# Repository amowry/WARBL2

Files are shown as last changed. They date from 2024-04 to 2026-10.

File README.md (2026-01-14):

## WARBL2 is an open-source USB MIDI and BLE MIDI wind controller.

Please see the web site for more info:

https://warbl.xyz

To power the WARBL on, plug into USB or click button 3 (lowest button).

To manually power off the WARBL while under battery power, you can click the reset button (or use a button action assigned in the Configuration Tool, which by default is a long-press of button 3).

For updating the firmware, typical users would just hold down button 1 while plugging the WARBL in to USB and then drag/drop the supplied .uf2 file to the drive named WARBLBOOT. If the WARBL is already plugged in, you can also double-click the reset button to enter the bootloader mode. The most recent flash.uf2 file is located in the build/adafruit.nrf52.warbl2 directory.
 
Advanced users can use the Arduino IDE to modify and upload the code. Modify the code at your own risk and note that while modifying the battery management code won't have dangerous results it could result in reducing the lifespan of the battery.

### How to use WARBL2 with the Arduino IDE:

#### Install Arduino IDE

* Install / run the latest version of the Arduino IDE. [You can download the latest version of the Arduino IDE here](https://www.arduino.cc/en/Main/Software).

* In Linux, the Arduino IDE requires that you be part of the `dialout` group to successfully detect and write to hardware (see [here](https://support.arduino.cc/hc/en-us/articles/4401874331410#ser_open-permission-denied)). If running `id` in a terminal does not list `dialout` as one of the groups your user belongs to, [run `sudo usermod -a -G dialout $USER`](https://support.arduino.cc/hc/en-us/articles/360016495679-Fix-port-access-on-Linux), then log out and back in. Running `id` should now include the `dialout` group.

#### Editing and uploading the WARBL firmware

*  I used the Adafruit ItsyBitsy NRF52840 Express for prototyping WARBL, so the easiest way to set up the IDE is to install the Adafruit boards package, [following the instructions here](https://learn.adafruit.com/adafruit-itsybitsy-nrf52840-express/arduino-support-setup).

* Download the WARBL2 code from this repository (I recommend using the most recent *release* code, *NOT* the current main branch), and move the boards.local.txt file from the "firmware" directory into the directory on your machine that contains the boards.txt file for the Adafruit NR52 boards, typically found here:
   
   * Windows: `C:\Users\(username)\AppData\Local\Arduino15\packages\adafruit\hardware\nrf52\1.6.0` 
   
   * Linux: `/home/(username)/.arduino15/packages/adafruit/hardware/nrf52/1.6.0`
     
   * Mac: ` ~/LibraryArduino15/packages/adafruit/hardware/nrf52/1.5.0/`

*	Now open the warbl2_firmware.ino sketch that you saved in your sketchbook folder.
  
*	In the Tools menu select: Board: > Adafruit nRF52 > WARBL2

*	Next, you’ll need to install libraries included in the sketch that aren’t installed by default. To install them, go to Sketch > Include Library > Manage Libraries, then search for the name of each, one at a time. Then it will give you an option to install each one.

*	Then turn on “show verbose ouput" for both "compile" and "upload" under File > Preferences. Now, click the upload button and check that it compiles without errors. 

*	Then, when it tries to upload, you should see this message at the bottom of the screen:

`Waiting for upload port...`

*	IF the WARBL currently has a "Release" version of the firmware (see below), you'll then have to use a toothpick to double-click the reset button to enter programming mode. The LED pulse in blue and the code should upload, which will take several seconds. If the LED doesn’t light or blinks rapidly, try again. If the IDE stops trying to upload, click “Upload” again, and try double-clicking again. It can take a few tries to get the timing right. If you've loaded a non-release version then the serial CDC port will be active and the firmware upload should proceed without having to first double-click the reset button.

### A few additional notes:
The serial CDC class on WARBL needs to be turned off to make it a USB MIDI class-compliant device. This also means that you won't be able to use the serial monitor in Arduino IDE, and you'll have to double-click the programming button to install firmware (as described above). To turn serial back on, you can comment out the following line in the sketch:

`#define RELEASE //Uncomment for release version (turns off CDC)`

Turning on CDC makes it easier to debug and makes it so uploads should proceed automatically.

Have fun!

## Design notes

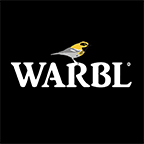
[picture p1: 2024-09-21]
webconfig/img/warbl-app-144x144.png

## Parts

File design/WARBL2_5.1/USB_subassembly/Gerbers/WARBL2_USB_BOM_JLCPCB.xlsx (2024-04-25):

Comment | Designator | Footprint
USB4145-03-0070-C_REVA | J2 | USB4145-03-0070-C_REVA

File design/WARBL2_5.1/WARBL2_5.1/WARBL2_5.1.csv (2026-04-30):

Comment | Designator | Footprint | JLCPCB Part # | Manufacturer Part # | DigiKey Part #
4.7 uF | C1,C4,C9,C10 | C_0603_1608Metric | C19666 | C1608X7S1A475K080AC | 445-14258-2-ND
0.1 uF | C2,C3,C8,C12,C13,C14,C15,C18 | C_0603_1608Metric | C14663 | CL10F104ZB8NNNC | 1276-1012-2-ND
22 uF | C6,C7 | C_0603_1608Metric | C59461 | C1608X5R1A226M080AC | 445-9077-2-ND
1uF | C11,C19,C20 | C_0603_1608Metric | C15849 | CL10B105KP8NNNC | 1276-1946-2-ND
0.01 uF | C16,C17 | C_0603_1608Metric | C57112 | CL10B103KB8NNNC | 1276-1009-2-ND
ESDA7P60-1U1M | D1 | ESDA7P601U1M | C1975146 | ESDA7P60-1U1M | 497-16253-2-ND
BAT54C | D2 | SOT-23 | C181200 | BAT54C | 1655-BAT54CTR-ND
1N4148 | D3 | D_SOD-323 | C2128 | 1N4148WS | 1655-1N4148WSTR-ND
LED_RGB | D4 | LED_LiteOn_LTST-C19HE1WT | C5289911 | APTF1616SEJ3ZGGVBDC | 754-2166-2-ND
ECMF02-2AMX6 | IC1 | QFN-6L_STM | C2651144 | ECMF02-2AMX6 | 497-10773-2-ND
1286AS-H-2R2M 2.2uH | L1 | INDC2016X120N | C412023 | 1286AS-H-2R2M=P2 | 490-10605-2-ND
1 uH | L2 | L_0603_1608Metric | C370016 | LQM18PZ1R0MCHD | 490-15979-2-ND
RU1J002YNTCL | Q1,Q2 | SOT-323_SC-70 | C2842817 | RU1J002YNTCL | RU1J002YNTCLTR-ND
5.1K | R1,R2,R3,R4 | R_0603_1608Metric | C23186 | ERJ-3EKF5101V | P5.10KHTR-ND
10k | R5,R23 | R_0603_1608Metric | C25804 | ERJ-3GEYJ103V | P10KGTR-ND
100k | R6,R12,R13 | R_0603_1608Metric | C25803 | ERJ-3GEYJ104V | P100KGTR-ND
36k 1% | R7 | R_0603_1608Metric | C100994 | ERJ-3EKF3602V | P36.0KHTR-ND
470K | R8 | R_0603_1608Metric | C23178 | ERJ-3GEYJ474V | P470KGTR-ND
100 | R9,R14 | R_0603_1608Metric | C22775 | ERJ-3GEYJ101V | P100GTR-ND
470 | R10,R11 | R_0603_1608Metric | C23179 | ERJ-3GEYJ471V | P470GTR-ND
2k | R15,R16,R17,R18,R19,R20,R21,R22 | R_0603_1608Metric | C22975 | ERJ-3GEYJ202V | P2.0KGTR-ND
2.74k 1% | R25 | R_0603_1608Metric | C321827 | ERJ-3EKF2741V | P2.74KHTR-ND
47k 1% | R26 | R_0603_1608Metric | C25819 | ERJ-3EKF4702V | P47.0KHTR-ND
Tact switch | SW1,SW2,SW3 | TL3305BF160QG | C2689518 | PTS647SM50SMTR2LFSTR-ND | PTS647SM50SMTR2LFSTR-ND
RESET | SW4 | SW_KMR221GLFS | C221675 | KMR211GLFS | 401-1426-2-ND
NCU18XH103F60RB | TH1 | R_0603_1608Metric | C440252 | NCU18XH103F60RB | 2259-TH11-3H103FTTR-ND
M24128-BFMH6TG EEPROM | U1 | UFDFPN5_1P7X1P4_STM | C222091 | M24128-BFMH6TG | 497-17565-2-ND
LSM6DSOXTR IMU | U2 | LGA-14L_2P5X3X0P83_STM | C481766 | LSM6DSOXTR | 497-18367-2-ND
SLG59M1551V Load switch | U3 | VLGA-4_2x2.5mm_P1.65mm | C17446756 | SLG59M1551V | 1827-1074-2-ND
TPS613221ADBV 3.3V boost | U4 | DBV0005A_L | C2070813 | TPS613221ADBVT | 296-49467-2-ND
BQ25172DSGR | U5 | WSON8_DSG008A_BQ_TEX | C5189434 | BQ25172DSGR | 296-BQ25172DSGRTR-ND
TPS7A2030PDBVR | U6 | DBV0005A_L | C963429 | TPS7A2030PDBVR | 296-TPS7A2030PDBVRTR-ND
ISP1807-LR-RS | U7 | ISP1807-LR-RS | C5264268 | ISP1807-LR-RS | 1786-1019-2-ND
74AUP1G32 | U8 | DSF6 | C2682134 | SN74AUP1G32DSFR | 296-27310-2-ND
TPS62237DRYR | U9 | DRY0006A | C398923 | TPS62237DRYR | 296-39454-2-ND
ATmega32U4-MU | U18 | QFN-44-1EP_7x7mm_P0.5mm_EP5.2x5.2mm | C112161 | ATMEGA32U4-MUR | ATMEGA32U4-MURTR-ND
MMC5603NJ Magnetometer | U19 | WLP-4_0.86x0.86mm_P0.4mm
8 Mhz CSTNE8M00GH5L000R0 | Y1 | CSTNE8M00GH5L000R0_MUR | C882602 | CSTNE8M00GH5L000R0 | 490-17962-2-ND

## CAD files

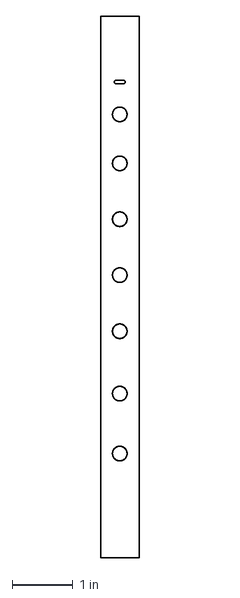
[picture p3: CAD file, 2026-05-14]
design/WARBL2_rev.5.1_top_hole_spacing.dxf
0.625 x 8.90 in

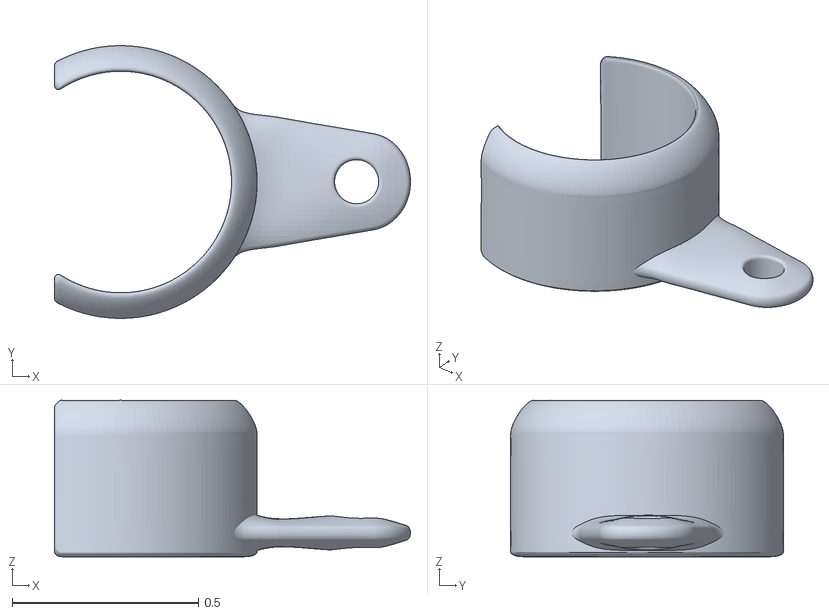
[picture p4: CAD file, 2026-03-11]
design/WARBL_offset_thumbrest_1.0.stl
0.956 x 0.733 x 0.42

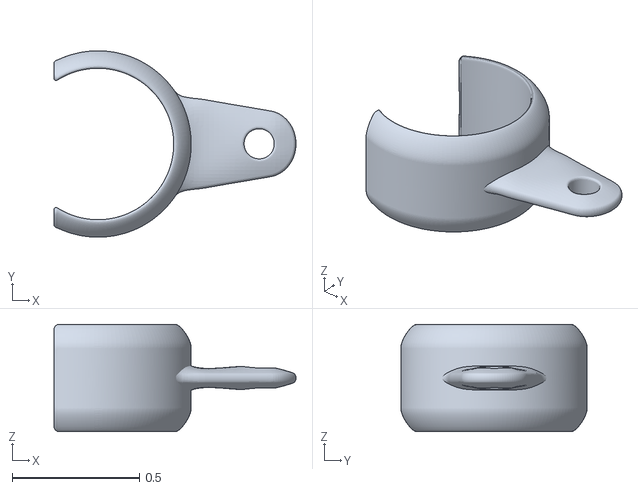
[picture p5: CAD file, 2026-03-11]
design/WARBL_thumbrest_1.0.stl
0.951 x 0.733 x 0.421

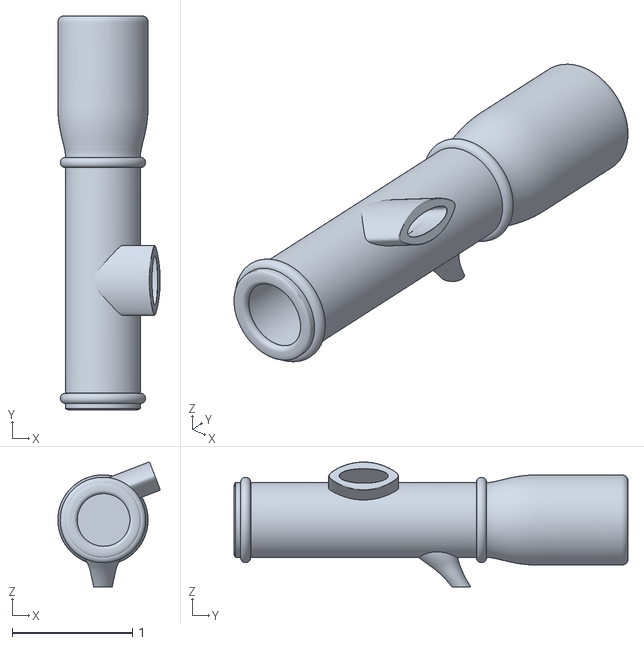
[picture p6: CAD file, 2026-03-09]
design/WARBL_transverse_mouthpiece_3.0.stl
0.851 x 3.27 x 1.04

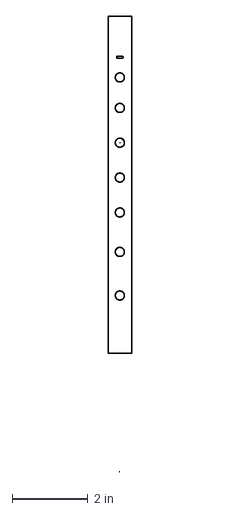
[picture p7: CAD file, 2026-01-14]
design/WARBL2 enclosure.dxf
0.625 x 12.0 in

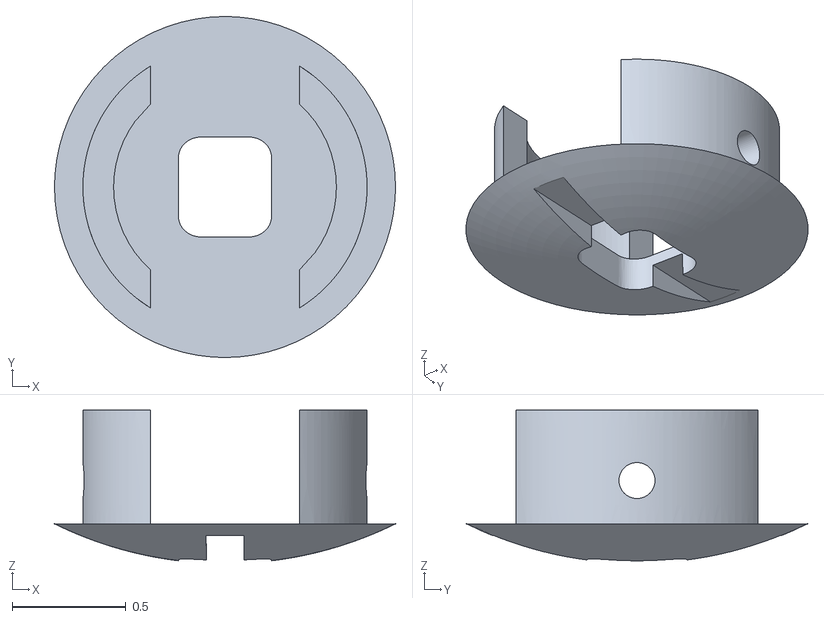
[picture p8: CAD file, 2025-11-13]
design/WARBL2_end_cap.stl
1.50 x 1.50 x 0.663

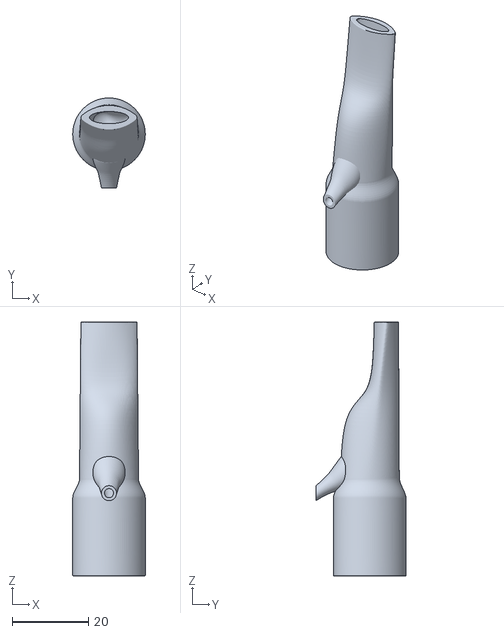
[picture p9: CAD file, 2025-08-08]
design/WARBL_mouthpiece_9.0_mm.stl
19.0 x 23.7 x 66.7

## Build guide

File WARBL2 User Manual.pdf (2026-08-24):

2

# User Manual

Firmware version 4.7.0

August 24th, 2026

1. Introduction
2. Basic Operation
3. Battery information and charging
4. Optical sensors
5. Pressure sensor and mouthpiece
6. MIDI module options and setup USB MIDI
BLE MIDI
BLE latency
MIDI Apps
7. Customization with the WARBL Configuration Tool Introduction
Top Controls
Custom Fingering Configuration
Note Trigger and Register Control Advanced Overblowing Settings Finger Vibrato and Slide
Advanced Pitch Bend Settings
Pressure mapping
Pitch Expression Pressure Range Override
Mapping CC, Velocity, Channel Pressure, and Key Pressure IMU mapping
Drones Control
Button Behavior
Optical Sensor Calibration
WARBL2 Settings
Preset Import/Export
8. Using bagpipe bags and the optional bell sensor
9. Care and maintenance
10. Updating the firmware
11. LED Indication
12. Replacing the battery
13. Troubleshooting
Warranty
Technical Data

## 1. Introduction

WARBL2

is a USB-MIDI and BLE-MIDI wind controller, designed to simulate traditional open-tone-hole instruments like tin whistles, flutes, and bagpipes. WARBL2 makes no sound by itself, instead sending MIDI messages to a MIDI module app or dedicated hardware MIDI module. This gives you complete and unlimited control over the sound.

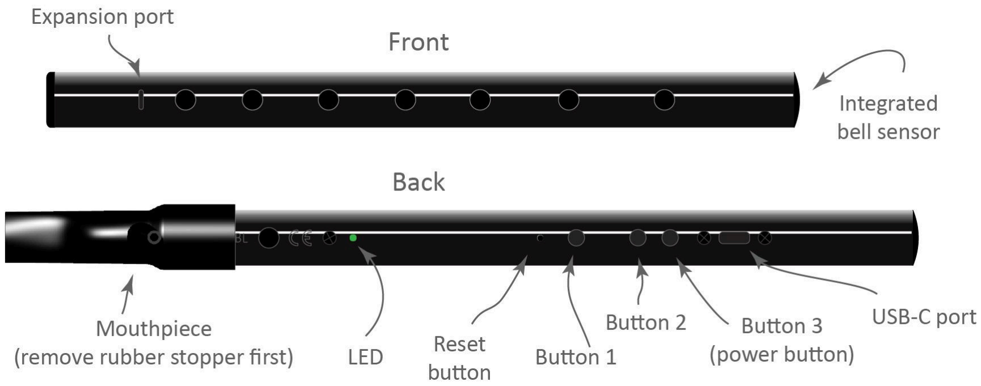
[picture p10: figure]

WARBL2 has nine optical tone-hole sensors, a pressure sensor, three buttons, and an LED indicator. The buttons are numbered 1, 2, and 3 from the top (mouthpiece) end of the device.

There is also a reset button under the small hole in the back of the enclosure. It can be clicked using a toothpick to reset the device (or power it down if under battery power) and can be double-clicked to enter programming mode for updating the firmware.

WARBL2

is highly customizable using the WARBL Configuration Tool, which is a web page accessible with a browser (most devices) or the WARBL app (iOS).

WARBL2

, introduced in 2024, includes a number of additions and improvements from the original WARBL. These include BLE MIDI, an inertial measurement unit (IMU: accelerometer and gyroscope), USB-C, an integrated bell sensor, an RGB LED, a faster processor with much greater storage space, a secondary processor dedicated to reading the optical sensors, higher-resolution pressure-sensor readings, lower power consumption, drag-and-drop firmware upgrades, slightly larger toneholes, and the ability to customize fingering charts completely.

WARBL2 also has an expansion port for future upgrades or for use by end users who are proficient with electronics and coding. The WARBL2 code contains detailed information about the expansion port.

## 2. Basic Operation

To power on WARBL2 either click button 3 once or plug into USB power (a charging brick or a USB host device such as a computer, tablet, or phone). When plugged into a host device, WARBL2 should appear as a USB MIDI device. To plug into a device that doesn’t have a USB port (like an iPhone with a Lightning port) or to add a headphone jack to your device, you may need an adapter. Please see the WARBL FAQ page (https://warbl.xyz/FAQ.html) for adapter suggestions.

To power down WARBL2 when under battery power, hold down button 3 for approximately 3 seconds (this is the default behavior but it can be changed using the WARBL Configuration Tool–see section 7). By default the WARBL2 will also power itself down after 5 minutes of inactivity (that can also be changed using the Configuration Tool).

To power down the WARBL2 when powered by USB, simply unplug it.

Note: When storing the WARBL2

, ensure that the power button (button 3) isn’t continuously pressed, for example by a tight-fitting storage container. This will cause the device to stay powered on and will drain the battery.

## 3. Battery information and charging

The rechargeable battery is a 1.2 V, 400 mAH ⅔ AAA NiMH cell. The battery should allow for at least 10 hours of playing time per charge and should have a lifespan of at least a few years (likely several years). It can be replaced by the consumer at the end of its lifespan (see section 11). Replacement batteries are available in most countries or can be ordered from the WARBL website. The advantage of NiMH batteries over lithium ones is that they are safer (less flammable) and can easily be shipped overseas.

The battery voltage and charge percentage are shown in the Configuration Tool. There is also an option to program a button action that will cause the LED to flash a number of times corresponding to the charge percentage (see section 7).

To charge the WARBL2

, plug it into a good-quality USB charging brick or a USB host device as described above. The battery will begin charging if the battery voltage is lower than approximately 1.35 V. Charging is indicated by a pulsing red LED and there will be a charging icon next to the battery-level indicator in the Configuration Tool. The LED will turn solid green when charging is complete. A fully depleted battery will take approximately 3 hours to charge fully. The
WARBL2 may get slightly warm while charging. It is okay to play the WARBL2 while charging. A sophisticated charging algorithm is used to constantly monitor the battery voltage and temperature to ensure safe charging and prolong battery life.

Charging from a USB host can be turned off in the Configuration Tool (section 7), which is recommended if you are using USB MIDI and the WARBL2

is often
connected to a host. While charging, the WARBL2 will draw 100 mA of current and may run down a phone battery. If this option is turned off, the WARBL2 will only charge from a charging brick.

The WARBL will only begin charging if the battery voltage is lower than approximately 1.35 V. Other than that it can be charged at any time, but to calibrate the battery level monitor it is a good idea to occasionally use the WARBL2 until the battery dies (when the battery voltage drops to 1.0 V the LED will illuminate red for 5 seconds and the WARBL will shut down) and also occasionally charge the WARBL2 completely (until the LED turns green). It is also a good idea to fully charge the battery when you first receive the WARBL2. The battery level is an estimate based on your playing habits, and it is not guaranteed to be accurate.

If you are not using the WARBL2 often, it is a good idea to charge it every several months to help extend the life of the battery.

## 4. Optical sensors

The infrared optical sensors detect the distance of your fingers from the tone holes. The device uses this information to send MIDI pitch-bend messages, and to determine whether each hole is covered. The sensors may require occasional cleaning (see section 9) and calibration (see section 7). Although the device has been calibrated once when new, you will likely need to calibrate it to your own fingers.

Because they use infrared light, the sensors work well in most lighting conditions (including complete darkness). Outdoors in extremely bright sunlight, the effectiveness of the sensors may be impaired. If this occurs it may be necessary to turn away from the sun or play in a shady location. For best results, ensure that your hands are clean and dry. Oils on your hands may be invisible to you but still affect the reflectivity of your fingers in the infrared range. Recalibrating the sensors will fix most issues that arise, including if you are wearing gloves or have a bandage on a finger.

The integrated bell sensor is an additional infrared sensor designed to allow uilleann pipes players to play “on the knee”, stopping all sound when the bell sensor and all of the tone hole sensors are covered. This works with all fingering charts, not only the uilleann pipes chart. The bell sensor may also be used for vibrato.

## 5. Pressure sensor and mouthpiece

The pressure sensor measures the pressure from your breath or a bagpipe bag. The sensor is compensated for temperature and is quite precise. It can detect a maximum pressure of about 6 kPa (about 24 inches of water).

The mouthpiece is made of tough food-safe nylon, and is designed to direct air and moisture downward while allowing WARBL2

to sense the breath pressure. To install it, first remove the rubber stopper from WARBL2

, and push and twist the
mouthpiece in place (it doesn’t need to be too tight). It has a tapered fit. To clean and sterilize the mouthpiece, you can use soapy water and/or boil it in water.

The mouthpiece exhausts excessive moisture out of the small “nozzle”. If you have any issues with moisture running down the back of the mouthpiece rather than dripping away, it helps to apply a small amount of silicone grease on the nozzle as shown below.

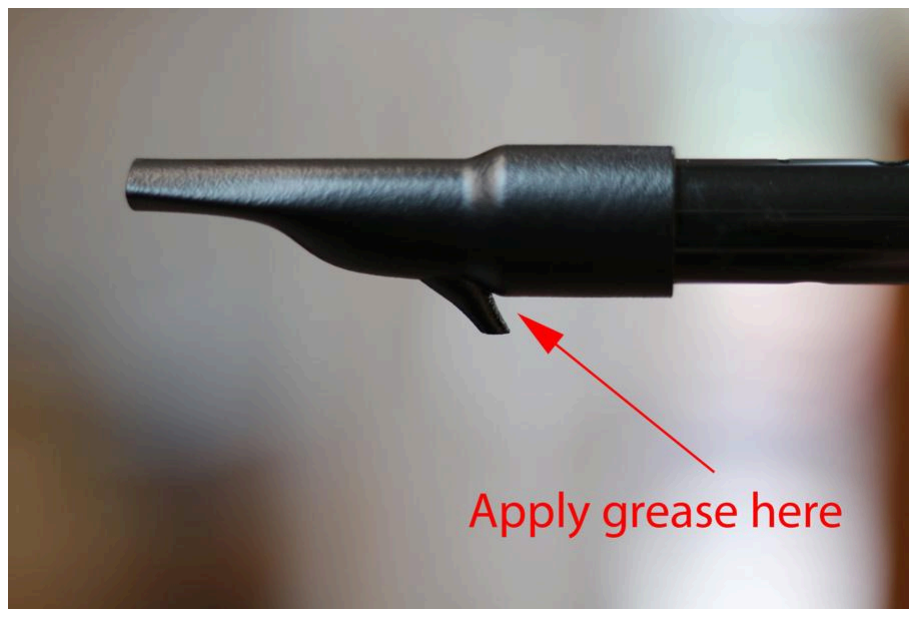
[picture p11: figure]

Please see section 8 for using a bagpipe bag instead of a mouthpiece.

## 6. MIDI module options and setup

The WARBL2 doesn’t produce any sound on its own and must be connected to a host device running a MIDI app that will produce the sound. Most mobile devices and computers can be used as MIDI host devices (either USB MIDI or BLE MIDI). IOS devices work especially well because they have relatively low audio latency and there are many low-cost MIDI app options. While many WARBL owners use Android devices, they are not generally recommended for MIDI because they can have higher latency.

For more advanced users, hardware MIDI Modules are another option for producing sound. The EaganMatrix Micro (https://www.hakenaudio.com/eaganmatrix-micro) was designed to use with the WARBL and is a good option.

## USB MIDI

The WARBL2 should be recognized as a USB-MIDI device when plugged into a host device. Plugging WARBL2

into mobile devices may require an adapter. Please see the WARBL FAQ page (https://warbl.xyz/FAQ.html) for up-to-date information on adapters for specific devices. Many new mobile devices have a USB-C port, in which case you can simply use a cable with USB-C plugs on both ends to connect the WARBL2 However, if your device doesn’t have a headphone jack and you’d like to add one, you may need an adapter or USB-C hub to do that.

## BLE MIDI

WARBL2 can communicate wirelessly with many host devices using BLE MIDI. BLE MIDI is a short-range protocol and the maximum range is approximately 30 feet (roughly 10 meters). At longer distances latency may increase and notes may begin to drop out.

iOS Devices

On iOS devices, the WARBL2 should reconnect automatically each time it is turned on. To pair the device the first time, you can use the WARBL app or any other MIDI app that includes the ability to pair BLE devices Korg BLE-MIDI Connect (https://apps.apple.com/us/app/bluetooth-midi-connect/id1108321791) or MIDI Wrench (https://apps.apple.com/uy/app/midi-wrench/id589243566) (both free).

To pair the WARBL2

in the WARBL app (shown below), click on “BLE MIDI” at the top. The WARBL2 should be visible in the list of devices if it is turned on and within range. Click on the “WARBL” listing and then click “pair” when prompted.

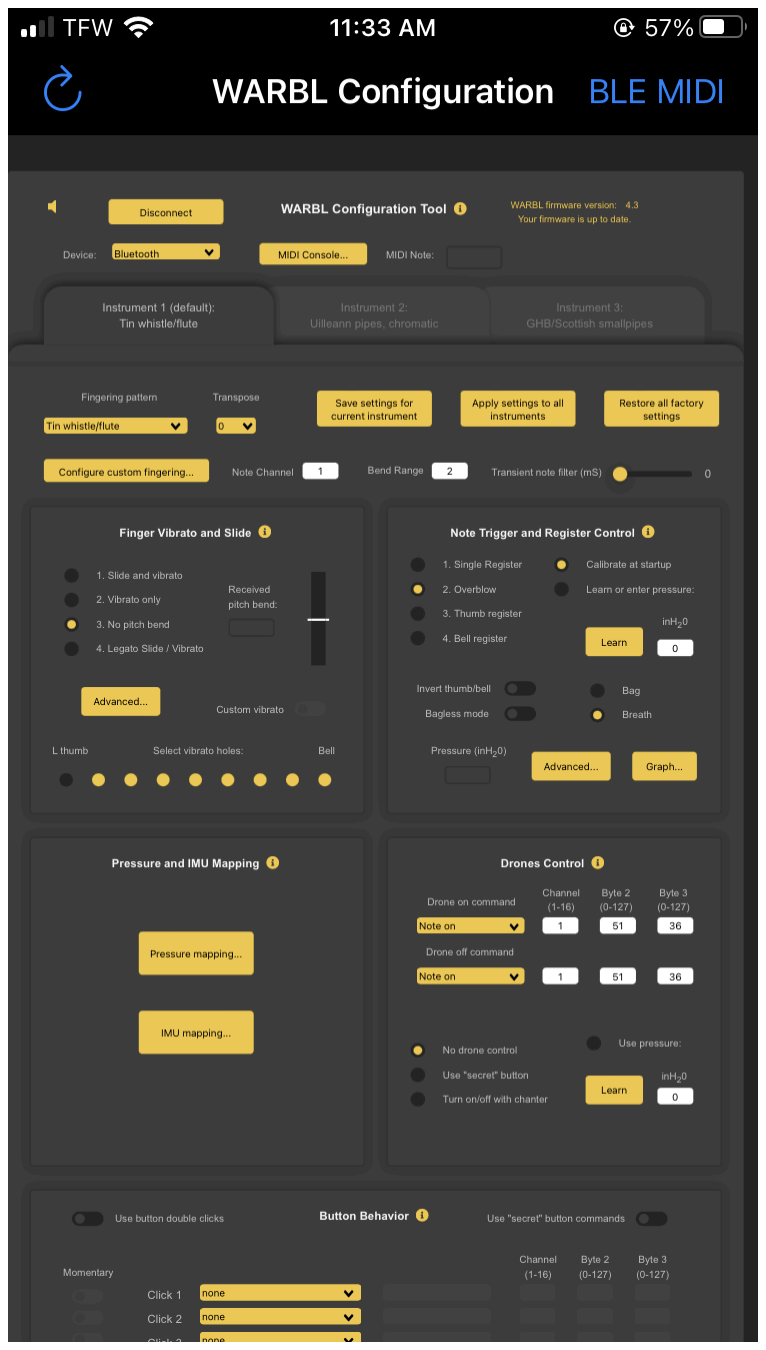
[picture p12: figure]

Once paired, the WARBL2 should work with any MIDI app, for example the WARBL app or Celtic Sounds MIDI Module. You should be able to simply turn on the WARBL2, open a MIDI app, and begin playing. You should only have to pair the WARBL2 again if it becomes “forgotten”. If you have any trouble reconnecting the WARBL2 you can “forget” it in your device’s settings and then pair it again.

Windows machines

Not all Windows machines have built-in support for BLE devices, but most newer ones do. If yours doesn’t you can buy a BLE dongle to add that functionality. On Windows, a helper app is currently required to make BLE-MIDI devices appear seamlessly as normal MIDI devices. Microsoft is currently working on making this more seamless, but it may be a year or so before that is complete. In the meantime, I highly recommend the PerfectBluetoothMIDI app. To use it, download the latest “perfectBluetoothMidi.exe” file from this page. (https://github.com/mayerwin/Perfect-Bluetooth-MIDI-For-Windows/releases/) You can put this anywhere on your machine, but if you’d like it to run automatically at startup (recommended), put it in your Windows startup folder. Then double-click it to run it manually the first time. Next, turn the WARBL2 on, make sure Bluetooth is turned on on your machine. There should be a device shown in the “Bluetooth MIDI Device” list. Select that and click “Connect”. The WARBL2 should connect and then reconnect automatically each time you turn it on. If you have the app in your startup folder and you don’t want it to be visible after startup, you can select the option in the settings to “automatically minimise to the system tray”.

Another great option for connecting to Windows is to use a CME WIDI Bud Pro (https://www.cme-pro.com/product/widi-bud-pro/) adapter. This plugs into a USB port, connects reliably to the WARBL2

, and shows
up as a USB MIDI device on your computer.

Note: On older versions of Windows, only one app is able to connect to a MIDI device at a time. So, if you’ve been connected to the Configuration Tool you’ll need to close your web browser before you can connect to a MIDI app, and vice versa.

Mac OS

To connect the WARBL2

to a Mac, you can follow the directions in this link (https://support.apple.com/guide/audio-midi-setup/set-up-bluetooth-midi-devices-ams33f013765/mac) to “Make your Mac a Bluetooth Host”.

Android

MIDI apps on Android like FluidSynth and BS-16i should be able to connect directly to the WARBL2

, but if this doesn’t work it’s possible that a helper app like MIDI Connector (https://play.google.com/store/apps/details?id=com.awisman.midiconnectorfree&hl=en_US) or BLE Connect (https://play.google.com/store/apps/details?id=com.mobileer.example.midibtlepairing&hl=en_US) will help.

If you experience issues with BLE MIDI not connecting correctly on any device, a solution is often to have your device “forget” the WARBL2 and then reconnect to it.

Important: The WARBL2

is capable of connecting by both USB MIDI and BLE MIDI simultaneously. While this can be useful in some cases (e.g. sending messages to two different devices), it can also be a cause for confusion. You can choose in the Configuration Tool whether to send MIDI notes to either USB or BLE, or you may simply wish to turn off BLE on your devices if you are using USB MIDI with the WARBL2. In general, it is not a good idea to be sending both BLE and USB MIDI messages simultaneously to a single device.

## BLE latency

BLE MIDI adds a small amount of latency (delay). On most devices this is imperceptible or nearly so, but for the absolute lowest latency you may choose to use USB MIDI instead. On newer devices, the average added BLE latency is usually around 4-8 milliseconds (a BLE connection interval of 7.5 - 15 ms). The BLE connection interval is shown in the Configuration Tool.

For comparison, 8 milliseconds of latency is the amount of time needed for sound to travel 8 feet, so it is the equivalent of standing 8 feet away from an audio source. In fact, for keeping perceived latency to an absolute minimum it is recommended to be close to your audio source (speakers) because just standing several feet from speakers will effectively double the overall latency.

Having the WARBL2 connected to the Configuration Tool may also add a very small amount of latency because it necessitates sending additional data wirelessly. You can click “Disconnect” in the Configuration Tool when done using it to avoid this.

Note that there are many other sources of latency. If you are experiencing a large amount of latency, it's very likely the result of audio latency associated with your host device, rather than BLE. A few things to check are:

- Are you using Bluetooth headphones or speakers? These always add a large amount of latency and can't be used with live music performance (Bluetooth audio is much slower than BLE MIDI). You'll need to use wired headphones or speakers.
- Are you using a Windows machine? If so, try selecting different audio drivers in your MIDI app settings, and possibly install the free ASIO4All audio driver.
- Are you using an Android device? Some of these have a lot of audio latency and there may not be a solution for this. I'm happy to accept returns if you are unable to attain acceptable results with your Android device.

The CME WIDI Bud Pro (https://www.cme-pro.com/product/widi-bud-pro/) adapter is a great way to ensure that the WARBL2 connects with a 7.5 ms interval (the fastest currently possible).

## MIDI Apps

The WARBL Configuration Tool now has built-in audio with several instrument sounds available. However, this is mostly meant for testing purposes or informal playing, and it’s generally better to use a dedicated MIDI app or synth.

Some recommended iOS MIDI module apps are Appcordians Celtic Sounds MIDI Module (https://itunes.apple.com/us/app/celtic-sounds-midi-module/id1403026032?ls=1&mt=8) (or other Appcordians MIDI apps), (http://appcordions.com/midi/) Thumbjam, (https://itunes.apple.com/us/app/thumbjam/id338977566?mt=8) and SoundFonts. (https://apps.apple.com/us/app/soundfonts/id1453325077) WARBL2 normally sends melody (chanter) notes on MIDI channel 1, which most apps will listen to by default. If the app allows control over the maximum pitch bend, it should be set to two semitones. This is the default for many apps. Some apps allow “background play”, meaning that the app will continue to play after it is closed. This allows using multiple apps simultaneously, producing the sound of multiple instruments at once. It also allows you to use the WARBL Configuration Tool simultaneously with a MIDI module app.

For platforms other than iOS, there are two new Web pages by Michael Eskin that connect to the WARBL (much like the Configuration Tool does) and supply high-quality audio in a web browser like Chrome that supports Web MIDI. They are Celtic Sounds (web version) (https://michaeleskin.com/celtic-sounds/celtic-sounds.html) and the WARBL Sound Lab. (https://michaeleskin.com/warbl-sound-lab/warbl-sound-lab.html?)

For Android devices, the BS-16i (https://play.google.com/store/apps/details?id=jp.bismark.bs16i&hl=en_US) or FluidSynth (https://play.google.com/store/apps/details?id=net.volcanomobile.fluidsynthmidi&hl=en_US&gl=US) apps are recommended (BS-16i has more features and a better user interface). On Windows and Mac, SForzando (https://www.plogue.com/products/sforzando.html) can work well. These apps all play SoundFonts and you can download the WARBL SoundFont (https://warbl.xyz/phpbb/viewtopic.php?f=7&t=307) for playing whistle, flute, uilleann pipes, highland pipes, and smallpipes sounds. For bagpipes sounds on Windows and

Mac, Universal Piper (https://www.universal-piper.com/en/the-virtual-bagpipe-lab/) is excellent. There are many other free SoundFonts on the web if there are other instrument sounds you’d like to make with the WARBL2

Note: MIDI apps that are open “in the background” continue to use battery life, so it’s a good idea to force them to close after you are done playing (here’s how to force-close an app on iOS). (https://support.apple.com/en-us/109359)

## Hardware Synths

The EaganMatrix Micro (https://www.hakenaudio.com/eaganmatrix-micro-introduction) sound engine is a compact hardware synth that was designed specifically for use with the WARBL. The web site has a demo video and information about how to use it. It is great for more advanced/demanding users and has exceptional sound quality.

Most other MIDI hardware synths should also work with the WARBL2

On the WARBL Forum there is a growing list of presets available to help set the WARBL up with appropriate settings for various apps and synths.

## 7. Customization with the WARBL Configuration

## Tool

## Introduction

The Configuration Tool is a web page that connects to WARBL2 using MIDI protocol to let you customize settings. This section is organized to correspond with the panels in the Configuration Tool, and most of the information in this section is also available in the Configuration Tool by clicking on the yellow “info” icons.

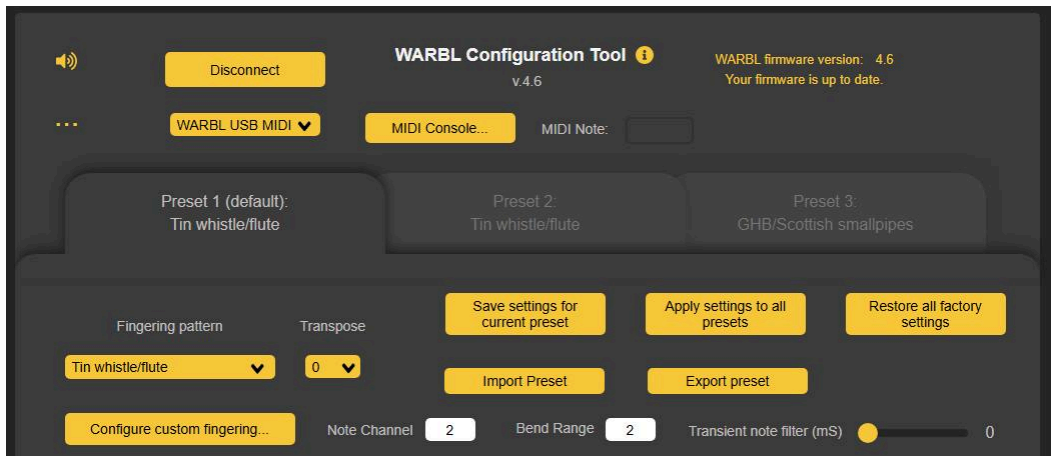
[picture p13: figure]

Because the Configuration Tool uses the relatively new Web MIDI protocol, It is necessary to use a browser that supports Web MIDI, which currently includes Chrome, Firefox, and Opera on Windows, Mac, Linux, Chromebook, or Android.

Safari unfortunately does not yet support Web MIDI, but on iOS devices you can use the free WARBL app, (https://itunes.apple.com/us/app/warbl-configuration-tool/id1445377915?mt=8) generously made by Michael Eskin of Appcordions.

The Configuration Tool will try to connect to WARBL2

if it is already plugged in or connected by BLE MIDI when the page is loaded, or you can click Connect to WARBL if it hasn’t connected automatically. Once it has connected, it should show your firmware version in the upper right corner, and it will tell you if there is a firmware update available (see section 10 for updating the firmware). NOTE: If your firmware is not up to date, you will be able to use the Configuration Tool normally, but some options may be missing or disabled (shown in gray).

## Top Controls

WARBL2 has three "presets" available for use at any time. Each preset consists of a fingering pattern and a set of associated settings. You can select different fingering patterns for each preset, or you can select the same fingering pattern for more than one preset. For example, if you only want to use tin whistle fingering, you can select that option for all three presets, but still have three different sets of settings available at any time. You may want to have the buttons configured differently for each preset, for example, or have different register control and/or slide/vibrato settings.

Selecting the tab for each preset allows you to change the settings for that preset. Please note that WARBL2

responds immediately to changes to settings for each preset, but if you don't save them, those changes will be lost when you power down WARBL2

. You can choose to apply changes to settings to the current preset (by clicking Save settings for current preset), or you can choose to apply them to all three presets (click Apply to all presets).This can be useful if you want to make three presets that are the same except for minor differences (which can be changed after applying the initial settings to all three presets). You can also restore the factory settings. This will put the WARBL2

in the same
state as when you received it, including the factory sensor calibration.

You can set the Default preset that will be active when WARBL is plugged in. This prevents having to click a button to switch presets if your current favorite preset is not preset 1. To set the default preset, simply click the tab for that preset and then click Set as Default. This change will be saved immediately. For advanced users: To tell the WARBL to switch between presets, you can send Program Change (PC) messages 1, 2, or 3 on any MIDI channel from another device.

The Preset Import and Export buttons allow you to exchange your WARBL preset settings with other users or to archive settings for one preset for later import back into the WARBL Configuration Tool. On the WARBL Forum there is a growing list of presets available to help set the WARBL up with appropriate settings for various apps and synths.

WARBL settings for the currently selected preset may be exported to a file using the Export Preset button.

The exported file will be named "WARBL_Preset.warbl" and can be found in the "Downloads" directory on your computer or typically in the Files app in iOS. If there is already an existing export file in that directory, Chrome will save the file with incrementing numbers after the "WARBL_Preset" name.

To load an existing WARBL preset file into the current preset tab, click the Import Preset file selector button.

Select a .warbl settings file from your computer to import. The imported data will be loaded into your WARBL, but not saved permanently to allow you to make additional changes if desired.

To permanently save the settings for the current preset in your WARBL, click the "Save settings for the current preset" button at the top of the screen.

Note: It is not possible to import settings from an original WARBL to a WARBL2 or vice versa because they use different commands for communicating with the Configuration Tool.

The MIDI note display will show what MIDI note is currently being played, and the MIDI Console will show the most recent 300 MIDI messages that have been received. These are both useful for troubleshooting.

The Fingering pattern dropdown menu allows you to choose a fingering chart. Information about each chart is available on the Documentation (https://warbl.xyz/documentation.html) web page. Note that there are four Custom charts available at the bottom of the list (see Custom Fingering Configuration below).

The Transpose menu allows you to change keys. If this is set to 0 (the default) then the selected fingering chart will produce the notes shown in the documentation. You can transpose up or down as much as 18 semitones to play in different keys. Most MIDI apps also allow transposing the received MIDI notes, and often it is simpler to do this in the MIDI app rather than in the Configuration Tool.

The Note channel input allows you to select the MIDI channel (1-16) used for sending notes from WARBL. This should typically be left set to "1".

The Bend Range setting is the number of semitones of pitch bend that the WARBL will allow. This should typically be set to the default value of 2.

The Transient note filter filters out very brief unwanted notes by adding a small delay to the tonehole sensors. This can be particularly useful when using note annotation software to transcribe your playing. Without the filter, there can be very brief notes that you might not necessarily hear but that will be transcribed. The filter can also be used to "clean up" the sound of your playing by removing "crossing noises" that occur while changing from one fingering pattern to another. Be aware, however, that because the filter works by adding a delay, setting it too high will give a "sluggish" feel. Set it to "0" for the fastest possible tonehole response.

## Audio player

The Configuration Tool now contains an audio player with several instrument

sounds available. To turn on the audio, click the button in the top left corner of the Configuration Tool. To select the instrument sound and other settings, click the “...” button directly below.

The audio is mostly for testing purposes, and a standalone app is generally recommended for the best sound quality. Note: on iOS devices, you might not hear the audio if the Do Not Disturb switch is turned on. If you are not hearing sound, use the Test Audio button to determine if the problem is with the audio output or your WARBL settings.

The audio will respond to CC2, CC7, CC11, or channel pressure messages for controlling loudness. If no expression messages are received for two seconds while a note is playing, loudness will be reset to the maximum.

The Transpose (semitones) can be used to change the key of the audio. If you are using bagpipes sounds, use this rather than the other Transpose selector next to the Fingering Pattern menu, because this will keep the drones in tune with the chanter. This only affects the audio output here, not the MIDI notes that the WARBL is sending. Note: Transposing the uilleann pipes sound lower than -7 semitones is not recommended because it then extends into the drones range and low notes will cause the drones to play.

The bagpipes contain drone sounds that can be turned on by using the Drones panel to a MIDI Note On message (any note lower than 55). They are turned off by sending a Note Off message for the same note number, or a Note On message with a velocity of 0 (byte 3 in the drones panel). To ensure that the drones don't respond to pitchbend messages, you can use a different channel for drones than the main note (chanter) channel.

The MIDI pitchbend range in the audio player is automatically synced with the Bend Range in the current WARBL preset.

To reset the audio, use the button to turn it off and then on again.

## Custom Fingering Configuration

WARBL2 has the ability to store up to four completely customizable fingering charts. Each chart contains MIDI notes for every possible combination of the 8 tone holes (the bell sensor is not used). There are 256 such possible combinations. To upload a custom fingering chart to the WARBL2

, click
Configure custom fingering…. The screen below is displayed.

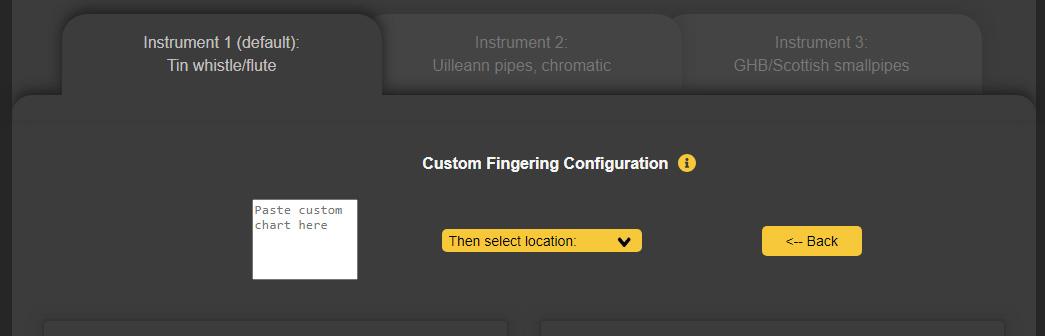
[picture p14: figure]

You will be pasting a list of 256 MIDI notes into the field at the left. To create your custom fingering chart, there is a special Google Sheet available. Follow this link (https://docs.google.com/spreadsheets/d/1TiOm5iydLx7kXBsjmasravbg9PUEOyIMRFGYa4KknoA/edit) to access the sheet (shown below). You don’t have to use this sheet but it helps simplify the process of making a chart. You’ll need to save your own copy of the sheet in order to edit it.

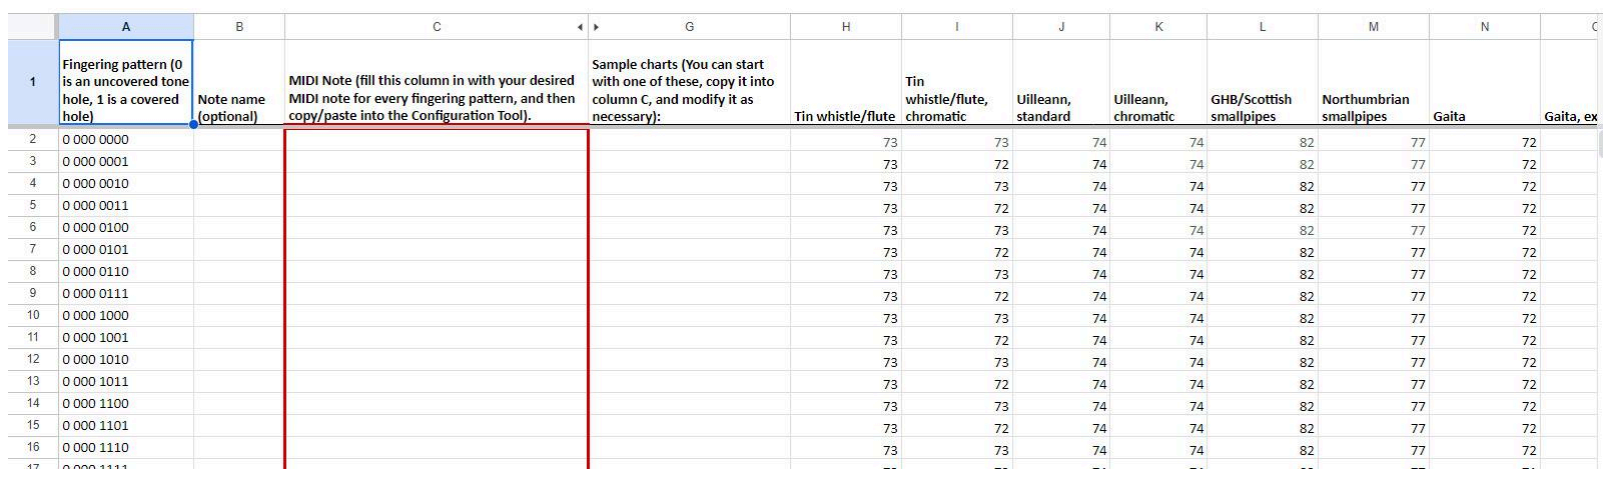
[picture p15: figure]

Column A lists all possible fingering combinations (0 represents an open hole and 1 represents a closed hole). You will need to enter a MIDI note number (0-127) in column C for each fingering combination. This is less tedious than it sounds because many will be duplicates– you can enter MIDI notes for the “normal” fingerings and then autofill empty cells below each normal fingering. Notice that for reference the MIDI notes for all the “standard” fingering charts are shown starting in column H. You can choose to modify an existing chart by copying the values from it into column C and then editing it as desired.

If you’d like you can save a copy of the Google sheet for your own use. It may be a good idea to do this or copy your custom MIDI values into another document so you have a record of them.

Once you have filled in all 256 in column C, select all of those values and copy them. Returning to the Configuration Tool, paste the values into the field at the left. Next, select one of four custom charts in the center dropdown menu as the location for saving a chart (if you have previously saved a chart in this same location it will be overwritten). It will take several seconds to load the new chart onto the WARBL2

. After you have done this, click Back and then select your custom chart from the Fingering Pattern dropdown menu (and save changes if desired).

## Note Trigger and Register Control

You can play in a single register or choose from several options for controlling the register. Choosing 1. Single register will allow you to use breath or bag pressure to start/stop notes, but will only allow access to one register. The pressure sensor can be used to mimic the way that whistles, flutes, and some bagpipes can be "overblown" to reach the second octave. To use this feature, select 2. Overblow. For fingering patterns that don't use the left thumb, you can instead select 3. Thumb register to allow you to use that finger to control the register, which will be familiar to players of many woodwind instruments. To play the upper register, simply uncover the thumb hole. Note: With the Thumb register option selected (with or without using the thumb for half holes), if you are using a custom fingering chart, the thumb position in your chart will be ignored and only the first half of the chart will be used. You do need to have values in the second half of the chart (the part with the thumb hole covered), but those values will be ignored.

Finally, you can use the bell sensor to select the register by choosing 4. Bell register. Uncovering the bell sensor (lifting it off your knee), will access the second register. The functionality for either the thumb register or bell register options can be reversed by turning on the Invert thumb/bell switch. Then covering the left thumb hole or covering the bell sensor will allow playing in the second register, depending on whether option 3 or 4 is selected. In the case of the thumb hole, this will be more familiar to players of instruments with a register key.

Starting with firmware v. 4.4, you can select the number of semitones in a register. The default is 12, which means that all three above methods of controlling the register will change the pitch by one octave. You can change this to any number of semitones (up to 24), which is useful for emulating wind instruments like the kaval that naturally overblow at an interval less than an octave. It also can serve other purposes, like playing accidentals using the above methods.

Note you can also use the IMU (elevation angle) to control the register. This is discussed in the Pressure and IMU Mapping section.

Turning on Bagless mode will allow you to configure a button to start/stop the sound instead of using the pressure sensor. This will be similar to many electronic bagpipe chanters that don't use pressure sensing. If you choose you can still select one of the options for controlling the register when using bagless mode. Note: if you choose the bagless option you must also configure a button to Play/stop (bagless mode).

The pressure sensor will normally be calibrated at startup, meaning that the pressure when you power on the device will be used as a basepoint for determining the pressure level at which sound will be triggered. This is desirable if you are using breath to control the instrument. If you are using a bag with this setting, you will want to squeeze the bag when you power on WARBL2

to "tell" it
the pressure at which you want notes to begin playing. Alternatively, you can select Learn or enter pressure to use a different pressure. This is usually preferable if you are using a bag instead of breath, and you want to trigger notes at a higher pressure. You can squeeze the bag at the pressure that you would like to use for initial triggering of sound and then click Learn, which will cause WARBL2

to use the current pressure (as with all settings, you can save this pressure by saving the settings for the current preset). After clicking "Learn", the pressure input cell will flash green and the learned pressure will be displayed. You can also enter the desired pressure manually if you prefer. Simply type in a pressure between 0.0 and 24.0 (inches water) and hit return or enter. The input cell will momentarily turn green to indicate that the pressure setting was sent to WARBL2

Selecting Bag will cause the overblowing settings for bagpipe bags to be used, while selecting Breath will cause the settings for breath (mouthpiece) to be used. These settings are customizable using the Advanced panel if desired (please see the help file within the Advanced panel for information about these settings).

## Advanced Overblowing Settings

These settings control the way that the register is changed by overblowing. Each variable below has a setting for a bag and one for the breath (mouthpiece). which settings are used depends on whether you currently have Bag or Breath selected in the main Note Trigger and Register Control panel (the currently selected group of settings are surrounded by a white box). The variables that are most likely to need adjustment are located near the top. Clicking the Bag defaults button will restore the default bag settings for all variables in the panel, and clicking the Breath defaults button will restore the default settings for breath. Units are not shown for some of these settings because they use arbitrary units.

Threshold represents how much pressure is required to move from the first register to the second register. Increasing this setting gives you more control over the registers but also makes it require more breath or bag pressure to overblow.

With wind instruments that respond to overblowing, it typically requires more pressure to move to the second register from higher notes in the scale than it does from lower notes in the scale. The Multiplier setting controls how pronounced this difference is. Again, increasing this setting can give you better control over the register, especially if using a bag, but will also increase the pressure required to reach the second register, from higher notes in the scale in particular.

Note: Setting both Threshold and Multiplier too high can make it impossible to reach the highest notes in the second register because the pressure sensor is saturated, i.e. it has reached the highest pressure it can detect. If you find that you cannot reach the highest notes in the second register, try reducing one or both of these settings slightly.

Hysteresis causes it to be slightly easier to stay in the second register than it is to initially reach that register. In other words, the pressure threshold for moving up to the second register is slightly higher than the threshold for moving back down. This is how real wind instruments behave.

WARBL2 has the ability to "jump" directly from silence to the second register or to "drop" directly from the second register to silence. Thus, by blowing forcefully (particularly by "tonguing" a note), you can begin playing in the second register without first playing a brief note in the first register. Similarly, by cutting off air pressure suddenly, you can drop directly from the second register to silence. WARBL does this by waiting a small amount of time for a register threshold to be crossed or for the pressure to level off, to detect the player's intent. Increasing the Jump time setting makes it easier to move directly to the second register by increasing the amount of time that WARBL waits to determine the intent of the user. Increasing the Drop time has a similar effect for moving directly from the second register to silence.

## Pressure Graph

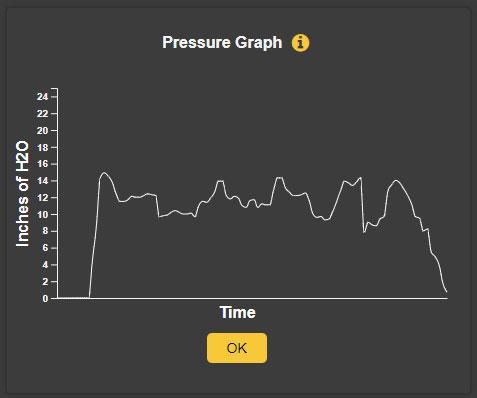
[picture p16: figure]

The pressure graph can be used to view the WARBL pressure sensor readings in inches of H2O over time.

## Finger Vibrato and Slide

WARBL2 mimics open-tone hole instruments by sensing the distance of your fingers from the holes and using this information to bend notes downward. It can detect your fingers a maximum of about 1 cm (~1/2") from the holes.

You can choose 1. Slide and vibrato, 2. Vibrato only, or 3. No pitch bend, or

### 4. Legato slide/vibrato. The way slide works is that lowering the finger over the

highest uncovered hole will gradually flatten the current note down to the next lower note on the scale, much like on a real instrument. This can also allow you to approximate "half-holing" accidentals. Because of the nature of note transitions in MIDI, sliding between notes can sometimes result in a slight "popping" sound when the new note is triggered. This is quite apparent with some sounds like whistles and less so with other sounds like reed instruments. Whether you choose to use slide may depend partly on the MIDI host and sounds that you're using. The normal slide feature is limited to a maximum of 2 semitones before a different MIDI note is triggered.

The 4. Legato slide/vibrato feature is different from the normal slide in that it allows you to slide seamlessly over a range of more than 2 semitones without triggering a new MIDI note. The sliding range is determined by the MIDI bend range (semitones) setting at the top of the Configuration Tool and the Legato slide limit (semitones) setting in the Advanced Pitch Bend Settings panel. For proper slide and vibrato results, the pitch bend range in the MIDI app or host that you are using must be set to the same number of semitones as the MIDI bend range (semitones) setting. The Legato slide/vibrato feature also uses additional holes as “slide holes”: Rather than using only the highest uncovered hole, it uses any hole that would normally cause a new note to be triggered if it was covered.

With vibrato, lowering fingers over any open holes (other than the "slide" hole, if you also have slide turned on) will gradually flatten the note down to the selected maximum vibrato depth. The pitch bend contributed by each hole is cumulative, meaning that lowering fingers over multiple holes simultaneously will flatten the note more than lowering just one finger. This gives control over the amount of vibrato, and can be used to simulate sliding even when "slide" isn't turned on. If a finger is covering a hole when a note is triggered and subsequently lifting that finger doesn't cause a different note to be triggered, then that finger will be available to use for vibrato. However, to enable that finger, you first must remove it completely, past where WARBL can first detect it. This is to prevent problems with closed fingering patterns. As an example of how this works, if you trigger a note, completely remove a finger (one that doesn't change the current note), and then place it back down, the resulting pitch will be lower than the originally triggered note because vibrato has been enabled. This is usually intuitive, but it's important to understand because in certain cases it might not be immediately apparent why the resulting pitch is lower than the original pitch.

You can select at the bottom of the panel which holes you'd like to have available for vibrato. If you normally only use a few fingers for vibrato, you may want to select only those holes, to prevent unwanted behavior.

Custom vibrato is a different vibrato option that is only available for some fingering patterns (currently tin whistle, uilleann pipes, GHB, and Northumbrian pipes). For tin whistle and uilleann pipes, the differences from normal vibrato are as follows: 1. Only the first and/or second fingers of the right hand are available for vibrato, depending on the fingering pattern (you cannot select vibrato holes if this option is turned on). 2. Vibrato is not cumulative, meaning that lowering more than one finger doesn't increase the vibrato depth. 3. If a vibrato hole is covered when a note is triggered, the note is immediately flattened (this is the major difference and may be more natural in certain circumstances).
4. When playing a back D with uilleann fingering, uncovering a vibrato hole actually lowers the pitch instead of raising it, which is how real pipes behave. For GHB and Northumbrian pipes, the custom vibrato is designed for closed fingering systems, and sharpens the note when finger R2 or R3 is raised from a closed fingering position (as opposed to the normal vibrato, where lowering a finger from an open position flattens a note).

Note that custom vibrato is not available when any unsupported fingering pattern has been chosen.

If you’d like to prevent the thumb hole from being used for slide, you can turn off the Use thumb for slide switch.

The pitch bend value received from the WARBL is shown at the right, along with a “wheel”-type display. Note that any received pitch bend messages will be displayed here, including those resulting from IMU vibrato or pitch expression, which are controlled in other panels.

## Advanced Pitch Bend Settings

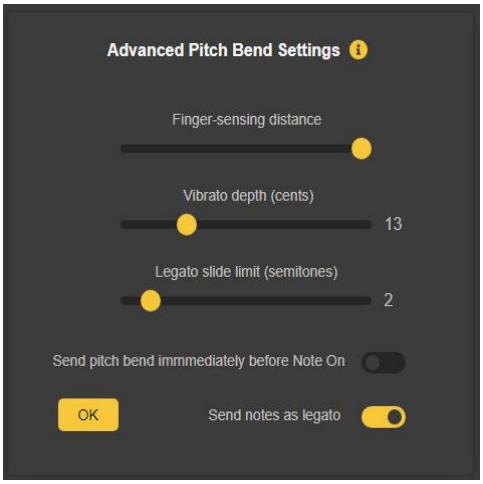
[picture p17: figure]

Accessed by the “Advanced” button in the Finger Vibrato and Slide panel, these settings can be left unchanged by many users, but give more control over how WARBL sends pitch bend messages.

The finger-sensing distance is the relative distance at which the toneholes sense your fingers for slide and vibrato. You can reduce this distance using the slider if you don't want to have to remove your fingers as far from the holes to turn off the pitch bend. The downside is that you'll have less precision in bending notes.

The Vibrato depth (cents) slider determines the degree to which notes are bent when using finger vibrato.

The Legato slide limit (semitones) setting determines the maximum range for sliding if you are using the 4. Legato slide/vibrato option. Note that the MIDI bend range (semitones) must also be set at least as high, and you must also always set the MIDI pitch bend range in whatever MIDI app or host you are using to the same value as the MIDI bend range (semitones) setting.

Normally WARBL2 sends a pitch bend message after a new MIDI note is turned on. Some users may instead wish to send pitch bend before the note is turned on by using the Send pitch bend immediately before Note On switch. This may cause pitch bend audio artifacts with some MIDI apps but is the recommended setting for MIDI MPE.

The Send notes as legato switch cause WARBL2

to wait to turn off each MIDI note until after the next note is sent. This is the recommended setting for most apps and allows many apps to interpret the notes as legato, allowing them to flow seamlessly together.

## Pressure Mapping

This panel allows mapping of breath (or bagpipe bag) pressure to various MIDI messages.

Turning on the Force Max Velocity switch will cause WARBL2

to always send
notes with a velocity of 127 (the maximum allowed), which will allow maximum volume from MIDI apps. Some more sophisticated apps interpret high velocity in ways that also affect the timbre of notes, or various other effects. If this is the case, you may want to uncheck this switch, which will cause WARBL2

to send
notes with a velocity of 64 (the middle of the allowed range). The switch has no effect if the Send Pressure as Velocity switch (below) is selected.

Turning on the Pitch expression switch will cause WARBL to send pitch bend messages based on pressure. This means that for a given note, blowing (or squeezing a bag) gently will cause the note to play slightly flat, while blowing with excess force will cause it to be slightly sharp. This is meant to simulate the way that pressure is used to fine-tune the pitch of real instruments, and can make WARBL2 sound more lifelike. The Expression depth slider controls the amount of pitch bend, and on firmware 4.3 and above the Center Pressure control lets you set the preferred blowing pressure where the pitch is centered. The pitch bend is added to any that is contributed by vibrato and slide, so they can all be used simultaneously. If overblowing is not being used, you have the option of changing the default pressure range used for Expression by clicking the Override... button. On firmware 4.3 and above, the pitch expression override controls are much more advanced, letting you control exactly how the bend responds to pressure.

WARBL2 also has the ability to map pressure sensor values to a MIDI Continuous Controller (CC) note-on velocity, channel pressure, and key pressure, allowing it to function as a MIDI breath controller. These are advanced settings and not needed by many WARBL users. An example would be to send pressure data to CC 7 to control the volume of notes with pressure. The Send Pressure as Velocity option overrides the Force Max Velocity switch (above).

Pitch Expression Pressure Range Override

By turning on the Override pitch expression range switch and using the sliders, you can override the default pressure range used for pitch expression. This is not available if overblowing is being used, because in that case the pressure range has to be calculated in real time based on the current register and overblowing settings.

With the original WARBL, there is a single slider for controlling the pressure range used for pitch bend.

With firmware 4.3 or higher, the pitch expression based on pressure is controlled with two segments:

- A low pressure range, whose min and max input pressure determine a bend along with the low range output bend, from no pressure to the low range max pressure (it will start at the bend amount specified in the low range output bend and end at no bend).
- A high pressure range, whose min and max input pressure determine a bend along with the high range output bend, from the high range min pressure to the high range max pressure (it will start with no bend at the high range min input pressure, and end up with the bend specified in the high range output bend). If the pressure exceeds the high range max input pressure, it will either be clamped at the specified bend amount (if clamp upper bend is on), or it will continue with the same bend slope with more pressure.

The low and high ranges will not overlap. Any gap between the low range max, and the high range min will be a stable portion of the pressure range where no pitch bend occurs. You can see exactly how input pressure maps to output bend in cents with the interactive meters for both input pressure and output bend which are behind each pair of sliders.

The Curve low and Curve high sliders determine the curve for mapping the low and high pressure ranges to pitch bend. The value shown represents the exponent of the power equation used for mapping. Linear mapping will be used if the slider is positioned at "1.00". Double-clicking (or double-tapping) the sliders will return them to the linear setting.

Mapping CC, Velocity, Channel Pressure, and Key Pressure

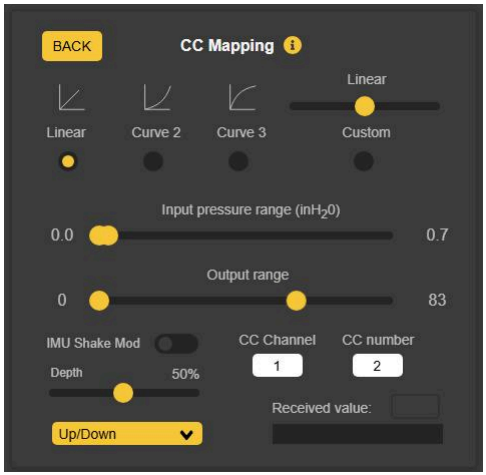
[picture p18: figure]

The input pressure range can be mapped to the output (CC, velocity, channel pressure, or key pressure) range using one of three curves: linear, a power curve (curve 2), or an inverse power curve (curve 3), or (with firmware 4.7 or higher) a custom curve value. Adjusting the sliders below controls which portion of the overall breath/bag pressure is mapped to which portion of the possible MIDI output range of 0-127. When mapping pressure to CC you can choose a CC channel and CC number. Also note that the WARBL2 will only be sending those messages if the corresponding switch in the main Pressure Mapping panel is turned on. In the Channel Pressure mapping panel, you can turn on the MPE+ switch to send 14-bit MPE+ specifically for use with Haken Audio hardware.

Beginning with firmware v. 4.3 it is possible to turn on the IMU Shake Mod switch to modify the pressure mapping by shaking the WARBL2 along its long axis. This can be useful, for example, to modify volume by shaking the WARBL2

. It could
also be used along with Shake vibrato (see the IMU mapping section below) to control both pitch and volume (or another type of expression) by shaking the WARBL2

. You can select the “depth” of the modification as well as the direction (in the drop-down menu below the depth slider).

The Received value field and bar at the bottom show the MIDI messages received from the WARBL2

that correspond to the current panel. For example, if you are mapping breath pressure to CC 7 on channel 1, the display will show only those specific messages. Also, note that the WARBL2 will only send messages if the corresponding switch in the main panel is turned on.

## IMU mapping

The Inertial Measurement Unit (IMU) continuously tracks acceleration and angular rotation in three dimensions. This information is converted to roll, elevation angle (“pitch”), and yaw, which can be then mapped to MIDI CC messages and/or pitch bend.

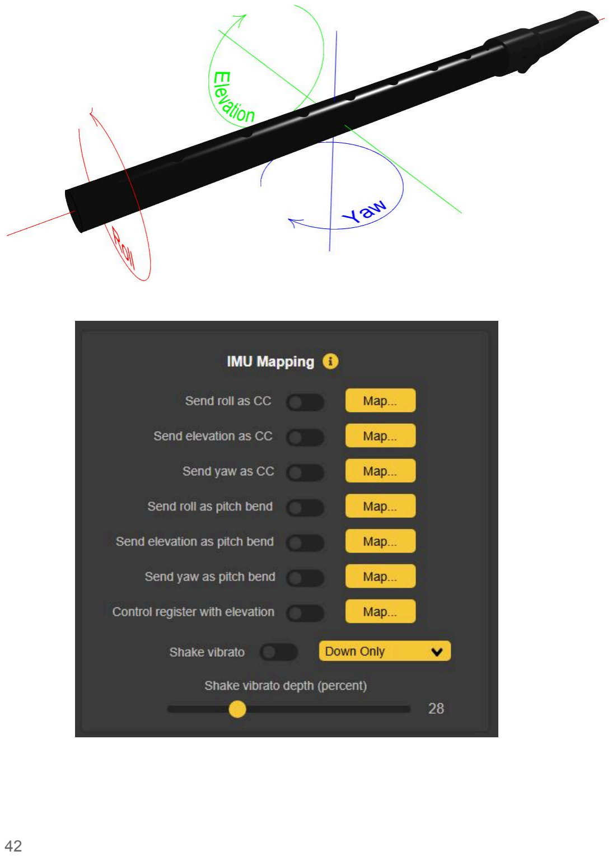
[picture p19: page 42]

There is also an option to play pitch bend vibrato by shaking the WARBL2 along its long axis. You can adjust the amount of shake vibrato and also select the “direction” of pitch bend: selecting up/down means that the pitch will be altered both above and below the normal pitch for the note, corresponding to the direction of movement of the WARBL2

. Down/up has the same effect but opposite the direction of the movement of the device. Up only causes the pitch to only be raised above the current note, and down only causes the pitch to only be flattened.

To map roll, elevation, or yaw to CC messages, turn on the appropriate switch and then click Map. A panel similar to the one below will be shown, allowing you to select the input range as well as the range of output CC values. At the bottom there is a readout and bar that will display CC messages received from the WARBL2

that match the current settings in the panel (note that the switch on the previous panel must also be turned on to cause the WARBL2

to actually send any
messages). For mapping the roll and yaw, there is an option to center the input range, which ties the input sliders together to keep the input range centered on zero.

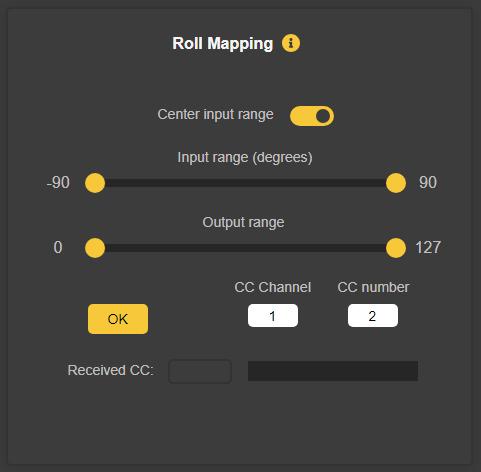
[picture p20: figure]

Note that it is possible to reverse the output range of the IMU mapping by moving the output sliders past each other as shown below. When the output sliders are reversed that are connected by a yellow bar as shown.

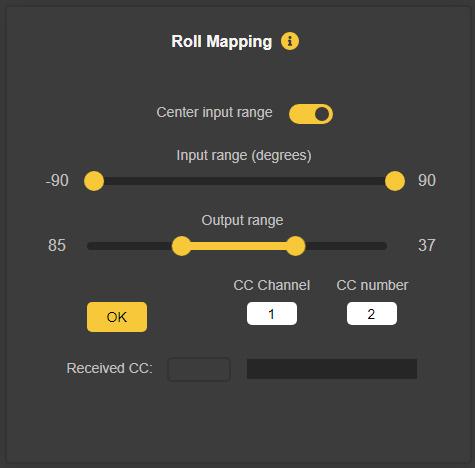
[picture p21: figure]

The yaw has a tendency to drift slightly over time, so you may want to occasionally recenter the yaw (set it to zero). It is also often desirable to recenter the yaw depending on the rotation of your body. There are three ways to recenter the yaw: There is a button in the WARBL2Settings panel to recenter it instantly, you can assign a button action to recenter it (see the Button Behavior panel documentation), or you can use the auto-center yaw option in the yaw mapping panel. The auto-center yaw option will reset the yaw to zero when you begin playing after a pause of a certain length of time. You can choose the length of the pause with the Minimum pause slider.

With firmware 4.4 or higher, IMU rotation can be mapped to MIDI pitch bend messages to “bend” notes by rotating the WARBL2

. To enable this, turn on the appropriate switch in the IMU Mapping Panel (for example Send roll as pitch bend, and then click the adjacent Map… button.

The interface in the IMU > Pitch bend mapping panels (for example the Roll Pitch Bend Mapping panel is similar to the one in the Pitch Expression Pressure Range Override panel.

The interface consists of two segments that are independently mapped to pitch bend. The segments are:

- A low IMU angle range, whose min and max input angle are mapped to the low range bend output.
- A high IMU angle range, whose min and max input angle are mapped to the high range bend output.

If the angle exceeds the high range max input angle or is less than the low range minimum input angle, it will either be clamped at the specified bend amount (if the Clamp bends switch is on), or it will continue to map the same bend slope in the outer angle ranges. Turning off Clamp bends can be useful for sending more than one semitone (100 cents) of pitch bend.

The low and high ranges will not overlap. Any gap between the low range max and the high range min will be a stable portion of the IMU angle range where no pitch bend occurs. This is useful for “playing in tune” when no pitch bend is desired. You can use the pitch bend display in the Finger Vibrato and Slide panel to see the results of the IMU mapping. The display may concurrently show other pitch bend that the WARBL2

is sending (for example finger vibrato or IMU shake vibrato) because the pitch bend messages are cumulative.

The Curve low and Curve high sliders determine the curve for mapping the low and high angle ranges to pitch bend. The value shown represents the exponent of the power equation used for mapping. Linear mapping will be used if the slider is positioned at "1.00". Double-clicking (or double-tapping) the sliders will return them to the linear setting.

There is also an option to control the register using the IMU elevation angle. You can choose the total number of registers and the input elevation range. The number of semitones in each register is controlled by the Register semitones setting in the Note Trigger and Register Control panel. The normal playing range (based on the “transpose” setting) will be at the bottom of the range and you will be able to play up to four registers above that. If overblowing or thumb register control is also enabled you will be able to use both methods of register control simultaneously.

## Half Hole

Turning on the Half hole switch makes it possible to play semitones or use the thumb to play three registers by covering holes halfway. You can select which finger to use for half holes at the bottom of the panel.

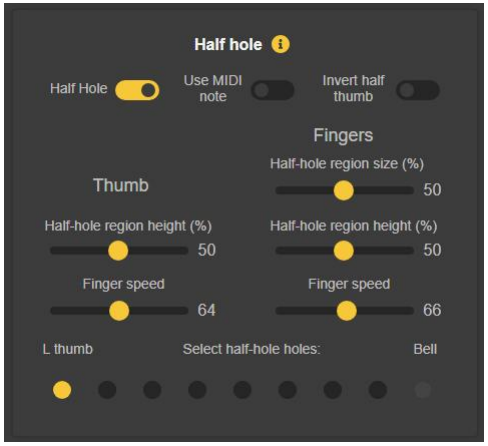
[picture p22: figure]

Playing semitones

When using half holes to play semitones, the pitch is normally changed by using MIDI pitch-bend messages. To send new MIDI notes for semitones instead of using pitch bend, turn on the Use MIDI note switch. When this switch is turned on, the slide feature will be disabled, because sliding doesn’t work as well when many MIDI notes are triggered rapidly.

If using pitch bend to play semitones (with the Use MIDI note turned off), half holes can be used with any of the Finger Vibrato and Slide modes (any combination of vibrato and slide). When lowering a finger over a hole when using both slide and half hole, the pitch will gradually bend until the finger is in the half hole region (see below) and then the pitch will be locked to the semitone. Similarly, the pitch will bend if the finger is below the half-hole region.

Semitones can be played by half holing using any hole (except the thumb) that normally causes a pitch change of a full tone (whole step) with your selected fingering chart (including custom charts).

The half-hole region

The half-hole region height (%) and Half-hole region size (%) sliders allow you to control the size and position of the region above the tone hole where your finger will trigger a semitone. The region height is the height of the center of the region above the tonehole, as a percentage of the full finger-sensing distance. The region size is also a percentage of the overall range. Note that depending on the settings chosen for both parameters, the half-hole region may extend to the top or bottom of the full sensing range (or both). For example, if the half-hole region size is set close to 100% the finger might trigger a semitone anywhere in the sensing range. Note: If using MIDI notes to play semitones (the Use MIDI note is turned on), the half-hole region always continues down to the closed hole.

The Finger speed slider acts as a filter to make it possible to transition from an open hole to a closed hole (or vice versa) quickly without playing a semitone in between. The speed of the finger is monitored as it is moved through the full finger-sensing range. With the slider moved to the right, a semitone will be triggered while the finger is moving more quickly, making it easier to play semitones. When the slide is moved to the left, the finger needs to be moving more slowly to trigger a semitone, so it is easier to move between whole tones without triggering a semitone in between. The Finger speed slide is somewhat similar in functionality to the Transient filter but is applied only to half holes. You can use both sliders together to filter out brief half holes as well as other brief notes. Note: The Finger speed slider has no effect if using slide in conjunction with half holes.

Controlling register with the thumb

The thumb can be used to play three registers in the closed, half, and open positions. This is possible with custom charts and existing charts that don’t normally use the thumb.

To enable this feature, select Thumb register in the Note Trigger and Register Control panel. Then, make sure the thumb hole is enabled at the bottom of the Half Hole panel.

There is not a Half-hole region size slider for the thumb because the half-hole region always extends down to the fully-covered hole (unlike when the fingers are used for sliding and there is a “non-halfhole” region close to the tone hole).

Important: With the Thumb register option selected (with or without using the thumb for half holes), if you are using a custom fingering chart, the thumb position in your chart will be ignored and only the first half of the chart will be used. You do need to have values in the second half of the chart (the part with the thumb hole covered), but those values will be ignored.

You can choose whether each of the three thumb positions (closed, half, and open) plays the first, second, or third register using a combination of the Invert half thumb switch (in the Half Hole panel) and the Invert thumb/bell switch (in the Note Trigger and Register Control panel). The combined effect of these switches is shown in the table below:

Invert thumb/bell | Invert half thumb | 1st octave | 2nd octave | 3rd octave
off | off | closed | open | half
on | off | open | closed | half
off | on | closed | half | open
on | on | open | half | closed

## Drones Control

WARBL2 makes it possible to control drones in MIDI bagpipe apps by assigning commands for turning the drones on and off, and then choosing from a few methods for sending those commands. You can choose to send either Note On, Note Off, or CC messages, assigning the channel, byte 2, and byte 3. For Note On and Note Off messages, byte 2 is a MIDI note number and byte 3 is velocity. For CC messages, byte 2 is the CC number and byte 3 is the value.

The commands used for turning drones on and off will depend on the MIDI host app. For example, the Celtic Sounds app uses a Note On command both for turning drones on and turning them off. In some apps such as Universal Piper, you can choose which command you'll use to control the drones.

Choosing Use secret button will allow you to turn the drones on and off by pressing button 1 while covering the right-hand index-finger hole.

Choosing Turn on/off with chanter will cause the drones to be on whenever the chanter is playing. This will be true no matter how you control the chanter, so will work in bagless mode as well as using the pressure sensor.

Selecting Pressure will turn the drones on and off at a given pressure threshold, so, for example, you can mimic real bagpipes by having the drones come on at a baseline pressure and the chanter come on at a higher pressure. You can either "learn" the pressure or enter it manually, as with the note trigger pressure.

It is also possible to assign any button action to turn the drones on and off. To do this, leave the option in this panel set to No drone control but then assign a button action to Turn drones on/off in the Button Behavior panel (see below).

## Button Behavior

The three buttons can be programmed to perform different actions. This is useful for sending special commands to MIDI apps or customizing the ability to switch modes. Note that it can be confusing if you assign different buttons actions in the three different presets, so it may be useful to use the same actions in all three.

New to WARBL2

there are two additional actions included with the “button” actions: You can either “sip” the mouthpiece or shake the device to trigger commands. Because these are both relatively easy to do accidentally, it is recommended to only use these for commands that won’t have adverse effects or cause confusion if triggered accidentally. Example uses might be recentering the yaw or MIDI panic.

If a button click is configured to send MIDI Note On/Note Off messages, the normal behavior is to alternate between sending Note On and Note Off messages each time the button is "clicked" (the action actually occurs when the button is released). There is also the option to choose "momentary" behavior, meaning that the button will send a Note On message when pressed and a Note Off message when released. This is useful if you only want a note to be on when the button is held down, for example for mimicking uilleann pipe regulators. Note: If momentary is selected, other actions using that same button will be disabled, because it's not possible to differentiate other intentions from a momentary press.

New in firmware version 4.2, you can turn on the Use button double-clicks switch to require double-clicks instead of single-clicks for all three buttons. This can help prevent accidentally clicking the buttons. If a Momentary switch is turned on for a particular button, then the Use button double-clicks switch is ignored for that button.

If you are sending Note On/Note Off messages, byte 2 is the MIDI note number, and byte 3 is velocity. If you are sending CC messages, byte 2 is the CC number and byte 3 is the value. Please note that CC messages 102-119 on channel 7 are reserved for the Configuration Tool, so WARBL cannot be programmed to send additional messages in this range.

If you are sending a CC message and the momentary switch is turned on, a CC message with a value of 0 will be sent when the button is released. When initially clicked, a message with the value that you entered for Byte 3 will be sent. This behavior can be used for on/off CC messages like CC 64-69.

Selecting Send PC will send a Program Change message to the selected channel. This would be useful, for example, to select a particular preset in a MIDI host app. Increase PC and Decrease PC are different in that they assume a Program Change value of 1 when WARBL2

is started, and then increase or decrease it from there. For example, clicking a button assigned to Increase PC after starting WARBL2 will send a PC message of 2 on the selected channel.

These commands are useful for consecutively stepping through the available sounds in a MIDI app.

The momentary switches can also be used when you have selected Octave shift up, Octave shift down, Semitone shift up, or semitone shift down. This allows you to use a button to momentarily shift the octave or key, extending the range of the instrument and allowing any button to act as a "key" for sharpening or flattening a note.

A button can be assigned to begin autocalibration. This can be useful if you anticipate needing to autocalibrate when you don't have access to the Configuration Tool. However, you'll want to use a button combination that can't be triggered accidentally, for example holding button 2 and clicking either button 1 or button 3. Also, when you begin autocalibration with a button combination, you need to be careful not to cover any of the sensors while pressing the buttons, because if you are pressing firmly on the sensors when autocalibration begins it will give WARBL2

incorrect examples of covered sensors.

By default, a long-press of button 3 will power down the WARBL2

. If you’d prefer
not to use a button to power down the device you can choose to let it power down automatically (see the WARBL2 Settings section).

On WARBL2 you can also set a button action to recenter the yaw, or show the battery level. When triggered, the latter will blink the LED in a turquoise color from 1-10 times according to the battery level percentage. If the battery level is lower than 10%, the LED will blink once in red.

The Register hold option (WARBL2) allows you to temporarily prevent the register from changing by overblowing. This can be useful for changing the dynamics in the current register without accidentally changing the register.

The Toggle slide mode option switches back and forth between the Slide and vibrato mode and the Legato slide/vibrato mode, assuming either of those was previously selected. This can be used with or without the momentary switch turned on if assigned to a button click.

The "secret" button commands are a few additional hard-coded actions that involve covering certain tone holes while clicking button 1. These can be useful if normal button actions are used for other functions. They give you an alternative way of changing slide/vibrato mode and preset. With the “secret” commands turned on, covering only hole L3 while pressing button 1 will change the slide/vibrato mode, and covering only R3 while pressing button 1 will change the preset. Note that the Use "secret" button commands switch does not have to be on to use the "secret" drone control button, if that option is selected in the Drone Control panel.

## Optical Sensor Calibration

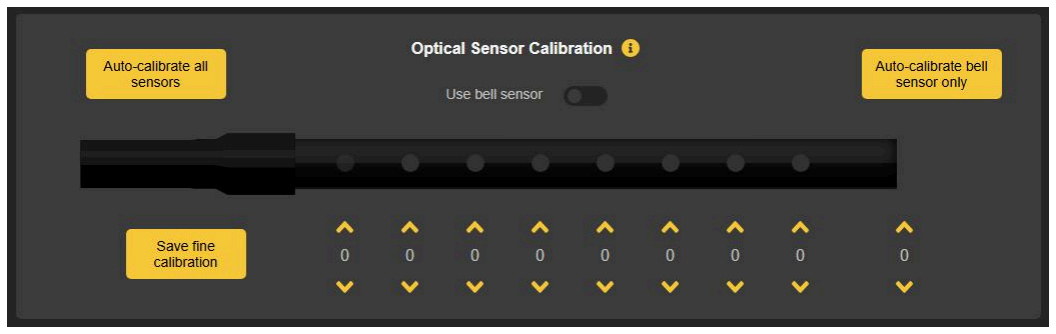
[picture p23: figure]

The optical sensors may occasionally need to be calibrated, for example when the device is new, if a new person is playing the device, or the sensors are a bit dirty. Calibration can also be used in a pinch to compensate for having dirty hands, but it's easier to wash your hands…

Note that there is also a video about calibrating the sensors on the WARBL web site.

If the calibration is far off or you want to calibrate quickly, you can run auto-calibration. Begin by holding WARBL2

in a well-lit room (but not direct sunlight) in such a way that no tone holes are covered (important because it gives WARBL2 examples of raw sensor readings) and then click Begin auto-calibration. The LED on WARBL2 will turn on and then you'll have ten seconds to lightly place your fingers over all the tone holes. Pressing harder on each tone hole will make it more difficult to "cover" after auto-calibration. After this the calibration should be reasonably close. If you plan to use the bell sensor, rest it very gently on whatever surface you intend to use with it while also covering the tone holes with your fingers (or you can calibrate it separately as described below). Note that auto-calibration is always saved immediately; it is not necessary to click Save fine calibration afterward.

You also have the option of auto-calibrating only the bell sensor. This is useful because the sensor may respond differently depending on the type of clothing you're wearing. To do this, hold WARBL up in the air so the sensor is completely uncovered, click Auto-calibrate bell sensor only, and then lower the sensor very lightly onto your knee. After five seconds, the LED will turn off and the sensor will be calibrated.

There is a switch to Use the bell sensor. This is turned off by default but you can turn it on if you want to be able to use the bell sensor to stop all sound when you cover it along with all the other tone holes. If you have selected one of the uilleann pipes fingering charts, those will automatically use the bell sensor, and you don’t need to turn the switch on. You also don’t need to turn it on for calibrating. If you do not need the bell sensor, keeping the switch off will increase battery life by around 10%.

After auto-calibration or for more frequent adjustments, you can just fine-tune each sensor individually. Clicking the up arrow will make it easier to "cover" the tone hole, while clicking the down arrow will make it more difficult. Note that when you plug in WARBL2

, values for each sensor will always read zero, and any changes will be relative to the current calibration. Changes to individual sensors will take place immediately so you can test them as you are changing them, but you must click "Save fine calibration" for the changes to be saved. Otherwise the calibration will be reset when WARBL2

is unplugged.

## WARBL2 Settings

This panel contains information and settings specific to WARBL2. Changes to this panel are saved immediately; it is not necessary to “save settings for the current preset”, and as with sensor calibration, these settings apply to the entire device rather than one specific preset.

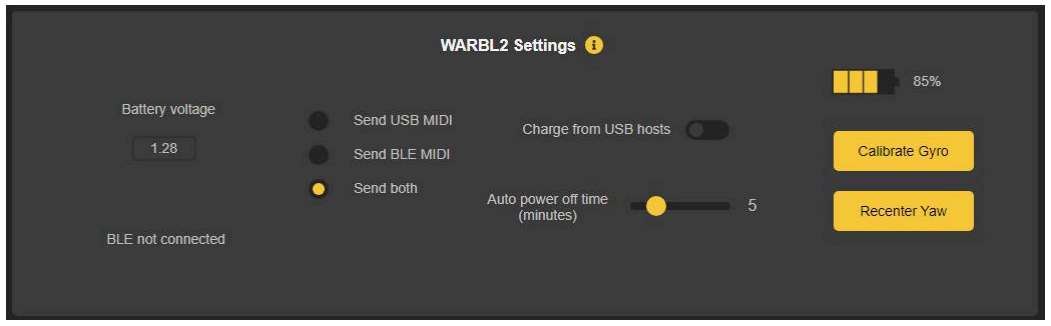
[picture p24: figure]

The battery voltage is shown as a convenience, but the percentage monitor on the far right is usually a more reliable indicator of charge level. As mentioned previously, it is an estimate and becomes more accurate after letting the battery run all the way down (until the WARBL2 powers off) and then charging fully. When charging, a charging icon is shown next to the percentage monitor. If the charging icon is blinking, it may be an indicator of a battery fault such as very low or high temperatures or a battery that is too old to charge.

The BLE status is shown in the bottom left. When connected by BLE it will show the connection interval in milliseconds.

If the WARBL2

is connected to both BLE and USB, you can choose whether to send MIDI data over either or both connections. If only one connection is available, that connection will be used regardless of this setting. The WARBL2 will also communicate with the Configuration Tool by all available connections regardless of this setting.

The WARBL2 can be charged from any USB host (for example PC, Mac, tablet, or phone) or from a USB charging brick. Charging from a USB host can be turned off, which is recommended if you are using USB MIDI and the WARBL2

| is
often connected to a host. This will help save the battery of your host device.

To save battery life, the WARBL2 will shut down automatically after some time if no MIDI notes have been sent or commands have been received from the Configuration Tool. You can adjust the power off time with the slider. Moving the slider to its maximum will prevent the WARBL2

from ever shutting off
automatically. An infinity symbol (∞) will be shown. This setting is generally not recommended because it can cause the battery to be depleted. You can also assign a button action to power off the WARBL2

in the Button Behavior panel.

The gyroscope is calibrated when the WARBL2

is made, but you may wish to calibrate it again occasionally (especially if the roll and elevation seem to drift slightly when the WARBL2

is stationary). To do this, set the WARBL2 on a stationary surface and click Calibrate Gyro. If you are using IMU yaw to send MIDI data, you can recenter the yaw by clicking the button. You can also assign a button action to recentering the yaw in the Button Behavior panel, and there is also an option in the Yaw Mapping panel to automatically recenter the yaw when there is a break in notes.

## 8. Using bagpipe bags and the integrated bell

## sensor

The optional bagpipe kit includes a simple collapsible plastic bottle that can be used as a bagpipe bag. Simply inflate the bag to the desired amount. Then plug the tube into the rubber stopper in place of the mouthpiece tube. Please see the Configuration Tool section above for information on settings for controlling the register, “learning” calibration pressure, and drones control options when using a bag.

It is also possible to use real bagpipe bags, though the method of attachment will vary. Please feel free to contact me for ideas about connecting other bags.

The integrated bell sensor is designed to allow closed piping, as with uilleann pipes. It is similar to the other tone-hole sensors, but is intended to sense when the instrument is “on the knee” or “off the knee”. If the bell sensor is turned on in the Configuration Tool, no note will be sounded if all the tone holes and the bell sensor are covered (with any fingering chart). This simulates an uilleann chanter that is completely closed off. The sensor can also be used for vibrato.

## 9. Care and maintenance

It is best to store the WARBL2 at around room temperature. As mentioned previously, ensure that the power button (button 3) isn’t continuously pressed during storage, for example by a tight-fitting storage container. This will cause the device to stay powered on and will drain the battery. When storing the WARBL2 for long periods of time it is a good idea to recharge the battery every few months.

The only maintenance required is occasional cleaning. A soft cotton cloth (dampened with water if necessary) can be used for cleaning the outside of the enclosure, and a cotton swab works well for cleaning the toneholes and optical sensors. You can dampen the swab with water and if necessary. A compressed air can like those used for cleaning computers can be used to gently blow any dust out of the interior. You can blow air into the tone holes along the sides of the sensors.

Note: Do not use alcohol or other solvents to clean any part of the WARBL2

Solvents can damage the acrylic enclosure.

The stopper and mouthpiece can be cleaned with soap and water, or can be boiled to sterilize.

Please remember that WARBL2

is a sensitive electronic device, and shouldn’t be subjected to extremes of heat, moisture, or vibration. If you treat the mechanical parts such as the buttons and USB connector with respect, WARBL2 should give you many years of service.

## 10. Updating the firmware

There will occasionally be firmware updates for WARBL2

. When you are
connected to the Configuration Tool, it will tell you in the upper right corner if your software is up to date or if there is a new version available. The newest version of the firmware is always available on the Documentation (https://warbl.xyz/documentation.html) page. Please feel free to email info@warbl.xyz or ask on the WARBL Forum if you have any trouble with the installation process.

The easiest way to update the firmware is to use a Windows PC or Mac. Begin by downloading the latest firmware from the Documentation (https://warbl.xyz/documentation.html) page.

WARBL2 has the ability to appear as a USB (“thumb”) drive on your computer. To force it to enter this mode, hold down button 1 (topmost button) on the WARBL2 while you plug it in. It should appear as a drive called WARBLBOOT. Another way to force it to appear as a drive if it is already plugged in is to double-click the reset button with a toothpick.

Once the WARBL2 appears as a drive, simply drag the firmware update file onto the WARBLBOOT drive (or copy/paste the firmware). The firmware should update in a few seconds and the WARBLBOOT drive will disappear. At this point the WARBL2 will have turned back into a MIDI device. The next time you connect to the WARBL Configuration Tool, it should show the new firmware version in the top right corner.

Note: Often both WIndows and Mac will give an error message when the WARBL2 turns back into a MIDI device because the computer is not expecting the “drive” to disappear. This is okay and the update is still successful. At the point when the error appears the update is already complete, so it doesn’t matter which option you click to dismiss the error.

It is also possible to perform the update process on mobile devices if the WARBL is connected with a USB cable.

## 11. LED Indication

The LED on the WARBL2 can produce any color, and while the LED is mentioned in other sections of this manual, the meaning of the various colored indications are summarized below:

Green:

- Blinks once when powering on
- Blinks once when connecting to or disconnecting from the Config Tool
- Blinks once when simple commands are received from the Config Tool or simple controls are changed with button behaviors
- Blinks three times when saving settings, applying the currents settings to all three presets, or restoring factory settings
- When certain settings are changed, it flashes multiple times to indicate the "number" of the new setting. These include: preset, vibrato/slide mode, register control mode, and octave shift up and down.
- Stays on for 10 seconds when calibrating sensors (5 seconds when calibrating the bell sensor alone)

Blue:

- Blinks quickly when in programming (UF2) mode
- Blinks twice when connecting by BLE
- May blink once when opening or closing a BLE app on certain systems

Red:

- Pulses slowly when charging
- May blink approximately once per second if there is a battery error while attempting to charge (temperature too high/low, battery missing, etc.)

- Lights for 1/2 second when powering down by a button command
- Lights for 5 seconds before shutting down because of low battery level

Teal:

- Flashes to indicate the battery level when that option is triggered by a button action

## 12. Replacing the battery

The battery should last for several years. If the playing time per charge seems to be getting unacceptably short you can replace the battery yourself. It is a specialty battery but is available in most countries or it can be ordered from the WARBL website. The battery is a 1.2 V, 400 mAH ⅔ AAA NiMH cell. It can be either a button top or flat top battery. Good-quality brands for this battery include PKCell, Kastar, Dantona, and GP.

To replace the battery, first determine if you have the “old”-style end cap, or the “new”-style cap (made later than January of 2025), based on the photo below. The old cap has a friction fit, and the new cap rotates a small amount to lock in place.

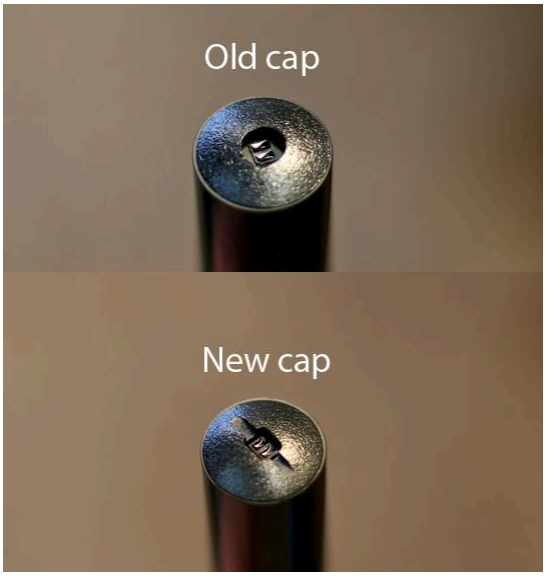
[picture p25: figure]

## If you have the “new”-style end cap (otherwise scroll down to the next section):

Begin by using a coin or other thin object like the back of a knife blade to rotate the cap counterclockwise slightly until it stops turning (being careful not to mar the end cap).

At this point the battery spring may push the cap partway out. If not, use a thin blade like a razor blade under the edge of the cap to help loosen it and lift it out.

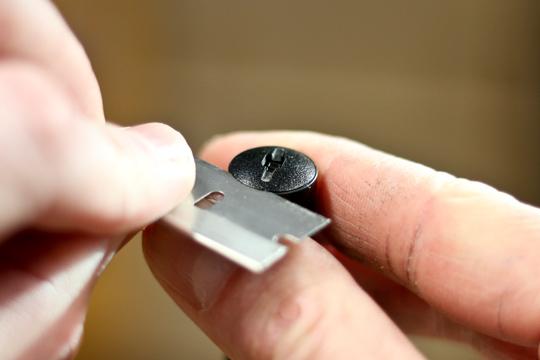
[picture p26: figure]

Once you can grab it with your fingers, carefully wiggle the cap out of the tube. Note: The cap is connected by a cable, so be gentle and don’t pull the cap too hard. Once the cap is free you can pull it straight out approximately 1 cm (½ inch). The cable is extendable and it is okay to pull it this far out of the tube. This will give you space to remove the battery.

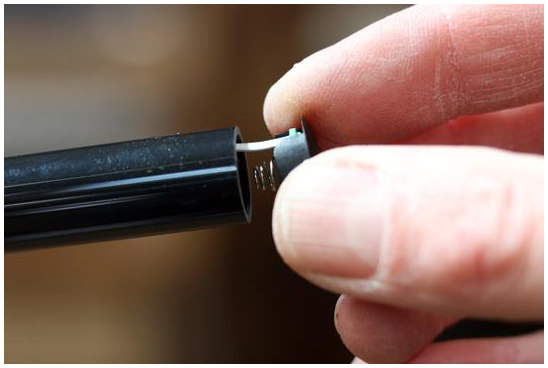
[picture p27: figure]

The battery is held in place by a small spring-like extension on the circuit board that keeps it from rattling. Because of this, the battery won’t simply fall out. You may be able to pull the battery out with tweezers or a strong magnet, but the easiest way to remove it is to place the WARBL2

in a plastic or cloth bag and “flick” it so that centrifugal force will eject the battery as shown below.

Now you can grab the battery and remove it the rest of the way.

Then insert the positive end of the new battery (Important! The positive end will have a “+” symbol.) into the tube and push it in with a non-metallic tool (like a pencil) until it stops (you will feel some resistance as you push it past the spring).

Once the battery is fully seated, begin pushing the end cap back in place, inserting the side of the cap away from the cable first as shown below. This will help keep the cable straight as you insert the cap. Try to keep the cable as straight as possible, because if it becomes kinked it will be more difficult to push back inside the enclosure.

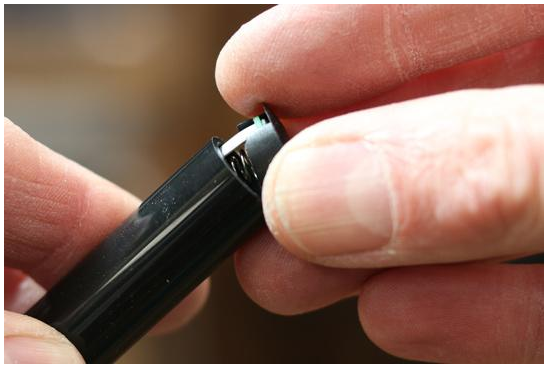
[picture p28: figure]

Notice that there are two slots inside of the enclosure tube:

There are small green tabs on the side of the end cap that fit into the slots:

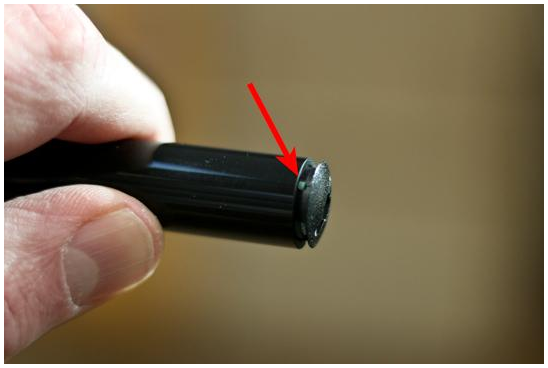
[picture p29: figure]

If necessary, rotate the cap slightly until the tabs engage in the slots and you can push the cap the rest of the way in place. Then use a coin or other tool to rotate the cap slightly clockwise to lock it in place. Don’t try to overtighten the cap–it will only require a small rotation to stay in place.

The battery percentage monitor won’t show an accurate percentage until the battery has undergone a full charge/drain cycle. For this reason it is
recommended to fully charge the battery (until the LED turns green) after replacing, and then use the WARBL2 until the battery is completely drained (until it powers down because of a low battery). After this the percentage monitor should reflect the increased capacity of the new battery.

## If you have the “old”-style end cap:

Begin by removing the end cap. The cap is connected by a cable and contains a circuit board with the negative battery terminal and the bell sensor. Use a single-edged razor blade or other sharp blade to loosen the cap. Insert the blade between the edge of the cap and the WARBL enclosure (tube) as shown below. It will only go in about 1 mm.

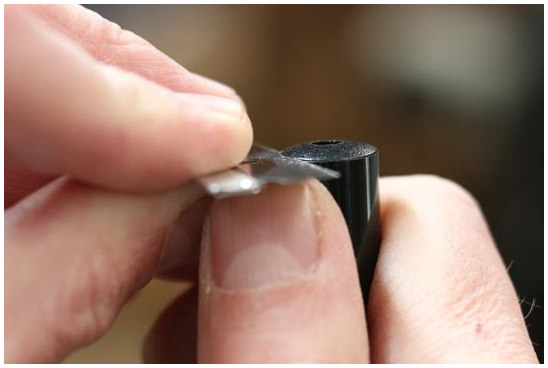
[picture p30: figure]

Next, continuing to hold the blade perpendicular to the tube, use your thumb to push the blade and the edge of the cap upward. Don’t try to pry with the blade, as this can damage the end cap. Simply use the blade to push the cap out of the tube. If necessary, rotate the tube, reinsert the blade on the other side of the cap, and continue to push the cap upward.

Once you can grab it with your fingers, carefully wiggle the cap out of the tube. Note: The cap is connected by a cable, so be gentle and don’t pull the cap too hard. Once the cap is free you can pull it straight out approximately 1 cm (½ inch). The cable is extendable and it is okay to pull it this far out of the tube. This will give you space to remove the battery.

The battery is held in place by a small spring-like extension on the circuit board that keeps it from rattling. Because of this, the battery won’t simply fall out. You may be able to pull the battery out with tweezers or a strong magnet, but the easiest way to remove it is to place the WARBL2

in a plastic or cloth bag and “flick” it so that centrifugal force will eject the battery as shown below. Now you can grab the battery and remove it the rest of the way.

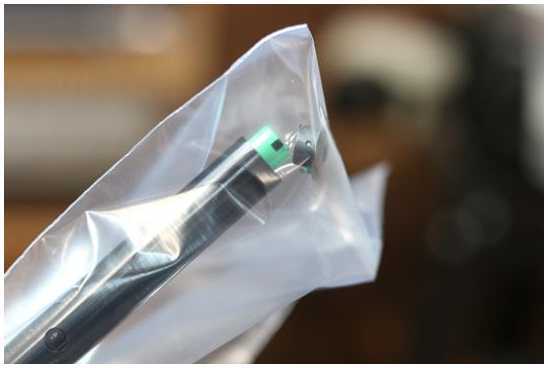
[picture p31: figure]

To install the new battery, rotate the end cap slightly towards the top side of the WARBL2

(the side with the tone hole sensors) as shown below. This will prevent the cable from getting pinched when you insert the battery.

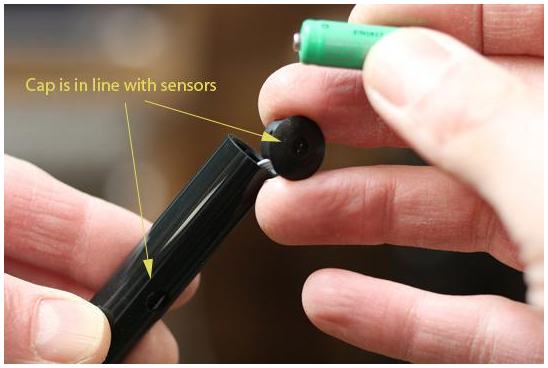
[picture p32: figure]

Now insert the positive end of the battery (Important! The positive end will have a “+” symbol.) into the tube and push it in with a non-metallic tool (like a pencil) until it stops (you will feel some resistance as you push it past the spring).

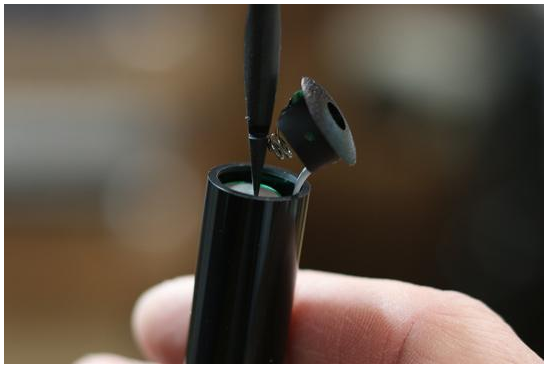
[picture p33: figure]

Once the battery is fully seated, begin pushing the end cap back in place, inserting the side of the cap away from the cable first as shown below. This will help keep the cable straight as you insert the cap. Try to keep the cable as straight as possible, because if it becomes kinked it will be more difficult to push back inside the enclosure.

Once the first side of the cap is in place, insert the other side and push the cap in. If you’d like you can test the WARBL2 when the cap is halfway seated. If it doesn’t work, there’s a chance that the cable has become bent and is stuck between the battery and the spring contact. If this is the case, remove the cap, straighten the cable, and install the cap again. After testing the WARBL2

, push
the cap in until fully seated.

The battery percentage monitor won’t show an accurate percentage until the battery has undergone a full charge/drain cycle. For this reason it is
recommended to fully charge the battery (until the LED turns green) after replacing, and then use the WARBL2 until the battery is completely drained (until it powers down because of a low battery). After this the percentage monitor should reflect the increased capacity of the new battery.

## 13. Troubleshooting

Please see the WARBL FAQ page (https://warbl.xyz/FAQ.html) for troubleshooting. You can also ask questions on the WARBL Forum (https://warbl.xyz/phpbb/) (or search for existing questions), or email info@warbl.xyz.

## Warranty

WARBL is guaranteed for a period of one year from the date of purchase. The warranty does not cover damage to mistreatment or misuse. The customer is responsible for the cost of shipping for warranty repairs. If your WARBL is damaged or malfunctioning and it is beyond the warranty period, please still contact me as I am usually able to make accommodations. Contact for warranty service: info@warbl.xyz.

## Return Policy

I am happy to accept returns within 30 days of delivery. I’ll also evaluate other returns on a case-by-case basis. Please contact me at info@warbl.xyz.

## Technical Data

Dimensions: 8.9” X 0.625”

Weight: 1.2 oz

Operating frequency: 64 MHz

Operating voltage: 3.0 V

Typical power consumption: 30 mW, 500 mW (100 mA @ 5 V) when charging

Interface: USB 2.0 full speed, BLE MIDI 5.3

This product complies with FCC Part 15 Class B and also with CE Directives EN 55032, EN 55103-2, and 2015/863, and carries the CE mark accordingly.

Contains FCC ID: 2AAQS-ISP1807

This device complies with part 15 of the FCC rules. Operation is subject to the following two conditions. (1) This device may not cause harmful interference (2) This device must accept any interference received, including interference that may cause undesired operation. Caution: Any Changes or modifications not expressly approved by the party responsible for compliance could void the user’s authority to operate the equipment.

WARBL is Open Hardware and is licensed under the CERN OHL version 1.2 and the GNU General Public License.

Copyright Andrew Mowry 2019-2026

Mowry Stringed Instruments

557 NE Quimby Ave.

Bend, OR 97701

(541) 241-8704

info@warbl.xyz

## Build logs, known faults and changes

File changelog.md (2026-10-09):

# WARBL2 Changelog
All notable changes to this project will be documented in this file.

The format is based on [Keep a Changelog](https://keepachangelog.com/en/1.0.0/).

## [Unreleased]

## [4.8] - 2026-8-6

### Changed

- Fixed incorrect default values for max input pressure when mapping velocity, key pressure, channel pressure.

- Bell sensor is turned on automatically if "bell register" is selected.

- Some changes to the "recorder with half hole" fingering based on user feedback: Remove the third octave C# and Eb, to avoid playing those notes accidentally while in the lower registers. Changed the "all holes open" note (and minor variations on that) to D74 (second register) to mimic an acoustic recorder more fully. Made it so X XXXXOXX and X XXXXOXO both play an F, and X XXOXXXO and X XXOXXOO both play a G.

### Added

- Support for Bosch BMP585 pressure sensor. This sensor is now being used because the previous Honeywell sensor is being phased out. Also onboard is a BMP580 or BMP581 for sensing/compensating for ambient pressure.

- Duduk fingering

- Note-on hysteresis slider. This allows the user to more accurately simulate instruments that require noticeably more breath to start a note than to sustain it.

- Added a diagnostics page: https://warbl.xyz/WARBL2_Diagnostics.html. When a WARBL2 is connected to this, it displays firmware and hardware versions, battery voltage, runtime per charge, raw pressure sensor counts, and raw optical sensor counts. It has buttons to save the current sensor calibrations as the factory calibration and to reformat LittleFS (the latter can fix rare problems with Bluetooth pairing).

## [Released]

## [4.7] - 2026-6-15

### Changed

- Fixed IMU read interval timing to greatly reduce drift. This also results in smoother IMU behavior overall.

- Improvement to roll (correct reprojection to the body frame).

- Fix to legato slide.

- Fix to thumb slide behavior (thumb slide wasn't enabled for all fingering charts).

- Further improvements to BLE connection interval negotiation.

- Minor fix to battery voltage reading.

### Added

- Custom curve for mapping breath pressure.

- Firmware patch number is now displayed in the Config Tool.

## [4.6.2] - 2026-4-30

### Changed

- Fixed a legato slide bug where a new note wasn't being triggered when necessary.

- 7.5 ms connection interval negotiation to get Windows to use the lowest possible interval.

## [Released]

## [4.6] - 2026-4-2

### Changed

- The Configuration Tool now has a built-in SoundFont player with improved basic audio for testing purposes.
  
- The three "Instruments" are now called "Presets" for clarity, both in the Config Tool and the firmware.
  
- Preset import and export now works on iOS (WARBL app) as well as other platforms. The user is given the option of where to save export files (typically the Files app).
  
- "Yaw" is now much more useful because it is not affected by roll. The body-axis vector is now projected onto a horizontal frame to compute compass heading of the long body axis. This is now used as "yaw" so that it is entirely independent of "roll", which as we use it is defined as rotation around the long body axis.
  
- Fixed a bug where neither "Sip Mouthpiece" nor "Shake" were correctly able to send MIDI messages (channel, byte 2, and byte 3 weren't being sent from the Configuration Tool to the WARBL2).
  
- Reset the long-press counter when any button is released so that a long press of button 2 isn't registered if it was only being held in combination with a click of 1 or 3.
  
- Fixed longstanding bug where certain button actions didn't work properly because of an incorrect check for momentary mode. This particularly affected presets (instruments) 2 and 3.
  
- "Control register with elevation" now uses the "Register semitones" setting in the "Note trigger and register control" panel to determine the number of semitones in each register. This allows using elevation for a more versatile transpose method.
  
- Fixed bug where the WARBL would send CC messages back when told by CC to switch presets, even when not connected to the Config Tool. When not connected, the WARBL still responds to CC messages on channel 7 but won't send any replies.
  
- Fixed calculation of BLE connection interval and added request for renegotiation if the initial interval is greater than 15 ms.
  
- Fixed bug where the selection of holes for half hole pitchbend was ignored if "Use MIDI note" switch was turned on.
  
- Fixed bug where thumb half hole was ignored if another tone hole was also half covered.
  
- Fixed bug in Config Tool where the tone holes selected for half-holing were not synced properly with the WARBL.
  
- Added separate controls for thumb half-hole height and finger speed.
  
- Fixed bug where finger-sensing distance wasn't being considered when exiting the half-hole region.
  
- The WARBL will now always send CC messages in the Config Tool range regardless of the USB/BLE destination setting, so the user can't get locked out of the Config Tool by changing this setting.
  
- Added checksum for SPI transfer of tone hole sensor values from the ATMega.

- Now using SPIM2 instead of SPIM3 because it seems more stable. This also saves 0.15 ma power, for a total of 0.95 (+ 11% battery life) with this update if the bell sensor isn't used.

### Added

- Baroque recorder fingering that leverages half holing for the thumb and fingers to be as close as possible to the acoustic instrument.
  
- It is now possible to send Program Changes messages (1, 2, or 3) on any channel to tell the WARBL to change to preset (instrument) 1, 2, or 3 respectively. The WARBL will not send any messages back unless it is currently connected to the Config Tool (in that case it will be sending CC messages on channel 7 to keep the Config Tool in sync).
  
- Button action for toggling between vibrato/slide modes 1 and 4 (slide and legato slide).
  
- Option to not use the bell sensor. This saves 0.7 mA or about 8% of battery life. If an uilleann pipes chart is chosen the bell sensor is used automatically. Turning it on with any other chart means that sounds will stop if all sensors including the bell sensor are covered, as an option to mute the instrument (useful in "bagless" mode especially).

- There is now a version number in the Config Tool, under the title. I plan to keep it in sync with the firmware but may add patches, e.g. 4.6.2 (major, minor, patch).

## [Released]

## [4.5] - 2025-8-13

### Changed

- Fixed a bug where pitchbend wasn't being reset to zero after IMU pitchbend was turned off.

- Fixed Bansuri fingering chart.

- For consistency, all buttons actions now cause the LED to flash green (except when the "Momentary" switch is turned on).

- Reorganization of the Configuration Tool: Import/Export buttons are now at the top so it is more clear that they apply only to the current instrument. Pressure and IMU mapping panels are now separate, to make access easier.

### Added

- Halfhole pitchbend feature where covering a hole halfway will lower the pitch one semitone (assuming covering the hole completely would play a note a whole step lower). The pitch can be changed either by using pitchbend or by changing the MIDI note. If the thumb is being used to control the register, it can now be covered halfway to play three registers (see documentation for controlling the order of the registers).

- The "Thumb register" setting now works with custom charts by only looking at the first half of the chart (the half with the thumb hole open). You still need to enter placeholder values for the bottom half of the custom chart but it doesn't matter what the values are.
  
- New button/gesture action: "Register hold" feature that temporarily disables overblowing. This allows for finer control of dynamics in the current register without having overblowing interfere.

- Moving the "Auto power off time" slider to the max now represents an "infinity" setting, preventing the WARBL from shutting down automatically.

- There is now a "Use thumb for slide" switch (off by default) that allows to to enable/disable using the thumb for sliding.

- Two new EVI fingering charts, more similar to standardized EVI charts on other devices.

## [Released]

## [4.4] - 2025-1-28

### Changed

- Medieval pipes fingering X XOX OOOO will now play an F natural (77) rather than an F# (78).

- Fixes to tonehole sensor calibration routine.

- Fixed mistake in uilleann pipes "custom" vibrato.

- Fix that prevents the shake pressure IMU feature from modifying if the input pressure is zero.

- Fixed a bug where the vibrato holes selection wasn't being sent properly between the WARBL and the Configuration Tool.

### Added

- Added mapping of IMU roll/elevation/yaw to pitchbend.
  
- Added an "register semitones" setting to allow interval shifts other than an octave by overblowing, using the thumb, or the bell sensor (useful for emulating wind instruments that overblow odd intervals, or for overblowing etc. to play accidentals).

## [4.3] - 2024-10-4

### Changed

- The "pitch expression" functionality for mapping pressure to pitchbend is now much more sophisticated. If not using overblowing, you can now separately map a low pressure range and high pressure range to pitchbend while optionally maintaining a "stable" middle range where no pitchbend mapping occurs.

### Added

- It is now possible to use IMU shake to modify breath pressure mapping (this is located in the pressure mapping panels for CC, Channel Pressure, and Key Pressure).

## [Released]

## [4.2] - 2024-9-4

### Changed

- Changed the "basic" slide behavior so that there be will some slide even if the predicted slide range is greater than the MIDI pitchbend range.

- It is now possible to enter either zeros or blanks in a custom fingering chart to produce silent notes. Also MIDI note 127 will produce a "blank" position that has no affect, in other words the previous note will continue to play.

- Watchdog timer is now started at the beginning of setup() rather then the end, to catch hangs during initialization of peripherals.
  
- Now resetting the ATmega during setup in case only the NRF52840 has been reset.

- Fixed Config Tool connection behavior when WARBL2 is connected by both BLE and USB.

- Changed Gaita and Gaita extended note for 1 101 0001 from 71 to 68.

- Fixed bug in transient delay for closed pipe (all holes and bell sensor covered).

- Fixed bugs with pitch expression (the pitch range was not centered on the pressure range for each note).

### Added

- Added double-click option for button behavior.

- Added a hidden "sticks" mode where WARBL acts as a MIDI drumstick. Turned on by setting transpose to -18 in the Config Tool and then clicking "Auto-calibrate bell sensor only" within 10 seconds. Uses yaw mapping settings to map yaw to MIDI notes.

- Momentary button behavior is now enabled for sending CC messages with a button click. If the momentary switch is turned on, the button will send a CC with a value of 0 when released, for controlling CC on/off "switches", e.g. CC 64-69. When pressed, the button will send whatever CC value is currently set for the behavior.

## [4.1] - 2024-5-1

### Changed

First release of the WARBL2 firmware. Additions from the firmware for the orginal WARBL include functionality for BLE, the IMU, battery management, separate processor (and associated firmware) for reading the tonehole sensors, and a new custom fingering chart feature.

### Added

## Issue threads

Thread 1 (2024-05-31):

USB timeout problem with the current snapshot

ithinu, 2024-05-31:
Arduino 2.3.2
Adafruit LSM6DS 4.7.3
DIO2 1.6.0
MIDI Library latest snapshot (5.0.2 causes compilation error)
ResponsiveAnalogRead 1.2.1
SensorFusion 1.0.6
Adafruit BusIO 1.16.1
Sparkfun LSM6DS Breakout 1.0.1

After upload, everything seems to work fine but each time the device connects it takes a while and a -110 timeout is signaled:

```
Jun  1 00:47:24  kernel: [15311.823169] usb 5-1: new full-speed USB device number 55 using xhci_hcd
Jun  1 00:47:39  kernel: [15327.251092] usb 5-1: device descriptor read/64, error -110
Jun  1 00:47:40  kernel: [15327.531830] usb 5-1: New USB device found, idVendor=239a, idProduct=8053, bcdDevice= 1.00
Jun  1 00:47:40  kernel: [15327.531839] usb 5-1: New USB device strings: Mfr=1, Product=2, SerialNumber=3
Jun  1 00:47:40  kernel: [15327.531843] usb 5-1: Product: WARBL
Jun  1 00:47:40  kernel: [15327.531846] usb 5-1: Manufacturer: Mowry Stringed Instruments
Jun  1 00:47:40  kernel: [15327.531849] usb 5-1: SerialNumber: 7353A2E96268DDD2
Jun  1 00:47:40  kernel: [15327.542832] usb 5-1: Quirk or no altest; falling back to MIDI 1.0

```

After reinstalling the official firmware 4.1, the problem is gone, the device connects immediately:

```
Jun  1 01:04:27  kernel: [16334.787091] usb 5-1: new full-speed USB device number 63 using xhci_hcd
Jun  1 01:04:27  kernel: [16335.156207] usb 5-1: New USB device found, idVendor=239a, idProduct=8053, bcdDevice= 1.00
Jun  1 01:04:27  kernel: [16335.156214] usb 5-1: New USB device strings: Mfr=1, Product=2, SerialNumber=3
Jun  1 01:04:27  kernel: [16335.156217] usb 5-1: Product: WARBL
Jun  1 01:04:27  kernel: [16335.156219] usb 5-1: Manufacturer: Mowry Stringed Instruments
Jun  1 01:04:27  kernel: [16335.156222] usb 5-1: SerialNumber: 7353A2E96268DDD2
Jun  1 01:04:27  kernel: [16335.167209] usb 5-1: Quirk or no altest; falling back to MIDI 1.0

```

amowry, 2024-05-31:
My IDE and all my libraries are the same versions, with one exception-- I'm using v. 5.0.2 of the MIDI library, with any issues compiling. Do you have the #define RELEASE line commented out? If so, you may need to have a driver installed. I'm not sure what the -110 error means exactly, but it sounds like it can be related to drivers.

soitjustca, 2024-06-01:
I attach the compiler at the end of this post (there is also a more completed list of library versions). It is about this fragment in serialMIDI.h:
```
        // Initialise the Serial port
        #if defined(AVR_CAKE)
            mSerial. template open<Settings::BaudRate>();
        #else
            mSerial.begin(Settings::BaudRate);
        #endif
        }
```
Someone had [the same problem](https://github.com/FortySevenEffects/arduino_midi_library/issues/215#issuecomment-1086601296) and the owner's solution was to use the snapshot code. I did not have #define RELEASE commented out, but this error happens also if the line is commented out.

As of the -110 timeout while connecting using the snapshot firmware, I use Ubuntu 22.04. By the way, after powering on, the LED flashes green blue blue no matter whether it is the snapshot or the official firmware.

```
Compiling sketch...
/home/.arduino15/packages/adafruit/tools/arm-none-eabi-gcc/9-2019q4/bin/arm-none-eabi-g++ -mcpu=cortex-m4 -mthumb -c -g -Werror=return-type -mfloat-abi=hard -mfpu=fpv4-sp-d16 -u _printf_float -std=gnu++11 -ffunction-sections -fdata-sections -fno-threadsafe-statics -nostdlib --param max-inline-insns-single=500 -fno-rtti -fno-exceptions -MMD -DF_CPU=64000000 -DARDUINO=10607 -DARDUINO_NRF52840_ITSYBITSY -DARDUINO_NRF52_ITSYBITSY -DARDUINO_ARCH_NRF52 "-DARDUINO_BSP_VERSION=\"1.6.1\"" -DNRF52840_XXAA -DUSBCON -DUSE_TINYUSB -DUSB_VID=0x239A -DUSB_PID=0x8053 "-DUSB_MANUFACTURER=\"Mowry Stringed Instruments\"" "-DUSB_PRODUCT=\"WARBL\"" -DSOFTDEVICE_PRESENT -DARDUINO_NRF52_ADAFRUIT -DNRF52_SERIES -DDX_CC_TEE -DLFS_NAME_MAX=64 -Ofast -DCFG_DEBUG=0 -DCFG_LOGGER=0 -DCFG_SYSVIEW=0 -I/home/.arduino15/packages/adafruit/tools/CMSIS/5.7.0/CMSIS/Core/Include/ -I/home/.arduino15/packages/adafruit/tools/CMSIS/5.7.0/CMSIS/DSP/Include/ -I/home/.arduino15/packages/adafruit/hardware/nrf52/1.6.1/cores/nRF5/nordic -I/home/.arduino15/packages/adafruit/hardware/nrf52/1.6.1/cores/nRF5/nordic/nrfx -I/home/.arduino15/packages/adafruit/hardware/nrf52/1.6.1/cores/nRF5/nordic/nrfx/hal -I/home/.arduino15/packages/adafruit/hardware/nrf52/1.6.1/cores/nRF5/nordic/nrfx/mdk -I/home/.arduino15/packages/adafruit/hardware/nrf52/1.6.1/cores/nRF5/nordic/nrfx/soc -I/home/.arduino15/packages/adafruit/hardware/nrf52/1.6.1/cores/nRF5/nordic/nrfx/drivers/include -I/home/.arduino15/packages/adafruit/hardware/nrf52/1.6.1/cores/nRF5/nordic/nrfx/drivers/src -I/home/.arduino15/packages/adafruit/hardware/nrf52/1.6.1/cores/nRF5/nordic/softdevice/s140_nrf52_6.1.1_API/include -I/home/.arduino15/packages/adafruit/hardware/nrf52/1.6.1/cores/nRF5/nordic/softdevice/s140_nrf52_6.1.1_API/include/nrf52 -I/home/.arduino15/packages/adafruit/hardware/nrf52/1.6.1/cores/nRF5/freertos/Source/include -I/home/.arduino15/packages/adafruit/hardware/nrf52/1.6.1/cores/nRF5/freertos/config -I/home/.arduino15/packages/adafruit/hardware/nrf52/1.6.1/cores/nRF5/freertos/portable/GCC/nrf52 -I/home/.arduino15/packages/adafruit/hardware/nrf52/1.6.1/cores/nRF5/freertos/portable/CMSIS/nrf52 -I/home/.arduino15/packages/adafruit/hardware/nrf52/1.6.1/cores/nRF5/sysview/SEGGER -I/home/.arduino15/packages/adafruit/hardware/nrf52/1.6.1/cores/nRF5/sysview/Config -I/home/.arduino15/packages/adafruit/hardware/nrf52/1.6.1/libraries/Adafruit_TinyUSB_Arduino/src/arduino -I/home/.arduino15/packages/adafruit/hardware/nrf52/1.6.1/cores/nRF5 -I/home/.arduino15/packages/adafruit/hardware/nrf52/1.6.1/variants/itsybitsy_nrf52840_express -I/home/.arduino15/packages/adafruit/hardware/nrf52/1.6.1/libraries/Bluefruit52Lib/src -I/home/.arduino15/packages/adafruit/hardware/nrf52/1.6.1/libraries/Adafruit_nRFCrypto/src -I/home/.arduino15/packages/adafruit/hardware/nrf52/1.6.1/libraries/Adafruit_TinyUSB_Arduino/src -I/home/.arduino15/packages/adafruit/hardware/nrf52/1.6.1/libraries/SPI -I/home/.arduino15/packages/adafruit/hardware/nrf52/1.6.1/libraries/Wire -I/home/Arduino/libraries/MIDI_Library/src -I/home/Arduino/libraries/Adafruit_LSM6DS -I/home/Arduino/libraries/Adafruit_BusIO -I/home/Arduino/libraries/Adafruit_Unified_Sensor -I/home/Arduino/libraries/SensorFusion/src -I/home/Arduino/libraries/ResponsiveAnalogRead/src -I/home/.arduino15/packages/adafruit/hardware/nrf52/1.6.1/libraries/Adafruit_LittleFS/src -I/home/.arduino15/packages/adafruit/hardware/nrf52/1.6.1/libraries/InternalFileSytem/src /tmp/arduino/sketches/7941F34557B3DA7F31EF589CB4FC003B/sketch/warbl2_firmware.ino.cpp -o /tmp/arduino/sketches/7941F34557B3DA7F31EF589CB4FC003B/sketch/warbl2_firmware.ino.cpp.o
In file included from /home/Arduino/libraries/MIDI_Library/src/MIDI.h:35,
                 from /home/src/WARBL2-main/warbl2_firmware/warbl2_firmware.ino:46:
/home/Arduino/libraries/MIDI_Library/src/serialMIDI.h: In instantiation of 'void midi::SerialMIDI<SerialPort, _Settings>::begin() [with SerialPort = Adafruit_USBD_MIDI; _Settings = MySettings]':
/home/Arduino/libraries/MIDI_Library/src/MIDI.hpp:75:5:   required from 'void midi::MidiInterface<Transport, _Settings, _Platform>::begin(midi::Channel) [with Transport = midi::SerialMIDI<Adafruit_USBD_MIDI, MySettings>; _Settings = midi::DefaultSettings; _Platform = midi::DefaultPlatform; midi::Channel = unsigned char]'
/home/src/WARBL2-main/warbl2_firmware/warbl2_firmware.ino:378:33:   required from here
/home/Arduino/libraries/MIDI_Library/src/serialMIDI.h:62:13: error: 'BaudRate' is not a member of 'midi::SerialMIDI<Adafruit_USBD_MIDI, MySettings>::Settings' {aka 'MySettings'}
   62 |             mSerial.begin(Settings::BaudRate);
      |             ^~~~~~~
/home/Arduino/libraries/MIDI_Library/src/serialMIDI.h: In instantiation of 'void midi::SerialMIDI<SerialPort, _Settings>::begin() [with SerialPort = BLEMidi; _Settings = MySettings]':
/home/Arduino/libraries/MIDI_Library/src/MIDI.hpp:75:5:   required from 'void midi::MidiInterface<Transport, _Settings, _Platform>::begin(midi::Channel) [with Transport = midi::SerialMIDI<BLEMidi, MySettings>; _Settings = midi::DefaultSettings; _Platform = midi::DefaultPlatform; midi::Channel = unsigned char]'
/home/src/WARBL2-main/warbl2_firmware/warbl2_firmware.ino:410:36:   required from here
/home/Arduino/libraries/MIDI_Library/src/serialMIDI.h:62:13: error: 'BaudRate' is not a member of 'midi::SerialMIDI<BLEMidi, MySettings>::Settings' {aka 'MySettings'}
Using library Adafruit Bluefruit nRF52 Libraries at version 0.21.0 in folder: /home/.arduino15/packages/adafruit/hardware/nrf52/1.6.1/libraries/Bluefruit52Lib
Using library Adafruit nRFCrypto at version 0.1.2 in folder: /home/.arduino15/packages/adafruit/hardware/nrf52/1.6.1/libraries/Adafruit_nRFCrypto
Using library Adafruit TinyUSB Library at version 3.1.3 in folder: /home/.arduino15/packages/adafruit/hardware/nrf52/1.6.1/libraries/Adafruit_TinyUSB_Arduino
Using library SPI at version 1.0 in folder: /home/.arduino15/packages/adafruit/hardware/nrf52/1.6.1/libraries/SPI
Using library Wire at version 1.0 in folder: /home/.arduino15/packages/adafruit/hardware/nrf52/1.6.1/libraries/Wire
Using library MIDI Library at version 5.0.2 in folder: /home/Arduino/libraries/MIDI_Library
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
MrMep, 2024-07-07:
I think I found the bug:

https://github.com/adafruit/Adafruit_TinyUSB_Arduino/blob/e0345385707c774f658d7312bb47c67e434166a2/src/device/usbd.c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

```
      case DCD_EVENT_SETUP_RECEIVED:
        _usbd_dev.setup_count--;
        TU_LOG_BUF(CFG_TUD_LOG_LEVEL, &event.setup_received, 8);
        if (_usbd_dev.setup_count) {
          TU_LOG_USBD("  Skipped since there is other SETUP in queue\r\n");
          break;
        }
```

For some still unknown reasons, setup_count is > 0 when the timeout occurs. I suspect the first setup request fails later in the code and a second one is sent, but the lines above stop it. This is actually a new check introduced in 3.3.2/3.
I suspect the reason for the multiple setup requests is in our code (or related libraries): the old TinyUSB versions didn't have that check, so eventually the usb setup succeed.

It is enough to comment out the` break; ` above to have everything working normally.

amowry, 2024-07-07:
Amazing, thanks! I guess the next question is: Is it something that I did wrong, or something in a library that causes this?

MrMep, 2024-07-07:
PR 16 should solve the other issue with MIDI Library 5.0.2.

MrMep, 2024-07-07:
> Amazing, thanks! I guess the next question is: Is it something that I did wrong, or something in a library that causes this?

Good question... There's no mention in my PC logs of a setup request gone wrong, so it's still mysterious...
I doubt it is something new in the TinyUSB Library, at least not from 3.1.1 to 3.1.3.
Maybe it was always there but it didn't cause visible problems. There seems to be a race condition in the USB setup request,  but a volatile var (setup_count) doesn't cut it (does it remember anything to you? ;)
I haven't given up yet...

MrMep, 2024-07-07:
So, after all it looks it wasn't our fault...
I PR'ed a fix into Adafruit TinyUSB library, but Adafruit nrf52 latest package has tinyUSB still at 3.1.4, while the main repo already released v 3.3.1, so I wouldn't hold my breath for this issue to be fixed any time soon in the official package.

If you want to fix this now, this line:

https://github.com/adafruit/Adafruit_TinyUSB_Arduino/blob/e0345385707c774f658d7312bb47c67e434166a2/src/device/usbd.c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

must be modified into this:

`        if (_usbd_dev.setup_count > 0) _usbd_dev.setup_count--;
`

amowry, 2024-07-07:
Wow, thanks again--that's a relief. Maybe I'll suggest that Adafruit revert the TinyUSB version for the BSP (?). I'm just happy to know what the issue is, though. I'll add a note to the ReadMe.

Closed 2024-07-07.

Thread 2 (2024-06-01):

A raw mode

ithinu, 2024-06-01:
I would need/like to implement a raw mode. When on, instead of the MIDI note/pitch bend messages, WARBL would send only updates about any pressure/hole/button/IMU sensor values that changed. Looks like something easy to do and taking little space.

In the raw mode, only the functions getSensors(), readMIDI(), readIMU(), blink(), pulse(), calibrate(), checkButtons(), sendToConfig(), manageBatter(), watchdogReset() would be called inside loop(). The method handleControlChange() would need to support two more MIDI events: raw mode on/off. Additional functions would need to be implemented which would send respective update events as MIDI messages. One such function per each sensor read frequency.

Did I miss something in the implementation sketch above?

amowry, 2024-06-01:
You could definitely do this but my only concern would be that it might be a lot of data to send if you want to send it at a reasonably high rate and several sensors are changing at once. It might be fine with USB but I suspect you may run into issues with BLE bandwidth.

Closed 2024-06-26.

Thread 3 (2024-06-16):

debounceFingerHoles() might set a newNote to -1 which becomes MIDI note 127

MrMep, 2024-06-16:
at https://github.com/amowry/WARBL2/blob/1de83c0922f754817d6164c8935dc6ddcd8c9969/warbl2_firmware/Functions.ino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 tempNewNote gets checked if it's valid and different from current note, but the "if" closes here
(https://github.com/amowry/WARBL2/blob/1de83c0922f754817d6164c8935dc6ddcd8c9969/warbl2_firmware/Functions.ino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

Shouldn't it close here:https://github.com/amowry/WARBL2/blob/1de83c0922f754817d6164c8935dc6ddcd8c9969/warbl2_firmware/Functions.ino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
? Otherwise, if the note is -1, 127 is sent to MIDI, and if the note is the same, it is sent again.

gl

joebowbeer, 2024-06-16:
I'm not seeing how -1 will send 127

There are 129 different values:

Valid note range is 0..127 (0x00 .. 0x7F) unsigned

-1 indicates no new note (0xFFFFFFFF)

The conditionals filter out the -1 case, right?

MrMep, 2024-06-16:
-1 becomes 127 because of binary representation of numbers and conversion from a negative integer and the MIDI values.
- the number of values is actually 128.
- The condition is filtered, but lines starting from https://github.com/amowry/WARBL2/blob/1de83c0922f754817d6164c8935dc6ddcd8c9969/warbl2_firmware/Functions.ino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
are executed anyway, that's why the condition needs to be extended to those line too.
This code works only if getNote() never returns -1, which is accidentally the case in the current source code because all positions of all fingerings are possibly associated with a note. But when getNote() returns -1, a high note is played (it happened to me and it's easily reproducible).

joebowbeer, 2024-06-16:
I see what you mean.

The `charts` hold byte (unsigned char) values 0..256 and tempNewNote is signed 16-bit integer.

getNote returns a signed 16-bit int to tempNewNote

No problem so far.

HOWEVER, newNote is unsigned char (byte)

https://github.com/amowry/WARBL2/blob/1de83c0922f754817d6164c8935dc6ddcd8c9969/warbl2_firmware/warbl2_firmware.ino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

So the assignment from tempNewNote to newNote is broken, as you say, and needs to be protected.

Otherwise, the errant note will be sent in the following line:

https://github.com/amowry/WARBL2/blob/1de83c0922f754817d6164c8935dc6ddcd8c9969/warbl2_firmware/Functions.ino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

MrMep, 2024-06-17:
You might want to preserve the ability of defining "muted" positions: in my experience with Warbl, having all the "impossibile" or unused fingerings simply ignored, reduces a lot the probability of unwanted glitches.
In my custom fingering schemes, I set these unused position to a zero value (thus renouncing to generate the corresponding MIDI note 0), and then translate these to -1 in getNote.
We could invent smarter ways to accomplish the same, but this way looks to me as the less invasive of the existing code.
thanks,
gl

amowry, 2024-06-17:
Currently, MIDI note "0" will produce silence because no note is sent in getNote() if the note is zero. (I may have added that after I sent you your WARBL). I did that so that anyone can use a zero or a blank line in a custom chart to produce a blank note. Does that work for you, or would you rather be able to have a value of -1?

joebowbeer, 2024-06-17:
The init of `newNote` to -1 (see my comment above) is also suspect, esp. since `newNote` is unsigned and 0 is the value singled-out to not send a note.

amowry, 2024-06-17:
Yep, good point :). I would propose having all these variables be bytes (unsigned char) initialized to 0, and not use -1 anywhere.

MrMep, 2024-06-17:
> no note is sent in sendNote() if the note is zero.

Sorry, I hadn't noticed :)
May I suggest to keep a check for "0"  values (or "-1", or "0xff", see below) also well before sending a NoteOn? debounceFingers looks a good place: maybe it would avoid some unnecessary processing. That's why I suggested to move the "if" ending (and not just the newNote = tempNewNote assignement as you suggested): if getNote returns a "null" value, you simply don't trigger a new note at all. What do you think?

> would you rather be able to have a value of -1?

If you ask me, I would rather have an equivalent of -1, in case something is wrong with the result of the function. As long as we are speaking of MIDI, I would suggest 0xff as "zero" or "error" result, so that we re-gain access to the MIDI note 0 and keep the ability to return a "null" value.
In general, I would initialize  all byte vars that keep MIDI values to 0xFF, although I understand this would require a value check before sending out any MIDI message.

gl

amowry, 2024-06-17:
Okay, thanks--that makes sense to me to use 0xFF as an error result.

I just pushed some changes. The "byte" data type is now used for tempNewNote, newNote, and prevNote, and they are all initialized to 0xFF. I moved the "if" ending as you suggested, and I'm checking for a note value of 0xFF before changing the value of newNote. I didn't check for a zero value there, though, because sendNote() still needs to be called in order to turn off the previously playing note. I guess we don't need to call getShift() or getState() if the note is zero, but I'm not sure it matters too much if we do. Does that seem okay?

joebowbeer, 2024-06-17:
I'm just an impartial observer, but I think having all the note values use a consistent byte type (unsigned char) and "wasting" note 0 will be easier than introducing a new None value such as -1.

This is closest to what is implemented now, and documented in the charts.

joebowbeer, 2024-06-17:
Test is still != 0 in Functions.ino

https://github.com/amowry/WARBL2/blob/main/warbl2_firmware/Functions.ino#L1471-L1473

amowry, 2024-06-17:
Yes, my intention was that "0" is used as a "blank" (silent) note, whereas 0xFF is used as an error. If 0xFF is encountered then the note will remain unchanged from the previous one. If a "0" is encountered then the previous note is turned off and no new note is turned on. This allows users to enter "blank" notes in custom fingering charts.

joebowbeer, 2024-06-17:
My concern was that, after this check, the shift is added to the newNote which would result in a wraparound value that may be difficult to filter out.

```C
        if (newNote != 0) {                                                 // With a custom chart a MIDI note of 0 can be used as a silent position, so don't play the note.
            sendMIDI(NOTE_ON, mainMidiChannel, newNote + shift, velocity);  // Send the new note.
        }
```

amowry, 2024-06-17:
I'm not 100% sure I understand your concern there but there was an issue that I was flagging that a note was playing if the note was 0 and so was never sent. Now I check towards the beginning of the function if the note is 0, and also down below where we see if we need to turn off a previous note.

joebowbeer, 2024-06-18:
My concern is that if newNote=0xFF reaches the conditional, then it will fall through and emit the MIDI note shift-1 (from unsigned newNote+shift)

amowry, 2024-06-18:
Oh, I understand now, I don't think newNote could ever be 0xFF there because we don't transfer that value from tempNewNote. Maybe newNote shouldn't be initialized as 0xFF, though? I could initialize it as 0 as a precaution.

MrMep, 2024-06-18:
> If a "0" is encountered then the previous note is turned off and no new note is turned on.

Ok, now I realize we mean two different things! My idea is that if you encounter "0" (or "0xFF") you don't turn off the previous note, but simply ignore the change in finger position and keep everything the same. I understand we come from different places: you may be thinking of a pipe-like style of playing, in this case I can see the usefulness of a "stop" position.
On the other side, I'm going after glitches and how to avoid them.
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
amowry, 2024-06-18:
Oh, I understand now-- sorry, I'm a little slow :). I added 0 as a "silent" position because others had asked for it, but I see the desire for a "blank" position as well. I had thought that you were just asking for an error code to indicate if getNote() had failed to return anything.

For custom fingering charts it's a bit easier for me to use only 7-bit values because I'm sending charts to the WARBL using MIDI CC. So, how about 0 for a silent position and 127 for a blank position?

MrMep, 2024-06-21:
> how about 0 for a silent position and 127 for a blank position?

Sorry for the delay, that sounds great! Thank you
gl

amowry, 2024-06-21:
Thanks! I have one more question about the "blank" position. If we are playing a valid note and then stop blowing, then switch to a "blank" position before blowing again, what should happen? Should it play the previous valid note, or play no note at all? The second option seems like it's probably more logical (?).

essej, 2024-06-21:
Good question, if the finger positions haven't changed between the blowing then it should probably play the same as it was before... I think the main point of the blank positions is that they are a shortcut to represent fingerings that "don't matter" and are really the same note as another "real" one, which presumably was active just prior. It is kind of weird, because *really* all combinations should have a particular meaning, it's just a pain to fully spec out a custom fingering for all combinations? I think a detailed example from @MrMep would be great!

amowry, 2024-06-21:
That's the current behavior (and easiest to implement) so I'll leave it at that unless I hear otherwise. I just pushed that change.

MrMep, 2024-06-22:
> what should happen?

A good question indeed!
I think that if a position is silent (or "blank" as you call them), it should be always silent.
I my view:
- if the user is playing (blowing) and hits a silent position, that is ignored  completely (so far so good, I think it's what you've already done);
- If the user stops blowing and restarts with a silent position, no sound should be emitted;
- As well, if the user is playing, hits a silent position and then stops blowing, when he/she restarts blowing still on a silent position, no sound should be emitted.

Here's my rationale: on acoustic wind instruments there are a lot of "false" positions that don't "engage" easily, i.e. they require over-or-underblowing and/or special attacks, and usually are some kind of out-of-tune harmonics, double notes, etc.. When playing normally, if you quickly hit one of those positions, chances are that the current note or the following note will be heard, not the glitch. Maybe if you keep the "wrong" position long enough, eventually the sound will break.

In my custom fingering, one of those position is, for example:
X  011 1101 (thumb hole doesn't matter)
As a position _per se_ it wouldn't make any sense to assign a note to it, but I keep hitting it as a passage note, which is really boring.

Of course, it would be great if we could assign a dynamic threshold (pressure) to these positions and maybe a detuning value, and maybe a second concurrent note  (I'm dreaming, but who knows :)

For the time being, I would say the way you did it @amowry  works well, thank you.

amowry, 2024-06-24:
Just to clarify, I'm using the terms "silent" and "blank" to mean two different things now-- the "silent" note (0) will always produce silence, while the "blank" note (127) won't have any effect, i.e. the previous note will continue playing. I'm realizing this terminology will be confusing because if someone leaves a blank value in the custom chart that they paste into the Config Tool, it will be converted to 0 :). I'm happy to change the "blank" note so it produces silence if blowing is stopped and then restarted, if you'd like. I don't anticipate too many people using it so I'm fine with going with your preference.

MrMep, 2024-07-01:
Thanks Andrew, I guess we can close this as it is now ;)
Is this documented anywhere ?

amowry, 2024-07-01:
Thanks! It's not documented yet but I'll add that when I release the firmware.

Closed 2024-07-01.

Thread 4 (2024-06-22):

Is there a list of EEPROM addresses used? And of MIDI Implementation?

MrMep, 2024-06-22:
Hi @amowry
I need to save some new settings in EEPROM and having a list of address usage would be great.
Also, to add some new functionalities to the config tool, a similar list for MIDI implementation would be useful.

Related to that, I know we have already discussed this in the past, but I think all hard-coded references to EEPROM addresses and MIDI CC/Values in the code should be replaced by defines, so to:
- avoid mistakes
- have an implicit list of values in the code.
- eventually, more easily revise the memory/Midi mappings.

If you want, I can prepare a PR (I'm going to re-do this in any case, in my fork) and keep a detailed track of all substitutions needed.
Let me know

MrMep, 2024-06-26:
Thank you!
After the first PR with EEPROM address defines, I'll submit another one with MIDI defines.
All the info from the file you linked above were inserted into Defines.h. I'll do the same with MIDI.

Closed 2024-06-26.

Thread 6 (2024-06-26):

Whit is the best place to tweak fingerings?

MrMep, 2024-06-26:
In the original WARBL firmware, in get_note() there were a lot of special cases and tweaks for single fingerings, now they seem spread all over the code or entirely gone.
I know I'm missing something! What is the best place to do that now?
thanks

amowry, 2024-06-26:
I got rid of all those special cases because I changed all the fingering charts to have 256 entries. With the original WARBL I was worried about program space so a lot of the charts ignored the thumb hole, etc, and so had 128 entries or fewer. The special cases were needed to account for the holes that weren't included in the charts. It had gotten really messy so I decided to go with full 256 entry charts for everything. That way it's more consistent with how the custom charts work too.

I think you could just add a special case back into get_note() if you need one there.

MrMep, 2024-06-26:
Thank you. As you might have imagined, I asked mainly to manage half-holed fingerings. I'll put it there.

Closed 2024-06-26.

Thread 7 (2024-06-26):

Accidentally pressing buttons

MrMep, 2024-06-26:
I don't know if it's just me, but while playing that happens a lot, especially button 1.
In my fork of the original WARBL firmware I implemented a double-click option.
If it may interest other, I can preparare a PR (the webconfig page has to be updated as well).
Let me know.

amowry, 2024-06-26:
I agree that it's easy to press that button accidentally and the double-click is a good idea. If you don't mind doing that, it would be great.

There are a few things that would need to be addressed:

I'm out of room in the normal progression of CC commands for sending the button actions (CC 102, 90-99) so it looks like we'd have to use CC 102 value 105-107 (105-111 are unused).

There is space in EEPROM for extending the buttonPrefs array.

The Config Tool would need to hide the new options for older firmware and the original WARBL. If you'd like I can do the Config Tool part if you want to do the firmware part.

The Config Tool also disables some button actions if others are selected. We'd have to see which ones need to be disabled if double-click is used for each button (probably the same ones as when a single click is used).

Thanks!

amowry, 2024-06-26:
I guess the other option for the CC messages would be to move the Custom Chart selector command (CC 102, values 100-103) so we wouldn't have to split up the button commands. That might make more sense-- if we free up the values 100-111 then we'll also have more room for button expansion later.

MrMep, 2024-06-27:
Thanks Andrew. In this case I was thinking of something simpler: a general switch button that transforms all single click actions into double click actions.
Beside being simpler to implement, I think it would be simpler for users too.
On the other side, it would be cool to have three more button actions, although at the cost of a complication for everyone.
I'll follow your indications, let me know how it is best to proceed.

amowry, 2024-06-27:
Oh I see-- that does sound a lot easier just having a switch. Let's go with that. Let me know if you'd like me to do that Config Tool part. Thanks!

MrMep, 2024-06-29:
> I guess the "momentary" switches in the Config Tool would have to be disabled

Actually, I would let them independent: if "momentary" is active on a button, it would take precedence over double-click, what do you think?

I'll submit a PR very soon, I could take care of the Config tool part myself, thank you!

amowry, 2024-06-29:
Good idea! That sounds fine to me.

Closed 2024-07-01.

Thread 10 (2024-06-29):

Config tool: coexistence of the same WARBL connected via BLE and USB

MrMep, 2024-06-29:
I guess this had already come up during the development of the firmware.

If a WARBL is connected BOTH via BLE and USB, sendConfig() is issued twice and the Config tool ends up in a mess.
In other words, sendConfig is not thread-safe.

I can see at least four possible solutions (that don't mutually exclude):

1. Implement a simple check when entering comm mode: if already active, we don't re-sendConfig(). We should make sure that comm mode is exited (the flag is set to 0) whenever ALL connections are lost: at the moment it doesn't look that way and I don't know if that's possible.
2. Implement a semaphore. The problem is that the CC messages get intertwined, we should at least lock at the beginning of sendConfig and release at the end.
3. Maybe simpler than 3 and a more general solution: the problem seems to be with multiple messages like jumpfactor and then value, or LSB/MSB, etc. We could "atomize" these couples of msgs and have a semaphore there.
4. Use a different MIDI channel for BLE. This shouldn't be too hard, provided that we can tell the difference between BLE devices and USB devices in the config tool (of which I'm not too sure at the moment).

Of course, a temporary workaround is to manually disconnect either of the two.

Let me know if you want to address this problem and how, then if you want I can take care of it.

amowry, 2024-06-29:
Yes, I was aware of this issue but never got around to dealing with it :).

This is probably aggravated by the fact that the WARBL sends messages to the Config Tool over both USB and BLE regardless of the selection in the WARBL2 Settings panel, which I did to prevent the user from getting locked out of the Config Tool when they change that setting.

It would be great of you wanted to address this (or I'm happy to as well), and I'm sure you know better than I do which method or combination of methods would be best, so I'm fine deferring to your expertise. Option 1 might be simplest (check whether the first Config Tool command comes over USB or BLE and then only send commands back to that connection?). You're right, the WARBL currently never exits communication mode unless explicitly told to do so. I expect we could just exit comm mode if the BLE connection is lost-- I assume the USB connection would only be lost when the WARBL is unplugged, in which case it powers down.

I guess one thing to be aware of is that someone might be using a BLE dongle that appears to the Config Tool as a USB device, so theoretically the WARBL could appear to the Config Tool as two different USB devices. That might cause issues for option 4? So maybe an implementation entirely from the WARBL end is best?

MrMep, 2024-06-30:
Thanks Andrew.
This is slightly more complicated than my initial analysis. (A huge) part of the problem is that the WARBL talks to itself, because of bi-directional CCs...
I have already implemented and tested solutions 2. and 3., but that doesn't resolve the problem.
I don't see any viable solution apart from splitting channels in/out.

From the config tool p.o.v. that shouldn't be that complicated.
Let's say that
 Config tool -> WARBL : channel 7
 WARBL -> Config Tool: channel 8
In the config tool should be sufficient to manage messages from channel 8 as well
From WARBL it could be slightly more complicated. I'll make some tests and report here.

>  So maybe an implementation entirely from the WARBL end is best?

I agree, but we are not able to manage connections from (really) multiple WARBLs. I guess this doesn't look like a big problem, for now.

joebowbeer, 2024-06-30:
> so theoretically the WARBL could appear to the Config Tool as two different USB devices.

Or even two different BLE devices if the WARBL's USB cable is terminated with a USB2BLE dongle. This is more likely to be accidental, but it could happen.

While I'm commenting, and you're looking at the config tool, I wish it could migrate old settings, or at the least know that it can't and fail fast.

amowry, 2024-06-30:
It would be possible to migrate the old settings but I haven't had time make that happen, sorry. The Config Tool should give you an error if you try to import WARBL1 settings to the WARBL2 or vice versa (I added that about a month ago).

amowry, 2024-06-30:
> I'm working on tracking where the enter comm mode command comes from, and send config msgs there only. So, basically, whatever arrives last with an enter comm mode msg, gets served.

Yes, I think that could be a good solution, maybe in combination with a separate MIDI channel if necessary? I guess one of these would have to call a different function so we know the source of the CC message?

`BLEMIDI.setHandleControlChange(handleControlChange);  `
`MIDI.setHandleControlChange(handleControlChange); `

MrMep, 2024-06-30:
> I guess one of these would have to call a different function so we know the source of the CC message?

Yes.
Ok, the problem was all there.

Roughly, here's what happened:
1. I had already implemented a mutex for double messages: I'm leaving that because it doesn't hurt, but it didn't solve this problem.
2. I had implemented a split in/out channel for communication with the config tool: I'm removing it because it looks quite unuseful at the moment,.
3. On the config tool side, I did this: Instead of sending an Enter comm mode message to all devices, it sends one then waits for an answer. If a device responds (with firmware version), it stops sending the Enter comm mode msgs, otherwise tries the next device. This works well via web, but I had to bypass the messages queue. A few tests are required, I suppose, especially with older firmware versions and the app. This avoids the problem when settings are sent multiple times from (potentially) different WARBLs (or transports).
4. On the WARBL side, we keep track of the transport (BLE or USB) that initiated the comm mode, and send config tool messages only through that channel. You'll see in the PR that I think I managed also the disconnections. A question: is the power down in case of USB disconnection hardware driven?

Once we get rid of the pending PRs, I'll submit a new one for this issue.
Thank you.

amowry, 2024-06-30:
Okay, thanks-- I'm not exactly sure what you mean by bypassing the messages queue, but it does seem to be necessary to have a delay between messages, which is the purpose of that queue. I'm not sure why it's necessary, but without it the WARBL2 was receiving messages in the wrong order and sometimes not at all.

The power down is basically hardware driven because the boost converter for the battery isn't normally on when there is USB power, so unplugging cuts the power to the device. It would be possible to enable the boost converter all the time which would allow the WARBL to immediately switch to battery power when unplugged, but I decided that would be confusing.

MrMep, 2024-07-01:
> It would be possible to enable the boost converter all the time which would allow the WARBL to immediately switch to battery power when unplugged, but I decided that would be confusing.

Maybe we could keep track of different states
- if we booted on battery, keep the boost converter on even if USB is connected. The most likely scenario for this is the user wants to charge the battery, so I would keep the boost converter on. When the charge is enough, most likely the usb gets disconnected, but I wouldn't expect the WARBL to power off then.
- If we booted on USB, keep the boost converter off.

amowry, 2024-07-01:
I think I'd prefer to keep the behavior the same at this point if possible-- I'm afraid it could get confusing if unplugging the WARBL doesn't always turn it off, because without a power indicator it's a little tricky to tell when it's turned on. It also keeps things slightly easier for monitoring the battery level if it always powers down when unplugged.

ithinu, 2024-07-01:
Is caring if WARBL was on or off the last time it has been connected and then reacting accordingly in a XOR manner better than just pressing the ON button if one wants it on?

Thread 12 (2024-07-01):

Channel number mask

ithinu, 2024-07-01:
In Functions.ino:3186 c &= 0xF assumes channel = 0 ... 15 but arduino_midi_library/MIDI.hpp:732 (inChannel - 1) & 0x0f suggests that channel = 1 ... 16. I did not check if you use that exact library, but maybe worth looking into.

amowry, 2024-07-01:
Thanks, I think you're right-- I thought the default channel for messages was 0, but it looks like it's actually 1 and it's currently only  possible to send messages on channels 1-15. I think the source of my confusion was that the Celtic Sounds app, which a lot of WARBL owners use, has the same mistake, i.e. the lowest channel allowed is channel 1, not channel 0. I'll need to think about how to fix this without making it confusing for users. I may extend the range to include channel 0 but leave the default channel at 1.

essej, 2024-07-01:
No, there is no "channel 0" with our current use of channel numbers. The binary representation of midi messages them selves use 0-15 of course, but all the MIDI api's used in the app represent the channels as 1-16, so we should continue that. In our sendMIDI() at https://github.com/amowry/WARBL2/blob/cfa142b93cbac3ba4432ce4b904d11ee4fb64860/warbl2_firmware/Functions.ino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
the channel parameter (c) is sent in as 1-16 as well, and we just need to change that mask to a `c = constrain(c, 1, 16);`

amowry, 2024-07-01:
> No, there is no "channel 0" with our current use of channel numbers.

So, you're saying that we're just ignoring channel 0, is that correct? I guess I've always had a fundamental misunderstanding about this. I thought that we were sending on channel 0 by default but calling it channel 1, and that most MIDI apps that allows channels "1-16" were actually using 0-15.

I'm realizing now that MIDI apps typically just don't use channel 0, is that correct? So we don't need to include the ability to send on channel 0?

essej, 2024-07-01:
This is MIDI's fault that it is confusing, it's just a naming convention thing. There are only sixteen channels, and usually they are named for humans 1-16. Most API's including the one we are using ALSO take channel as a number from 1-16. The low-level byte protocol itself however represents channels in the status message as 0-indexed, but we don't operate at that level in this codebase. So, henceforth, in all places where you present a midi channel number just continue to use 1-16 as the allowable range, because that won't break anything, and is correct in the context we operate in right now!

seisiuneer, 2024-07-01:
I could be mistaken.

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

--
___________________________________________________
*Michael Eskin*
***@***.***
(619) 368-1854 (text/voice)

Home Page <http://michaeleskin.com>  |  ABC Tools
<https://michaeleskin.com/abc>  |  Zoom Session
<http://michaeleskin.com/session>  |  AppCordions <http://appcordions.com>
|  Flickr <https://www.flickr.com/photos/eskin/albums>
___________________________________________________

essej, 2024-07-01:
It's just a context thing. If we were constructing the bytes that go into a midi message, we'd need to do something 0-indexed, but since we are just using other API calls that take 1-indexed channel numbers also, we don't.

amowry, 2024-07-01:
Yes, sorry I confused myself on this earlier-- you're both right, and nothing is wrong with Celtic Sounds :). The only issue was that the WARBL wouldn't ever send on channel 16, which is fixed now.

MrMep, 2024-07-01:
Just to be pedantic, but I guess this is technically wrong too:

https://github.com/amowry/WARBL2/blob/ad7f9d3687b0f1574e1e127ddef66c8111226464/warbl2_firmware/Functions.ino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

The Config tool channel is hardcoded, so it's not a problem at all, unless we switch to channel 16 :)

amowry, 2024-07-01:
Right, thanks!

joebowbeer, 2024-07-01:
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

I think this is more than pedantry.

channel should be constrained to be between 1..16 right?

The 0x0f mask is not appropriate here

amowry, 2024-07-01:
Yes, I removed the mask. It's been in there forever and I'm not sure why :)

Closed 2024-07-01.

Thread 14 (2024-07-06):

Proper procedure for new settings

MrMep, 2024-07-06:
I see that Andrew added this:

https://github.com/amowry/WARBL2/blob/f900aacfb407cc3c845ba6b4295daf6f51a564ce/warbl2_firmware/Functions.ino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

Still, it's unclear to me:
 - What if that EEPROM byte was by chance at value 1 (first run with new firmware) and 1 is not the intended default value?
 - What about the Factory Settings?

Shouldn't we catch a first run with a new FW version and adjust the default values for the new preferences (and the related factory settings)?
I kind of remember there was something like that in WARBL(1): has it been moved somewhere else?

Thanks,
gl

amowry, 2024-07-06:
Yes, I've done this different ways, but you're right-- I guess it should check when it re-writes the firmware version and change the EEPROM value to 0 for both the factory setting and current setting. I'm not sure the best way to do that without it getting messy after a number of firmware changes? In the past I've sometimes had a new firmware version completely rewrite settings, but that's no a popular option.

MrMep, 2024-07-06:
I think it's a common problem, and that there should be a "migration manager "somewhere at startup.
In this case, if the trigger is the new value for Firmware version, we should simply have a manual check for each new release.

For every new setting we should define a default value and write it both in current settings and factory settings.
This way, we could also ideally re-write whole pieces of settings and manage the migration without loosing the existing prefs. (And we should do the same with saved settings via Config Tool, but that's for another day ;)

I'll cook up something, if you want.
Also, we could "patch" existing factory settings, if needed. For example, this looks fishy:

https://github.com/amowry/WARBL2/blob/21a46a19bbf4467465b5170a09028481bb73d131/warbl2_firmware/warbl2_firmware.ino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

the values for previous CUSTOM_FINGERING (that now are unused variables) should be set at zero.
With a migration manager we could apply a patch.

What do you think?

amowry, 2024-07-06:
Yes, that sounds fine to me. You're welcome to do it if you'd like, or I can before releasing v 4.2. Thanks!

amowry, 2024-07-07:
How about something like this for the migration manager? This is called from settings if the version has changed. I'll address the unused variables you mentioned above as well.

`// Make any necessary changes to EEPROM when new firmware is installed
void manageFirmwareUpdate() {

    switch (VERSION) {
        case 42:
            for (byte i = 0; i < 3; i++) {
                writeEEPROM((EEPROM_SWITCHES_START + i + (BUTTON_DOUBLE_CLICK * 3)), 0);                                  // Initialize button double-click preferences as false (0) for all three modes.
                writeEEPROM((EEPROM_SWITCHES_START + i + (BUTTON_DOUBLE_CLICK * 3)) + EEPROM_FACTORY_SETTINGS_START, 0);  // Initialize factory settings for same.
            }
            break;

        default:
            break;
    }
}`

MrMep, 2024-07-07:
> How about something like this for the migration manager?

It looks good, but I wouldn't presume what the current version is: if someone upgrades, say, from 41 to 44, it has to apply all the patches sequentially. What do you think?

MrMep, 2024-07-08:
Here's how I would go:

```
void checkFirmwareVersion() {
    byte currentVersion =     readEEPROM(EEPROM_FIRMWARE_VERSION);  // Previous firmware version.

    if (VERSION != currentVersion) {

        if (currentVersion < 42) { //Here manage all changes made in version 42

            for (byte i = 0; i < 3; i++) {
                writeEEPROM((EEPROM_SWITCHES_START + i + (BUTTON_DOUBLE_CLICK * 3)), 0);                                  // Initialize button double-click preferences as false (0) for all three modes.
                writeEEPROM((EEPROM_SWITCHES_START + i + (BUTTON_DOUBLE_CLICK * 3)) + EEPROM_FACTORY_SETTINGS_START, 0);  // Initialize factory settings for same.
            }

        }

        writeEEPROM(EEPROM_FIRMWARE_VERSION, VERSION);  // Update the firmware version if it has changed.
    }
}
```

amowry, 2024-07-08:
Makes sense, thanks! I just pushed this change and a few other fixes.

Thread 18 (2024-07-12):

Call for beta testing

MrMep, 2024-07-12:
I just submitted a new PR https://github.com/amowry/WARBL2/pull/17  in the develop branch of this repository.

If you can compile and test the new modifications, you are more than welcome to do that and report back here or in the PR discussion thread.

Here's an extract from the PR description.

First of all, there's support for **half-holing**.

EDIT:
~~It is limited to:~~
- It is supported on all holes (except bell)
- **thumb**: it raises by one octave (based open or closed thumb hole note, user selectable)
- **L1** - **R4**: raises by one semitone, but base positions only (all upper holes covered, lower holes open), regardless of thumb status.

The user can activated the half-hole detection for each single supported tonehole.
In the "Advanced" settings for half-holing it is possibile to tweak the sensitivity of the detection, hopefully to accomodate different playing (and instrument gripping) styles.

The current hardware finger sensing mechanism doesn't allow for precise half-hole sensing, so a lot of changes had to be made to the **debouncing** machine.
Basically, the transient note filter delay is now dynamic: it adjusts based on the player's gestures, and it extends or reduces the delay consequently. For now, gesture detection is limited to note interval, number of fingers changed and status of half-holes. It can be extended to other types of gesture detection. I removed the previous sensing based on senseDistance, because it is redundant at this point.
Being dynamic, the "sluggish" feeling should be reduced a lot, while most of the glitches are more effectively removed.

I added my own **EWI Fingering** ("Mep's EWI") and the relative fingering PDF chart. Based on this, there a new "**Mep's Recorder**" that takes advantage of half-holing and has a lot of alternate fingerings (all based on real acoustic recorders).
Now the recorder fingering is exactly the same as real recorders. After validation, it could replace the current Soprano recorder fingering (and drop the "Mep's" part ;)

**Config Tool**
I did my best to follow Andrew's style and prefs: of course, @amowry feel free to move things around as you see fit.
- I added a "Half Holes..." button to the "Note trigger and..." box. there you can setup your own preferences. They apply regardless of the selected fingering and are saved in the current mode/instrument (when saved)
- I moved things around in the WARBL2 Settings box (but this was unnecessary)
- I added a new intermediate js function when switching fingering: it is similar to updateCustom and for now it manages the preferences for my new two fingerings. I think we can improve on this and go more towards a "Preset" management for the whole instrument (and not just changing the bare minimum as in updateCustom). I had to add this new function because it triggers events (so the new settings are sent to the WARBL), and that in turn calls updateCustom.
- When switching back to another fingering, the whole half-holing is deactivated by deafult.

A few notes about the **source code**:
- I switched to **fw version 99**, which could be the code for dev version. This might cause problems when switching back and forth production fw, so be careful and prepared for a loss of settings! (but you wouldn't flash a dev firmware if you weren't prepared to that, would you? :D )
~~- You'll see portion of code related to a "baseline auto-calibration", but this seems redundant at this point and can be possibly removed before merging.~~
- Most of the new stuff is in HalfHole.h and HalfHole.ino. These can be merged respectively in Defines.h and Functions.ino once tha code is validated.
- I left **a lot** of debugging code. the relative triggers are at the start of Functions.ino. Of course, all of that can be removed or reduced before merging in the main branch.

EDIT: @amowry added a flash.uf2 file of this beta version, just drag&drop to install:
https://github.com/amowry/WARBL2/blob/develop/warbl2_firmware/build/adafruit.nrf52.warbl2/flash.uf2

EDIT 2:
I fixed a few things and added an ~~auto~~ continuous optical calibration for toneholeCovered

amowry, 2024-07-12:
Thanks! I merged it tested it very briefly and it seems great so far. I'm trying to focus most of my time on my "other" job at the moment but I'll continue to test this. I'm sure I'll have some questions. Not being a recorder player, I'll certainly defer to you on the fingering charts. Maybe it would be good to keep both recorder versions in case anyone is familiar with the current one? I haven't looked to see what differences there are other than the half holing.

I updated the flash.uf2 file in the "develop" branch, if anyone wants to test this they can just drag/drop that file.

essej, 2024-07-12:
I made some comments on the now already merged PR, but I will continue testing to make sure other things didn't break...

amowry, 2024-07-12:
Thanks! I went ahead and merged it because it's a development branch, but if you guys have more changes feel free to make more requests or just commit them. And let me know if there are things I do wrong with the workflow, because I'm still learning :).

MrMep, 2024-07-12:
> I made some comments on the now already merged PR

Thanks, I saw it. It's true, I don't test much in mode 4 and, frankly, I don't even know exactly what to expect. I made some testing after your post, but I'm still struggling to hear what you describe.

WARBL2 is so much flexible and everyone has her/his playing style and preferred settings: everyone's help in testing & debugging these new features is essential, thank you!

The problem you describe might have to do with holeLatched, that is updated only when committing a new note: maybe we should add something from:

https://github.com/amowry/WARBL2/blob/0a4048b85608b5420647ac3814416b3a8b7d8c92/warbl2_firmware/Functions.ino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

to around here, where a new position with same note is detected:

https://github.com/amowry/WARBL2/blob/0a4048b85608b5420647ac3814416b3a8b7d8c92/warbl2_firmware/Functions.ino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

I don't know if an update of holeLatched is enough, or we should reset PB in any case.
Or maybe it is something entirely different. Any help is much appreciated!

MrMep, 2024-07-12:
> Maybe it would be good to keep both recorder versions i

Maybe we could call the new one "Baroque Recorder".

> I haven't looked to see what differences there are other than the half holing.

Besides alternate fingering for trills etc., most of the second octave on the recorder requires a half thumb hole, while a few notes in the middle require an open hole. The current Soprano fingering isn't capable of managing that.

> I merged it tested it very briefly and it seems great so far.

Thank you!

But, in HalfHole.h there are a few constants that fine tune the transition filter:

https://github.com/amowry/WARBL2/blob/0a4048b85608b5420647ac3814416b3a8b7d8c92/warbl2_firmware/HalfHole.h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

I'm already seeing that those might be tweaked a bit, I'm not fully satisfied with the results for now.
Especially the last one might be too big (essentially reducing the effectiveness of the filter).
When you all have time, please try different values yourselves, thanks!

essej, 2024-07-12:
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

I'm working it out... it relates to how getSlide() does the slide calculation only if tf.currentDelay == 0 (which was transitionFilter), and in my old debounce/transient it handled the override for when there should be no filter in a different way. So there is tiny moment of time where your debounce/transient filter is trying to activate, but where it wasn't before. I will figure out a way to still have things work as they did with the slide modes and the new debounce/transient filter.

amowry, 2024-07-12:
I can imagine that users would almost immediately ask me if it would be possible to use any hole for half-hole fingering. One thought is that we could have something like the diagram in the vibrato/slide panel where you can select the holes that you want to use. As an example, I could see how a tin whistle player might want to be able to play common accidentals (F natural, Bb, etc.) by half holing and so might want to "turn on" half holes for only a few holes.
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
ithinu, 2024-07-15:
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

Digital instruments have two response times: from pressing a button to producing a note event (let's call it reaction R), and from pressing a key, via an audio synthesizer and possible pedals, then a possible speaker's DSP finally to a sound from the speaker (= latency L).

R is often virtually instant and that's what allows a realistic modelling of a physical instrument by attack A/decay D times set in the synthesizer. Increasing R would require smaller A, up to A being unrealistic. As for transient notes, think of one which produces a very quiet response in a real whistle and in Warbl, thanks to a synthesizer's A/D. With the filter in question, there would only be silence.

Then there is L, which is often excessive and increasing R would only make L worse.

> 2. **Auto (or continuous) optical calibration**: no acoustic wind instrument reacts, to my knowledge, to how much pressure you put on the holes/keys, or to dirty fingers, or to variations in ambient light. The WARBL does, and it kind of ruins the illusion that you are playing a real instrument. The ability to do automatically what now you have to explicitly do manually through the Config tool (re-calibrate), in my view would be a great improvement. We are not exactly there yet, but it would make the WARBL **more** similar to a whistle, not the contrary.

If Warbl reacts differently to pressure, it looks like its response curve is much different to that of an acoustic instrument. There may be two reasons behind that:

- an unrealistic translation of the sensor's value;
- not chamfered toneholes.

I tried to adapt the former, but what you speak about  was still there and I suppose that the sharp hole edges are quite a problem behind the unnecessary pressure sensitivity and the light sensitivity. I will chamfer them soon and test it if helped.

> If one's technique is poor, there's no filter that could possibile improve that effectively

Yes there is. My technique is poor and I have already increased a threshold of one hole, seeing later that i should rather be more precise. Yet the "calibration" worked as expected even though it was not a good solution.

I would not resort to adaptive solutions being the basic ones until simpler methods have been proven ineffective, because a physical instrument is not inherently adaptive. It may be not obvious to test if such adaptations make the instrument feel unsteady or not.

amowry, 2024-07-16:
This issues I mentioned with the bell sensor and the Config Tool disconnecting do seem to be fixed. Thanks! I'll keep playing with the autocalibration-- I haven't had much time yet but it also seems better.

ithinu, 2024-07-16:
I modified the light sensor response curve and I no longer need to apply pressure. What I initially took for light sensitivity is also gone, at least if not in daylight. But I do not play an actual whistle, I hardly started to try Warbl. If you feel that it is now more realistic, maybe it is.

By the very definition of raw mode, I will avoid both 'auto' mechanisms anyway. Thanks, Andrew, for the open firmware.

MrMep, 2024-07-16:
> R is often virtually instant and that's what allows a realistic modelling of a physical instrument by attack A/decay D times set in the synthesizer.

Except that most of WARBL users use some kind of  sound-font-type of app where mostly **ADSR curves are fixed** in the samples. They usually have very low attack and release, because they try to be as responsive as possibile, and that opens the door to any kind of glitch coming from the controller. I'm sorry I must be verbose.
If one
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

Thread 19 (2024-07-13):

App version of Config Tool disconnects when another MIDI app is opened

amowry, 2024-07-13:
I've been noticing that with BLE, the iOS app (or app version of the Config Tool in Web MIDI Browser) disconnects from the WARBL2 when another MIDI app is first opened. After reconnecting, it will stay connected. If you open another MIDI app before connecting with the WARBL app, it will also stay connected. After disconnecting, it will still receive messages from the WARBL, so it seems that the connection is briefly broken and then restored, but the connection logic isn't aware of it. It probably just needs to try to reconnect after there has been a state change (?).

I'm adding this here to remind myself to look at it :).

amowry, 2024-07-16:
The issue is that I don't seem to be able to tell which port the WARBL is on with BLE on iOS so I can't figure out a way to reliably tell when the WARBL has been disconnected. The onstatechange event has always been used for this, but it fires for other reasons when BLE is used.

For now, I added a patch that reconnects the Config Tool if it thinks it has disconnected but it's still receiving CC messages from the WARBL. It's crude but seems to be an improvement from the previous behavior where the Config Tool disconnects for no apparent reason and never reconnects. I think that ideally the WARBL should just send a message every second or so telling the Config Tool to remain connected (the battery status updates could be made more frequent for this), and I might add that to the firmware, but the current behavior will still be needed for anyone on firmware 4.1 (or older).

Closed 2024-09-19.

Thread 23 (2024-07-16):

Current transient filter causes a spurious note with uilleann fingering

amowry, 2024-07-16:
Will uilleann pipes fingering, the transient filter in 4.1 cause an extra low D note to be played when all holes (including bell sensor) are covered and then one finger is lifted. The low D is played briefly during the transient filter delay, and then the desired note is played.

Edit: It happens with the new transient filter too and actually happens with any fingering chart. When all holes and the bell sensor are covered (which silences the WARBL with any fingering chart), and then any finger is removed, the lowest note on the scale plays during the filter delay period before the correct note plays.

amowry, 2024-07-17:
I pushed a fix for this to the develop branch.

Closed 2024-07-17.

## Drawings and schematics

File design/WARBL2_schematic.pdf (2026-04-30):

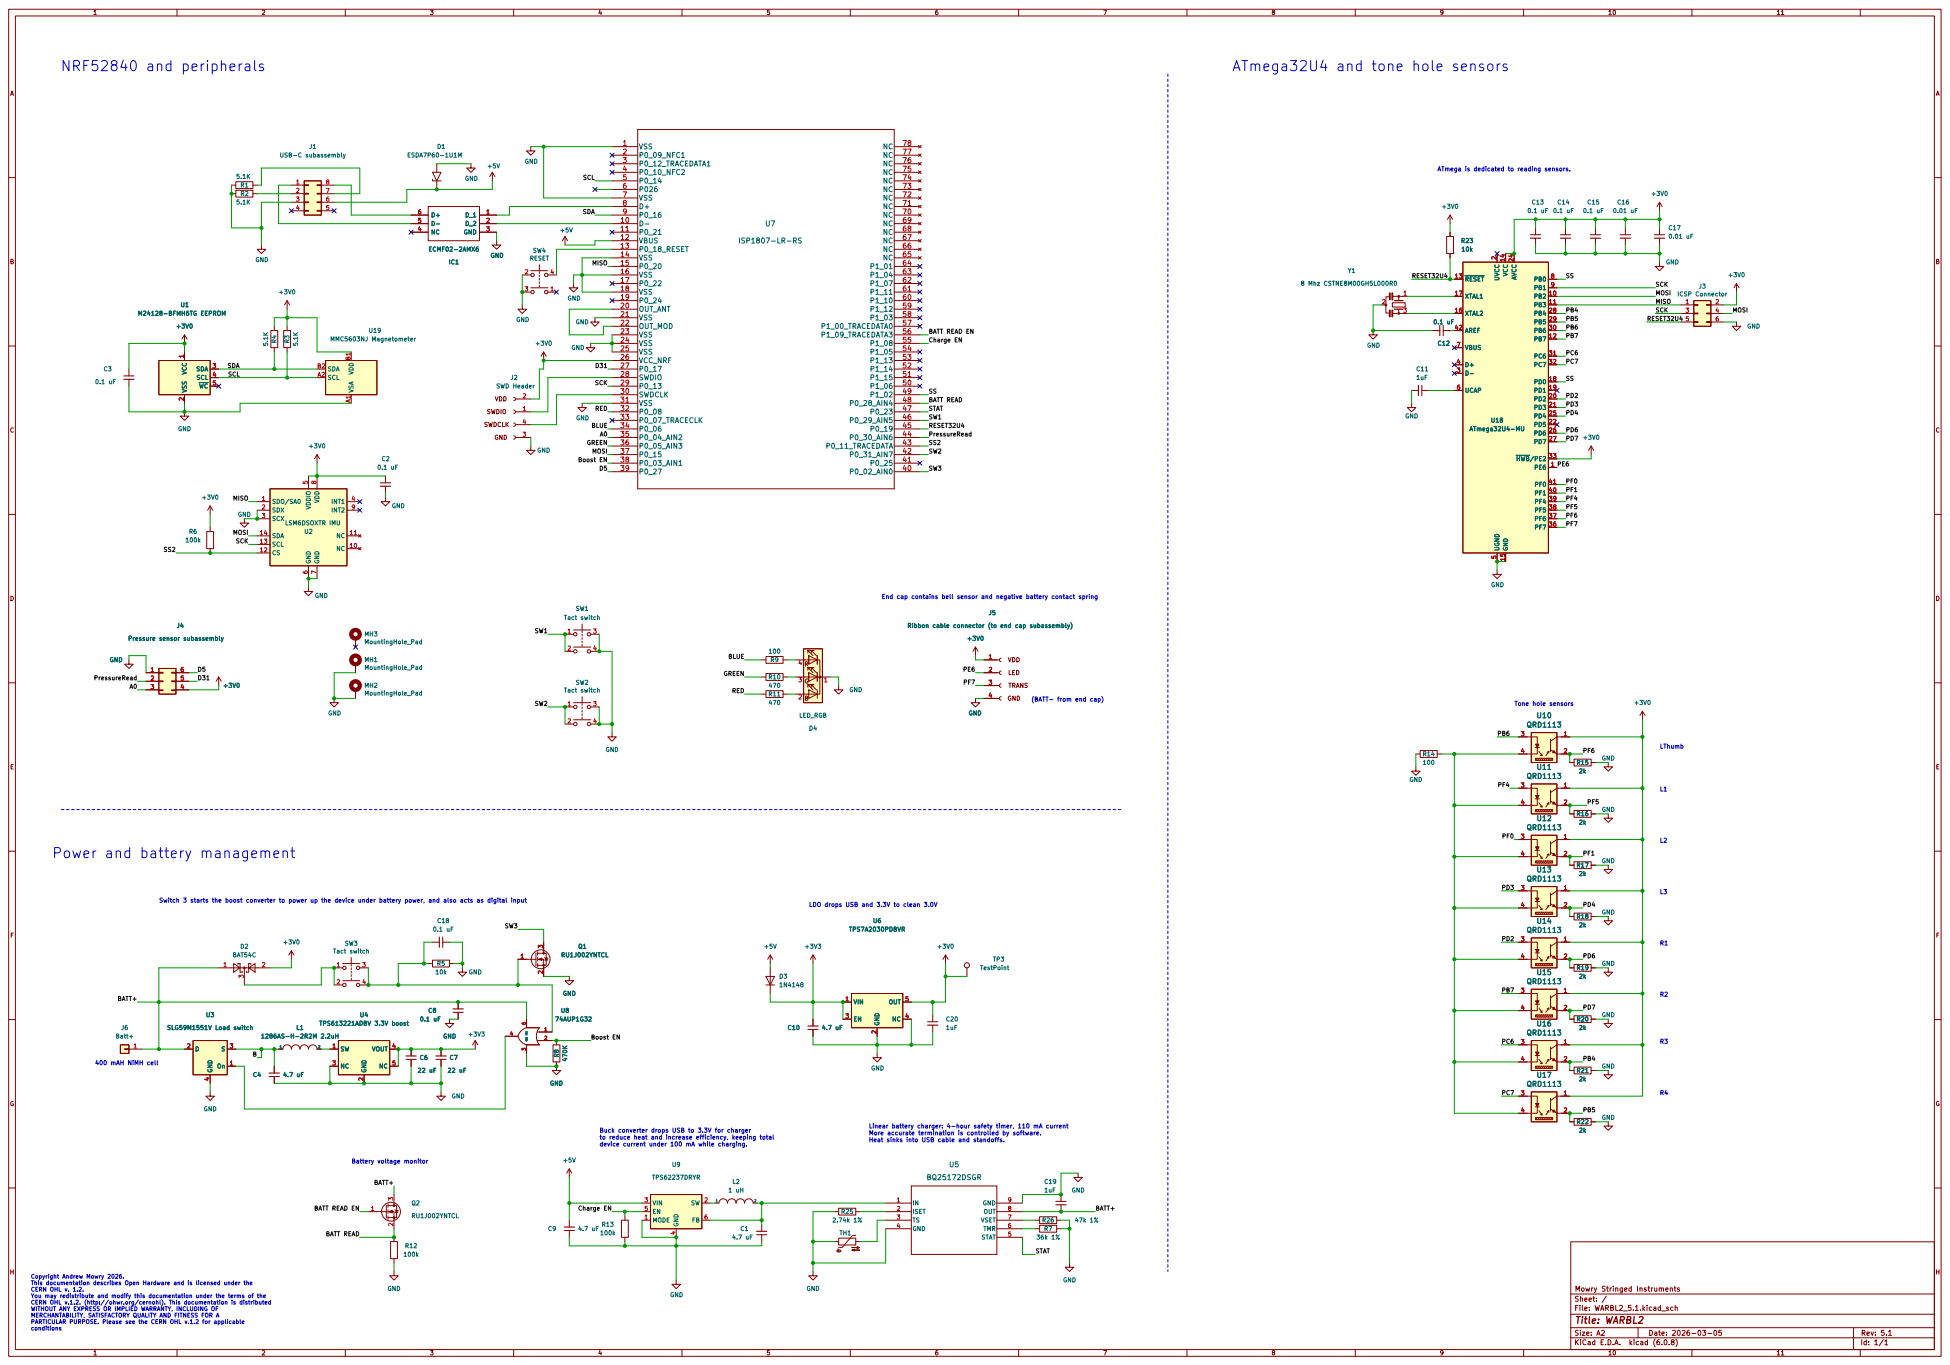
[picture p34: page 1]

ATmega is dedicated to reading sensors.
0.1 uF GND
19 UVCC

2 SDA 3 SCL 4 ~{WC} 5 U1 M24128-BFMH6TG EEPROM
+3V0VCC

End cap contains bell sensor and negative battery contact spring

J5 Ribbon cable connector (to end cap subassembly) +3V0 R10

J5 Ribbon cable connector (to end cap subassembly) 1
4 +3V0 GND

Power and battery management

2 NC 3 VOUT 4 NC 5 U4 TPS613221ADBV 3.3V boost C1

More accurate termination is controlled by software. Heat sinks into USB cable and standoffs. Battery voltage monitor

Buck converter drops USB to 3.3V for charger
to reduce heat and increase efficiency, keeping total
device current under 100 mA while charging.

Linear battery charger: 4-hour safety timer, 110 mA current

Copyright Andrew Mowry 2026. This documentation describes Open Hardware and is licensed under the CERN OHL v. 1.2. You may redistribute and modify this documentation under the terms of the CERN OHL v.1.2. (http://ohwr.org/cernohl). This documentation is distributed WITHOUT ANY EXPRESS OR IMPLIED WARRANTY, INCLUDING OF MERCHANTABILITY, SATISFACTORY QUALITY AND FITNESS FOR A

File: WARBL2_5.1.kicad_sch Sheet: / Mowry Stringed Instruments

PARTICULAR PURPOSE. Please see the CERN OHL v.1.2 for applicable
conditions

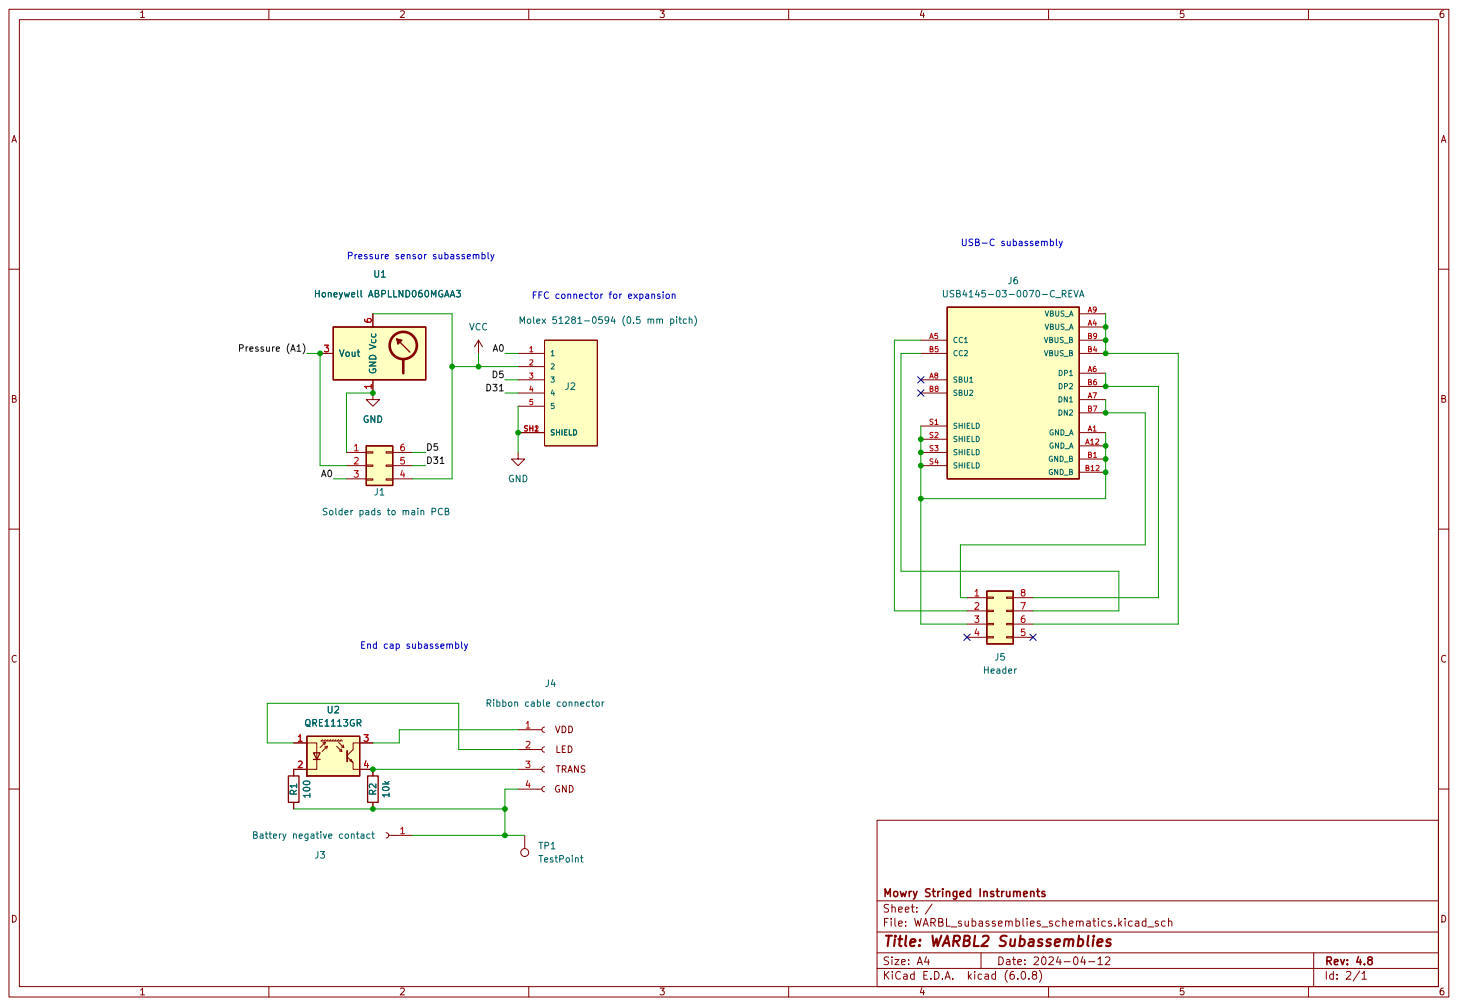
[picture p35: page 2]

FFC connector for expansion

J1 Solder pads to main PCB GND

File: WARBL_subassemblies_schematics.kicad_sch Sheet: / Mowry Stringed Instruments

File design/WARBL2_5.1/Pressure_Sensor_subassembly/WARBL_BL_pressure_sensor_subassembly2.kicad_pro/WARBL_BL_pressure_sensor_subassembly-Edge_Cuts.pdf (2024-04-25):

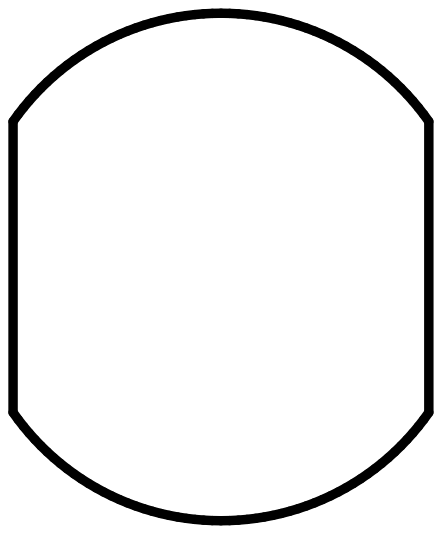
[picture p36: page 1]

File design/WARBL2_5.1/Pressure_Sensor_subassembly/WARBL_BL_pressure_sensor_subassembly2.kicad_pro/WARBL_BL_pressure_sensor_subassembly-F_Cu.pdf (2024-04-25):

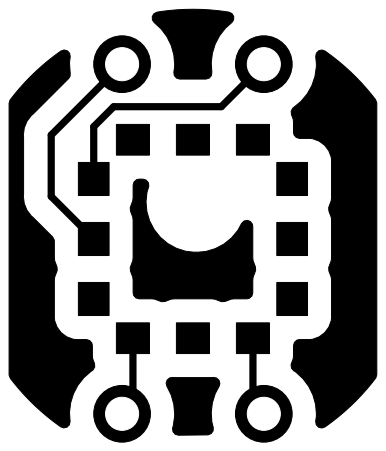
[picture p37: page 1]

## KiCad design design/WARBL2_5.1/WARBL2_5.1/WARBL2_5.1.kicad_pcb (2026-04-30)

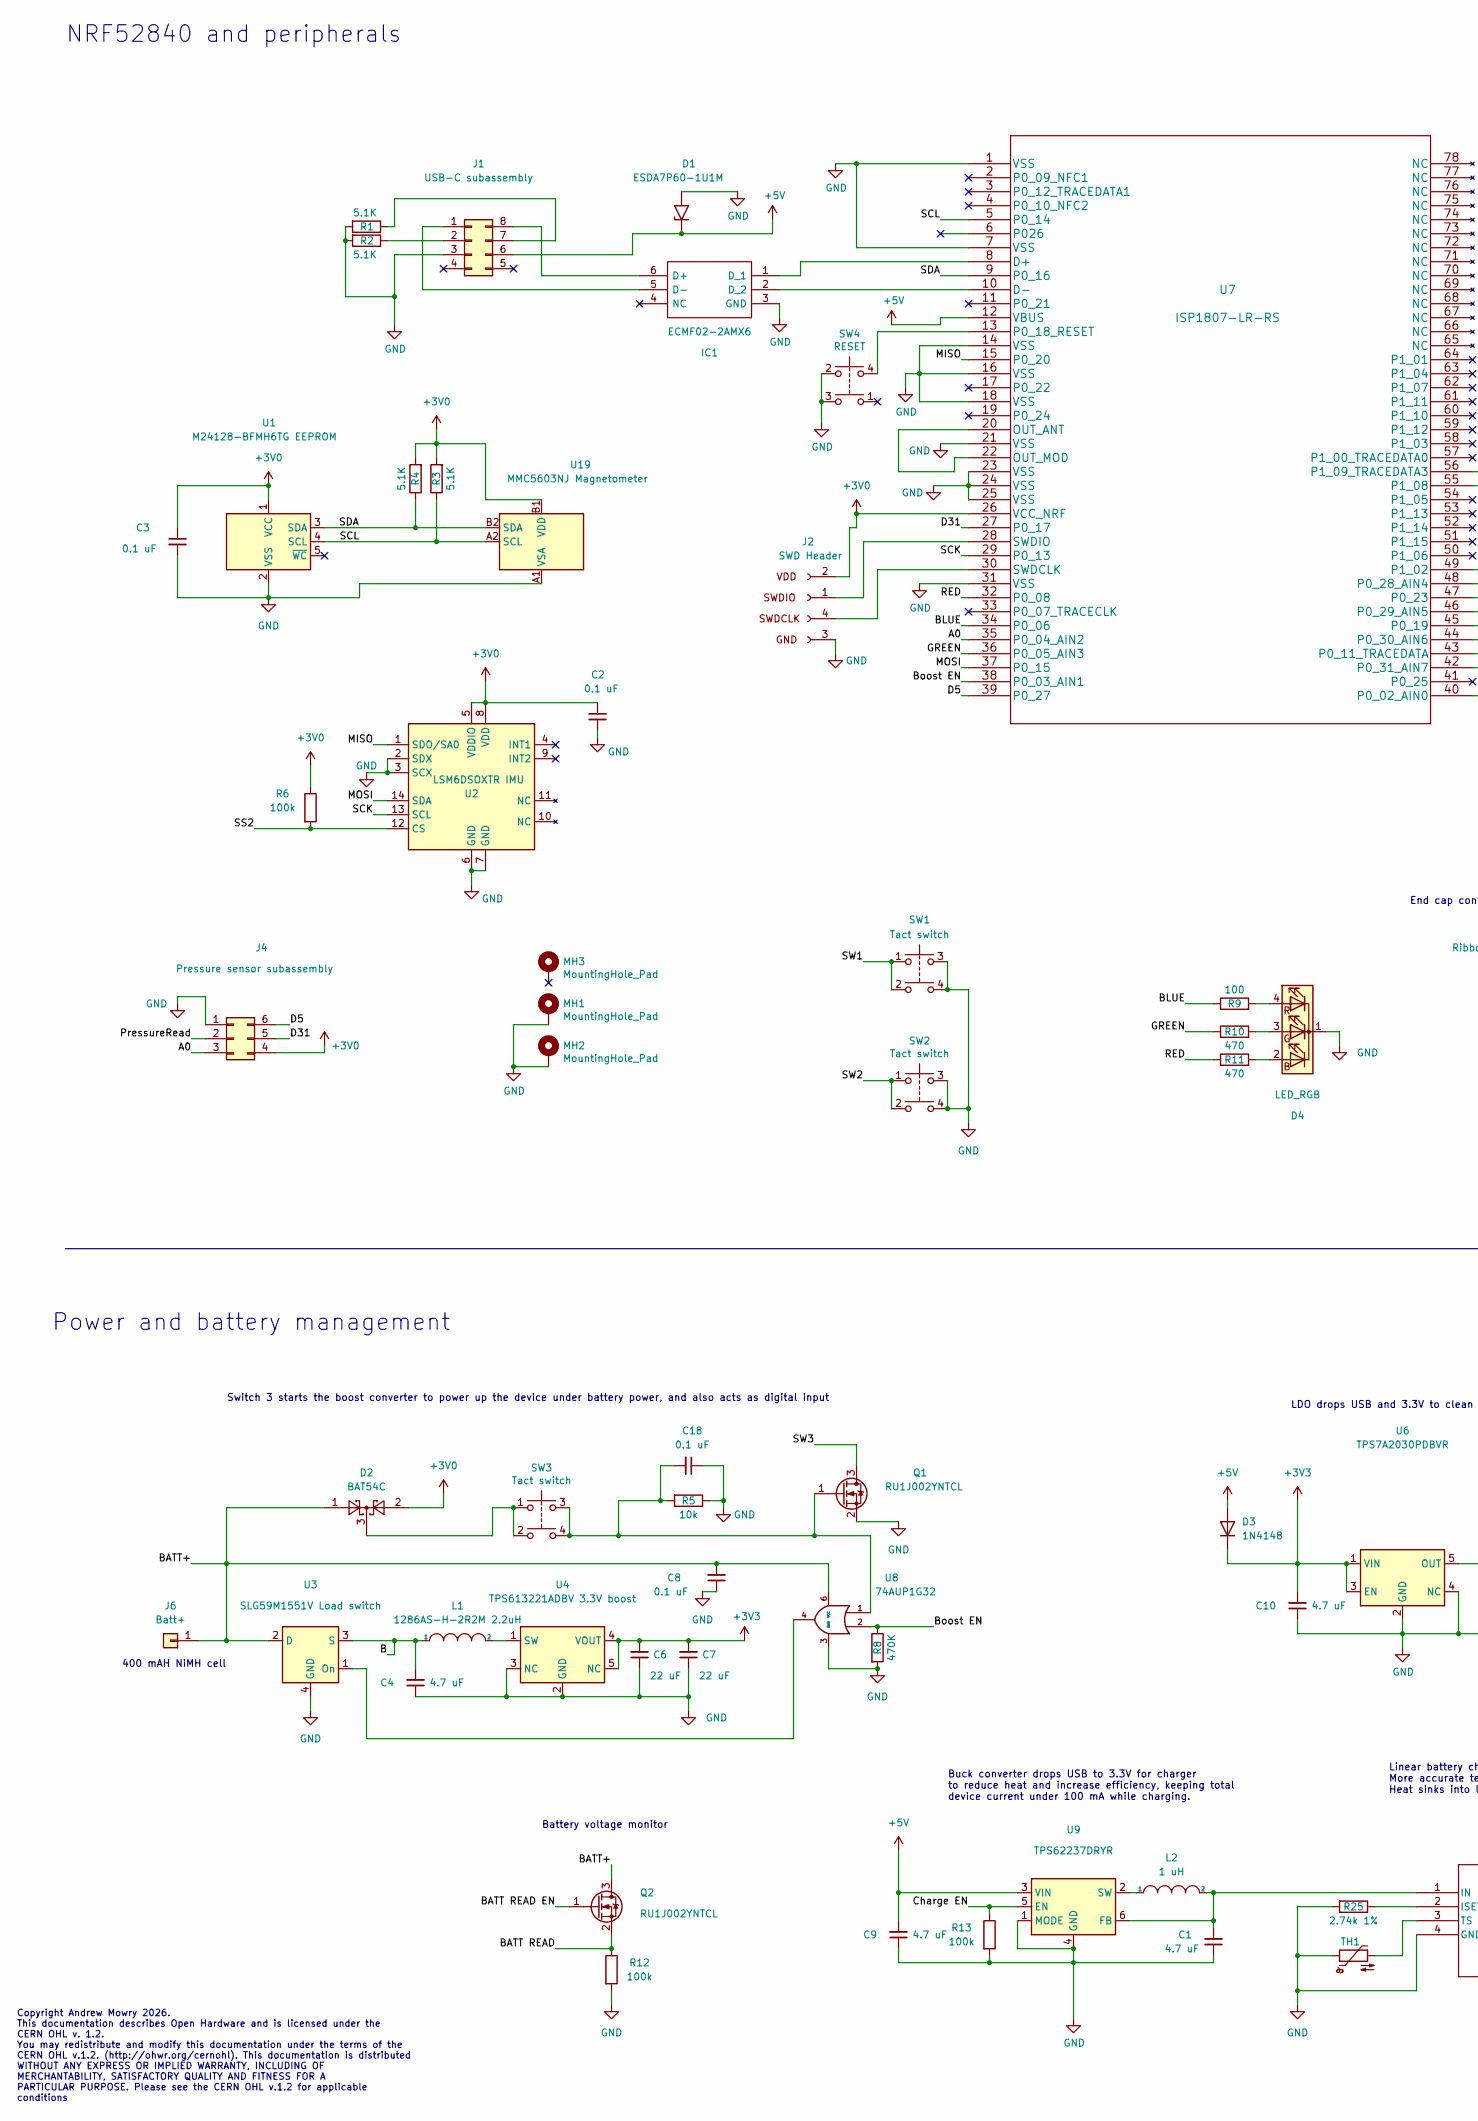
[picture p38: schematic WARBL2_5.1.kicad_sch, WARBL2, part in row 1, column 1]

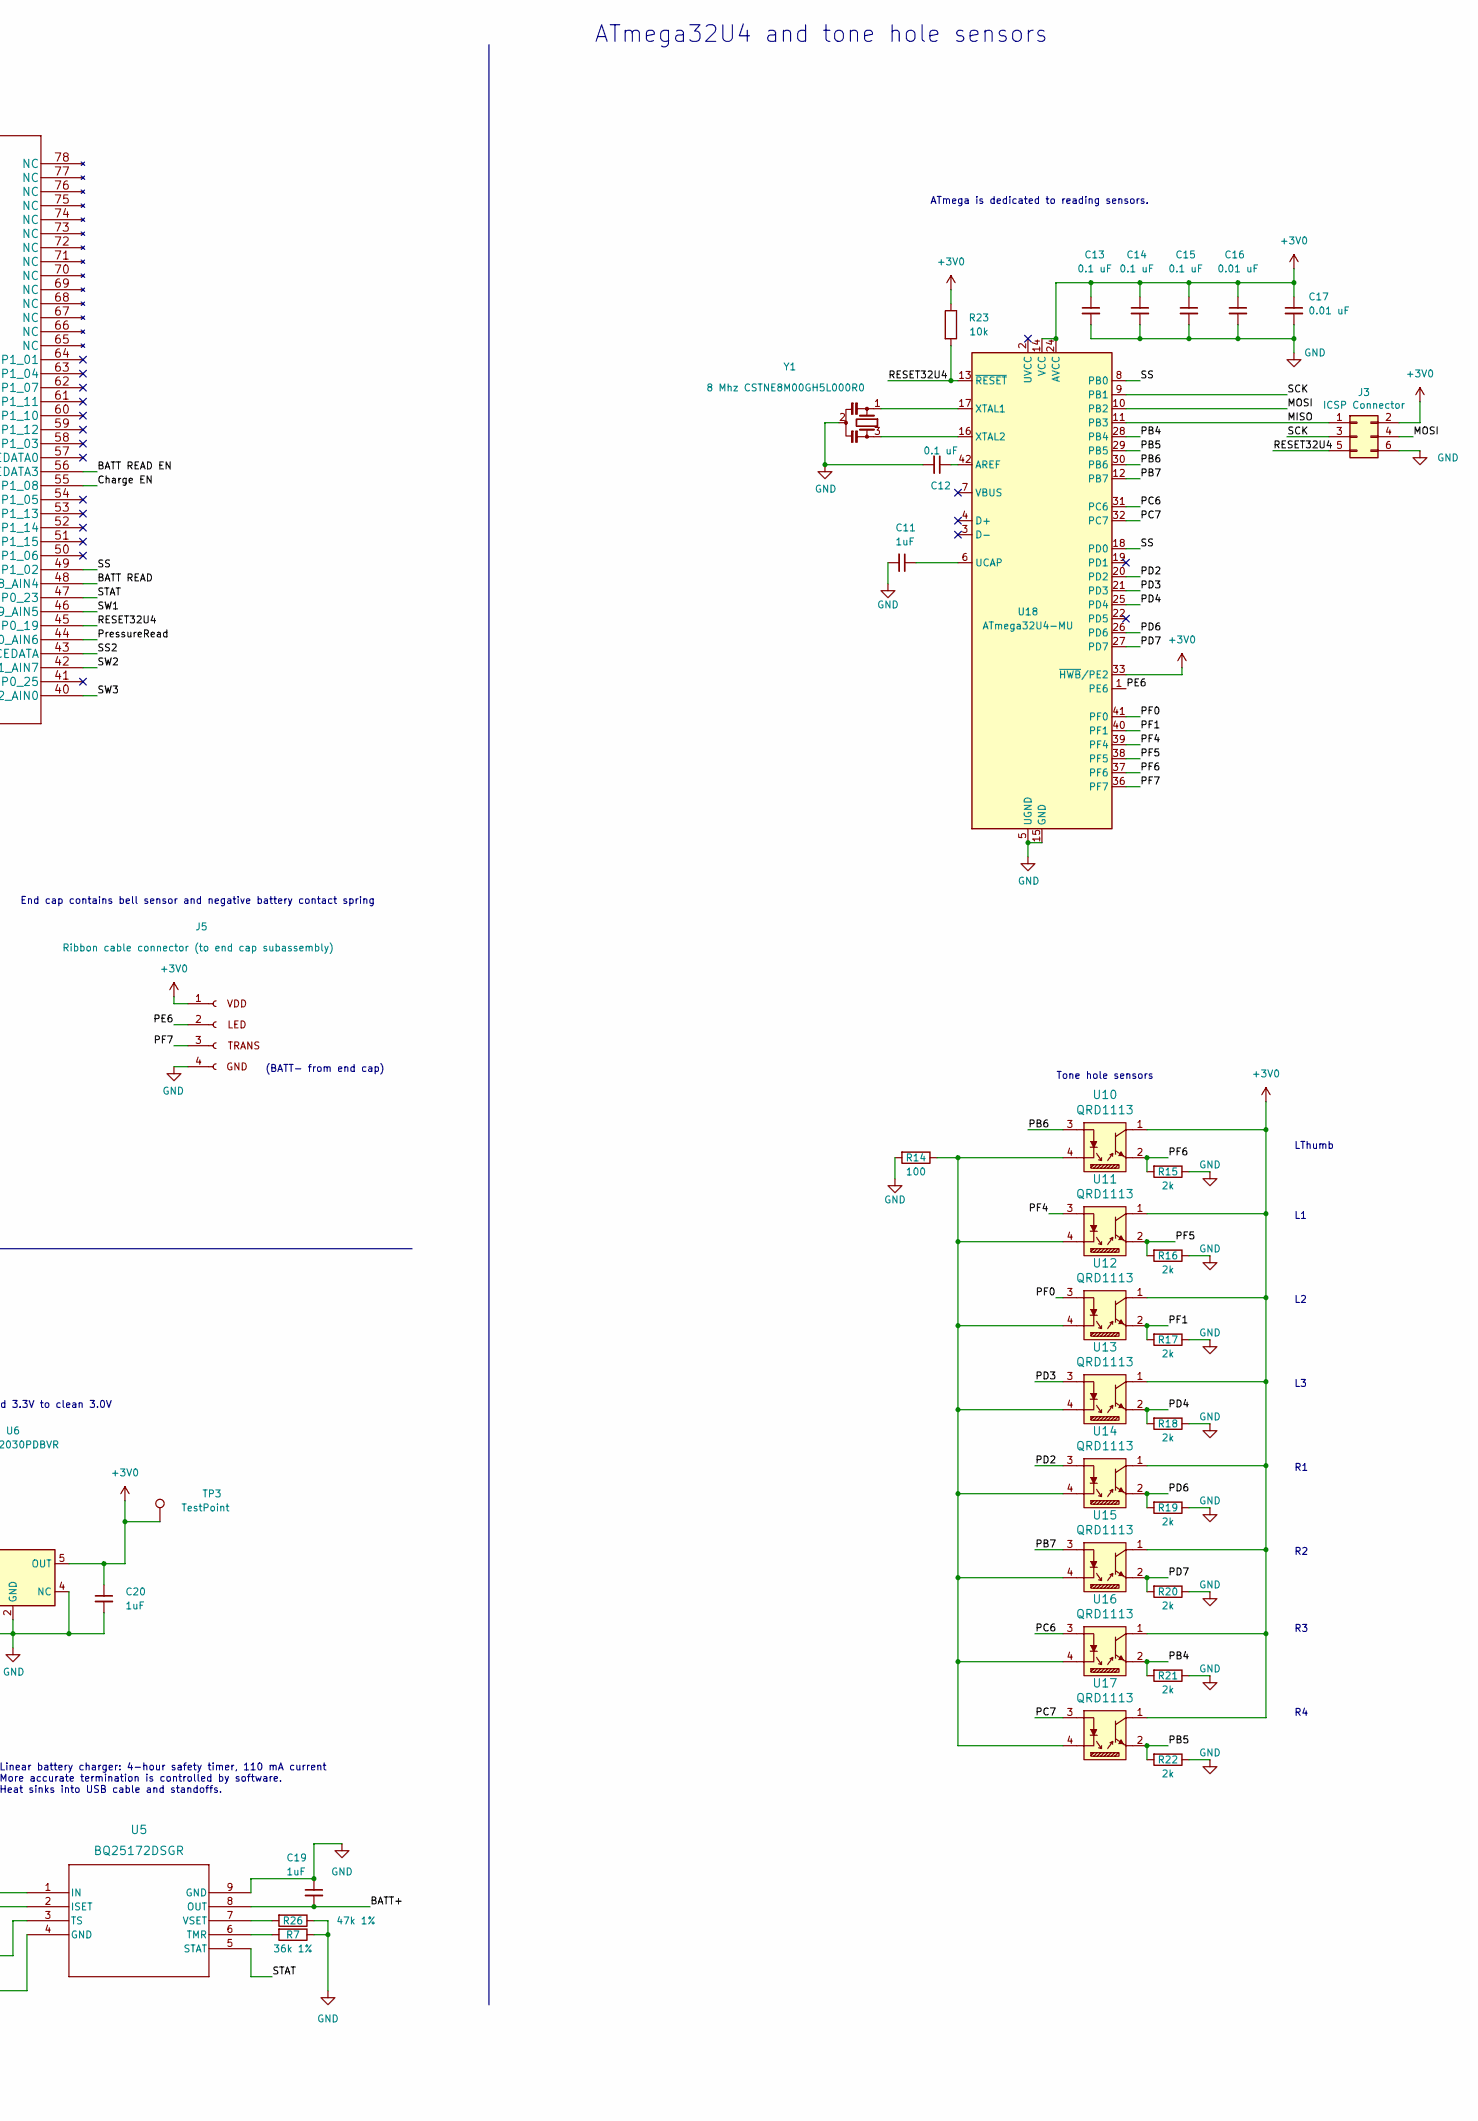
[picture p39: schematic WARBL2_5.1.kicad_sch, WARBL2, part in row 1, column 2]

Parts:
C1, C4, C9, C10: 4.7 uF; C_0603_1608Metric; Mfg Part # C1608X7S1A475K080AC; Digi-Key_PN 445-14258-2-ND
C2, C3, C8, C12, C13, C14, C15, C18: 0.1 uF; C_0603_1608Metric; Mfg Part # CL10F104ZB8NNNC; Digi-Key_PN 1276-1012-2-ND
C6, C7: 22 uF; C_0603_1608Metric; Mfg Part # C1608X5R1A226M080AC; Digi-Key_PN 445-9077-2-ND
C11, C19, C20: 1uF; C_0603_1608Metric; Mfg Part # CL10B105KP8NNNC; Digi-Key_PN 1276-1946-2-ND
C16, C17: 0.01 uF; C_0603_1608Metric; Mfg Part # CL10B103KB8NNNC; Digi-Key_PN 1276-1009-2-ND
D1: ESDA7P60-1U1M; ESDA7P601U1M; Mfg Part # ESDA7P60-1U1M; Digi-Key_PN 497-16253-2-ND
D2: BAT54C; SOT-23; Mfg Part # BAT54C; Digi-Key_PN 1655-BAT54CTR-ND
D3: 1N4148; D_SOD-323; Mfg Part # 1N4148WS; Digi-Key_PN 1655-1N4148WSTR-ND
D4: LED_RGB; LED_LiteOn_LTST-C19HE1WT; Mfg Part # APTF1616SEJ3ZGGVBDC; Digi-Key_PN 754-2166-2-ND
IC1: ECMF02-2AMX6; QFN-6L_STM; Mfg Part # ECMF02-2AMX6; Digi-Key_PN 497-10773-2-ND
J1: USB-C subassembly; PinHeader_2x04_P2.54mm_Vertical; JLCPCB BOM 0
J2: SWD Header; PinHeader_1x04_P2.54mm_Vertical_SMD_Pin1Left; JLCPCB BOM 0
J3: ICSP Connector; SMD_ICSPHeader_Pitch2.54mm; JLCPCB BOM 0
J4: Pressure sensor subassembly; ABPLLND060MGAA3_largepads; JLCPCB BOM 0
J5: Ribbon cable connector (to end cap subassembly); PinHeader_1x04_P2.00mm_Vertical; JLCPCB BOM 0
J6: Batt+; PinHeader_1x01_P1.00mm_Vertical; JLCPCB BOM 0
L1: 1286AS-H-2R2M 2.2uH; INDC2016X120N; Mfg Part # 1286AS-H-2R2M=P2; Digi-Key_PN 490-10605-2-ND
L2: 1 uH; L_0603_1608Metric; Mfg Part # LQM18PZ1R0MCHD; Digi-Key_PN 490-15979-2-ND
MH1, MH2, MH3: MountingHole_Pad; MountingHole__2_56_Pad_small; JLCPCB BOM 0
Q1, Q2: RU1J002YNTCL; SOT-323_SC-70; Mfg Part # RU1J002YNTCL; Digi-Key_PN RU1J002YNTCLTR-ND
R1, R2, R3, R4: 5.1K; R_0603_1608Metric; Mfg Part # ERJ-3EKF5101V; Digi-Key_PN P5.10KHTR-ND
R5, R23: 10k; R_0603_1608Metric; Mfg Part # ERJ-3GEYJ103V; Digi-Key_PN P10KGTR-ND
R6, R12, R13: 100k; R_0603_1608Metric; Mfg Part # ERJ-3GEYJ104V; Digi-Key_PN P100KGTR-ND
R7: 36k 1%; R_0603_1608Metric; Mfg Part # ERJ-3EKF3602V; Digi-Key_PN P36.0KHTR-ND
R8: 470K; R_0603_1608Metric; Mfg Part # ERJ-3GEYJ474V; Digi-Key_PN P470KGTR-ND
R9, R14: 100; R_0603_1608Metric; Mfg Part # ERJ-3GEYJ101V; Digi-Key_PN P100GTR-ND
R10, R11: 470; R_0603_1608Metric; Mfg Part # ERJ-3GEYJ471V; Digi-Key_PN P470GTR-ND
R15, R16, R17, R18, R19, R20, R21, R22: 2k; R_0603_1608Metric; Mfg Part # ERJ-3GEYJ202V; Digi-Key_PN P2.0KGTR-ND
R25: 2.74k 1%; R_0603_1608Metric; Mfg Part # ERJ-3EKF2741V; Digi-Key_PN P2.74KHTR-ND
R26: 47k 1%; R_0603_1608Metric; Mfg Part # ERJ-3EKF4702V; Digi-Key_PN P47.0KHTR-ND
SW1, SW2, SW3: Tact switch; TL3305BF160QG; Mfg Part # PTS647SM50SMTR2LFSTR-ND; Digi-Key_PN PTS647SM50SMTR2LFSTR-ND
SW4: RESET; SW_KMR221GLFS; Mfg Part # KMR211GLFS; Digi-Key_PN 401-1426-2-ND
TH1: NCU18XH103F60RB; R_0603_1608Metric; Mfg Part # NCU18XH103F60RB; Digi-Key_PN 2259-TH11-3H103FTTR-ND
TP3: TestPoint; TestPoint_Pad_D1.0mm; JLCPCB BOM 0
U1: M24128-BFMH6TG EEPROM; UFDFPN5_1P7X1P4_STM; Mfg Part # M24128-BFMH6TG; Digi-Key_PN 497-17565-2-ND
U2: LSM6DSOXTR IMU; LGA-14L_2P5X3X0P83_STM; Mfg Part # LSM6DSOXTR; Digi-Key_PN 497-18367-2-ND
U3: SLG59M1551V Load switch; VLGA-4_2x2.5mm_P1.65mm; Mfg Part # SLG59M1551V; Digi-Key_PN 1827-1074-2-ND
U4: TPS613221ADBV 3.3V boost; DBV0005A_L; Mfg Part # TPS613221ADBVT; Digi-Key_PN 296-49467-2-ND
U5: BQ25172DSGR; WSON8_DSG008A_BQ_TEX; Mfg Part # BQ25172DSGR; Digi-Key_PN 296-BQ25172DSGRTR-ND
U6: TPS7A2030PDBVR; DBV0005A_L; Mfg Part # TPS7A2030PDBVR; Digi-Key_PN 296-TPS7A2030PDBVRTR-ND
U7: ISP1807-LR-RS; Mfg Part # ISP1807-LR-RS; Digi-Key_PN 1786-1019-2-ND
U8: 74AUP1G32; DSF6; Mfg Part # SN74AUP1G32DSFR; Digi-Key_PN 296-27310-2-ND
U9: TPS62237DRYR; DRY0006A; Mfg Part # TPS62237DRYR; Digi-Key_PN 296-39454-2-ND
U10, U11, U12, U13, U14, U15, U16, U17: QRD1113; Reflective_Sensor_QRD1114; Digi-Key_PN QRD1113
U18: ATmega32U4-MU; QFN-44-1EP_7x7mm_P0.5mm_EP5.2x5.2mm; Mfg Part # ATMEGA32U4-MUR; Digi-Key_PN ATMEGA32U4-MURTR-ND
U19: MMC5603NJ Magnetometer; WLP-4_0.86x0.86mm_P0.4mm
Y1: 8 Mhz CSTNE8M00GH5L000R0; CSTNE8M00GH5L000R0_MUR; Mfg Part # CSTNE8M00GH5L000R0; Digi-Key_PN 490-17962-2-ND

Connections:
+3V0: C2.1, C3.1, C13.1, C14.1, C15.1, C16.1, C17.1, C20.1, D2.2, J2.2 (VDD), J3.2, J4.4, J5.1 (VDD), R3.2, R4.2, R6.1, R23.1, TP3.1, U1.1 (VCC), U2.5 (VDDIO), U2.8 (VDD), U6.5 (OUT), U7.26 (VCC_NRF), U10.1, U11.1, U12.1, U13.1, U14.1, U15.1, U16.1, U17.1, U18.14 (VCC), U18.24 (AVCC), U18.33 (~HWB/PE2), U18.34 (VCC), U18.44 (AVCC), U19.B1 (VDD)
+3V3: C6.2, C7.2, C10.2, D3.1 (K), U4.4 (VOUT), U4.5 (NC), U6.1 (VIN), U6.3 (EN)
+5V: C9.2, D1.1 (A1), D3.2 (A), J1.6, U7.12 (VBUS), U9.3 (VIN)
/A0: J4.3, U7.35 (P0_04_AIN2)
/B: C4.2, L1.1, U3.3 (S)
/BATT READ: Q2.2 (S), R12.1, U7.48 (P0_28_AIN4)
/BATT READ EN: Q2.1 (G), U7.56 (P1_09_TRACEDATA3)
/BATT+: C8.2, C19.2, D2.1, J6.1, Q2.3 (D), U3.2 (D), U5.8 (OUT), U8.6 (VCC)
/BLUE: R9.1, U7.34 (P0_06)
/Boost EN: R8.1, U7.38 (P0_03_AIN1), U8.2
/Charge EN: R13.1, U7.55 (P1_08), U9.5 (EN)
/D5: J4.6, U7.39 (P0_27)
/D31: J4.5, U7.27 (P0_17)
/GREEN: R10.1, U7.36 (P0_05_AIN3)
/MISO: J3.1, U2.1 (SDO/SA0), U7.15 (P0_20), U18.11 (PB3)
/MOSI: J3.4, U2.14 (SDA), U7.37 (P0_15), U18.10 (PB2)
/PB4: R21.2, U16.2, U18.28 (PB4)
/PB5: R22.2, U17.2, U18.29 (PB5)
/PB6: U10.3, U18.30 (PB6)
/PB7: U15.3, U18.12 (PB7)
/PC6: U16.3, U18.31 (PC6)
/PC7: U17.3, U18.32 (PC7)
/PD2: U14.3, U18.20 (PD2)
/PD3: U13.3, U18.21 (PD3)
/PD4: R18.2, U13.2, U18.25 (PD4)
/PD6: R19.2, U14.2, U18.26 (PD6)
/PD7: R20.2, U15.2, U18.27 (PD7)
/PE6: J5.2 (SWDIO), U18.1 (PE6)
/PF0: U12.3, U18.41 (PF0)
/PF1: R17.2, U12.2, U18.40 (PF1)
/PF4: U11.3, U18.39 (PF4)
/PF5: R16.2, U11.2, U18.38 (PF5)
/PF6: R15.2, U10.2, U18.37 (PF6)
/PF7: J5.3 (SWDCLK), U18.36 (PF7)
/PressureRead: J4.2, U7.44 (P0_30_AIN6)
/RED: R11.1, U7.32 (P0_08)
/RESET32U4: J3.5, R23.2, U7.45 (P0_19), U18.13 (~RESET)
/SCK: J3.3, U2.13 (SCL), U7.29 (P0_13), U18.9 (PB1)
/SCL: R3.1, U1.4 (SCL), U7.5 (P0_14), U19.A2 (SCL)
/SDA: R4.1, U1.3 (SDA), U7.9 (P0_16), U19.B2 (SDA)
/SS: U7.49 (P1_02), U18.8 (PB0), U18.18 (PD0)
/SS2: R6.2, U2.12 (CS), U7.43 (P0_11_TRACEDATA)
/STAT: U5.5 (STAT), U7.47 (P0_23)
/SW1: SW1.1, SW1.2, U7.46 (P0_29_AIN5)
/SW2: SW2.1, SW2.2, U7.42 (P0_31_AIN7)
/SW3: Q1.3 (D), U7.40 (P0_02_AIN0)
GND: C1.1, C2.2, C3.2, C4.1, C6.1, C7.1, C8.1, C9.1, C10.1, C11.2, C12.2, C13.2, C14.2, C15.2, C16.2, C17.2, C18.1, C19.1, C20.2, D1.2 (A2), D4.1 (K), IC1.3 (GND), J1.3, J2.3 (GND), J3.6, J4.1, J5.4 (GND), MH1.1, MH2.1, Q1.2 (S), R1.2, R2.2, R5.1, R7.1, R8.2, R12.2, R13.2, R14.2, R15.1, R16.1, R17.1, R18.1, R19.1, R20.1, R21.1, R22.1, R25.2, R26.1, SW1.3, SW1.4, SW2.3, SW2.4, SW4.2, SW4.3, TH1.1, U1.2 (VSS), U2.2 (SDX), U2.3 (SCX), U2.6 (GND), U2.7 (GND), U3.4 (GND), U4.2 (GND), U4.3 (NC), U5.4 (GND), U5.9 (GND), U6.2 (GND), U6.4 (NC), U7.1 (VSS), U7.7 (VSS), U7.14 (VSS), U7.16 (VSS), U7.18 (VSS), U7.21 (VSS), U7.23 (VSS), U7.24 (VSS), U7.25 (VSS), U7.31 (VSS), U8.3 (GND), U9.1 (MODE), U9.4 (GND), U18.5 (UGND), U18.15 (GND), U18.23 (GND), U18.35 (GND), U18.43 (GND), U18.45 (GND), U19.A1 (VSA), Y1.2
unnamed: C1.2, L2.2, U5.1 (IN), U9.6 (FB)
unnamed: C11.1, U18.6 (UCAP)
unnamed: C12.1, U18.42 (AREF)
unnamed: C18.2, Q1.1 (G), R5.2, SW3.3, SW3.4, U8.1
unnamed: D2.3, SW3.1, SW3.2
unnamed: D4.2 (BA), R11.2
unnamed: D4.3 (GA), R10.2
unnamed: D4.4 (RA), R9.2
unnamed: IC1.1 (D_1), U7.8 (D+)
unnamed: IC1.2 (D_2), U7.10 (D-)
unnamed: IC1.5 (D-), J1.1
unnamed: IC1.6 (D+), J1.8
unnamed: J1.2, R2.1
unnamed: J1.7, R1.1
unnamed: J2.1 (SWDIO), U7.28 (SWDIO)
unnamed: J2.4 (SWDCLK), U7.30 (SWDCLK)
unnamed: L1.2, U4.1 (SW)
unnamed: L2.1, U9.2 (SW)
unnamed: R7.2, U5.6 (TMR)
unnamed: R14.1, U10.4, U11.4, U12.4, U13.4, U14.4, U15.4, U16.4, U17.4
unnamed: R25.1, U5.2 (ISET)
unnamed: R26.2, U5.7 (VSET)
unnamed: SW4.4, U7.13 (P0_18_RESET)
unnamed: TH1.2, U5.3 (TS)
unnamed: U3.1 (On), U8.4
unnamed: U7.20 (OUT_ANT), U7.22 (OUT_MOD)
unnamed: U18.16 (XTAL2), Y1.3
unnamed: U18.17 (XTAL1), Y1.1

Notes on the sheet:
Battery voltage monitor
Switch 3 starts the boost converter to power up the device under battery power, and also acts as digital input
400 mAH NiMH cell
Power and battery management
Copyright Andrew Mowry 2026. This documentation describes Open Hardware and is licensed under the CERN OHL v. 1.2. You may redistribute and modify this documentation under the terms of the CERN OHL v.1.2. (http://ohwr.org/cernohl). This documentation is distributed WITHOUT ANY EXPRESS OR IMPLIED WA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
(BATT- from end cap)
End cap contains bell sensor and negative battery contact spring
LDO drops USB and 3.3V to clean 3.0V
Buck converter drops USB to 3.3V for charger to reduce heat and increase efficiency, keeping total device current under 100 mA while charging.
ATmega32U4 and tone hole sensors
Linear battery charger: 4-hour safety timer, 110 mA current More accurate termination is controlled by software. Heat sinks into USB cable and standoffs.
NRF52840 and peripherals
Tone hole sensors
ATmega is dedicated to reading sensors.
LThumb

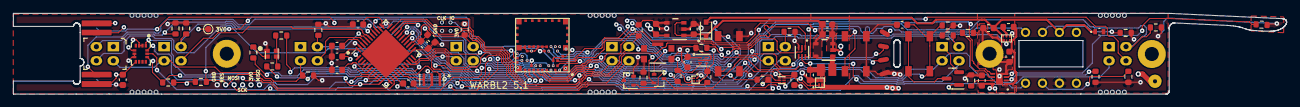
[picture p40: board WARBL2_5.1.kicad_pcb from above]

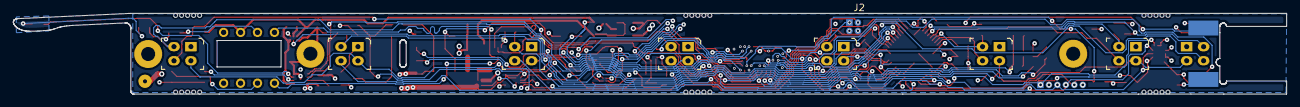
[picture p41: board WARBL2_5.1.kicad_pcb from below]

Board: 4 copper layers, 190.8 x 12.1 mm, 94 parts (9 on the bottom side), 75 nets.

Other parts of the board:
84, 84#2, 84#3, 84#4, 84#5, 84#6: (no value)

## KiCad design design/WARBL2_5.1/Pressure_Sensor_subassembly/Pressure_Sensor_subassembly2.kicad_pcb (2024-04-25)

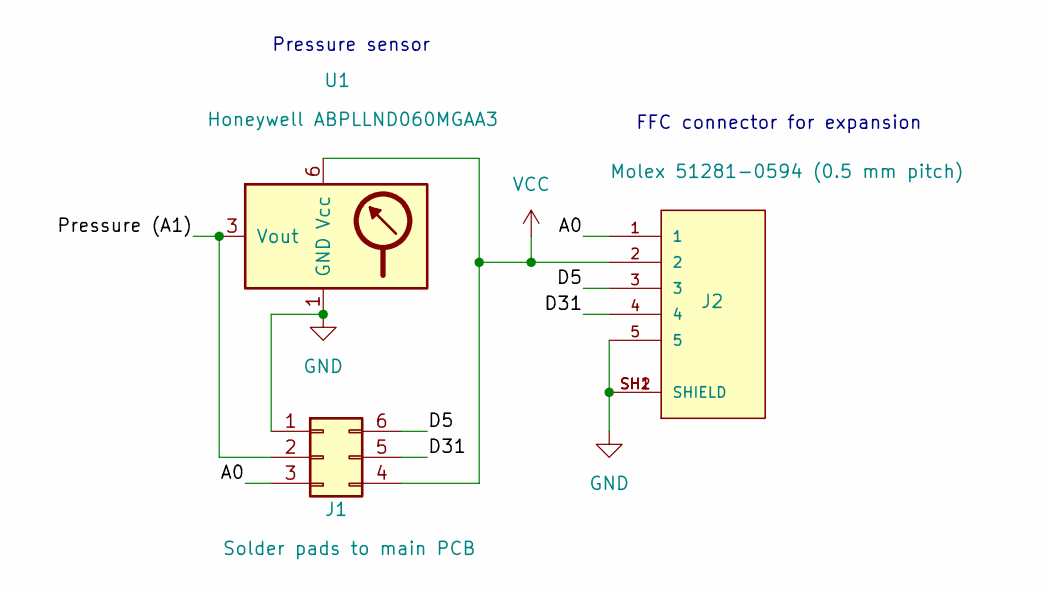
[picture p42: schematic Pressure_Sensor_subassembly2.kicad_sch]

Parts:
J1: Solder pads to main PCB; ABPLLND060MGAA3_largepads
J2: Molex 51281-0594 (0.5 mm pitch); MOLEX_51281-0594; PARTREV J
U1: Honeywell ABPLLND060MGAA3; ABPsensor

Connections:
/A0: J1.3, J2.1
/D5: J1.6, J2.3
/D31: J1.5, J2.4
/Pressure (A1): J1.2, U1.3 (Vout)
GND: J1.1, J2.5, J2.SH1 (SHIELD), J2.SH2 (SHIELD), U1.1 (GND)
VCC: J1.4, J2.2, U1.6 (Vcc)

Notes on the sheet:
Pressure sensor
FFC connector for expansion

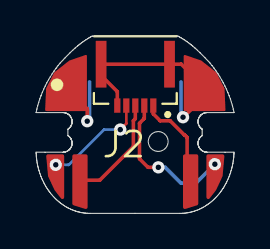
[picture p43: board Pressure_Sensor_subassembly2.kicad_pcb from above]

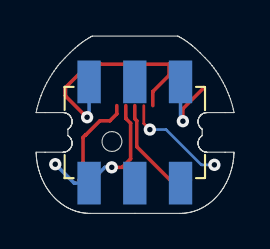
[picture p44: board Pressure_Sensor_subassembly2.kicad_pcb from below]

Board: 2 copper layers, 11.0 x 9.8 mm, 3 parts (2 on the bottom side), 6 nets.

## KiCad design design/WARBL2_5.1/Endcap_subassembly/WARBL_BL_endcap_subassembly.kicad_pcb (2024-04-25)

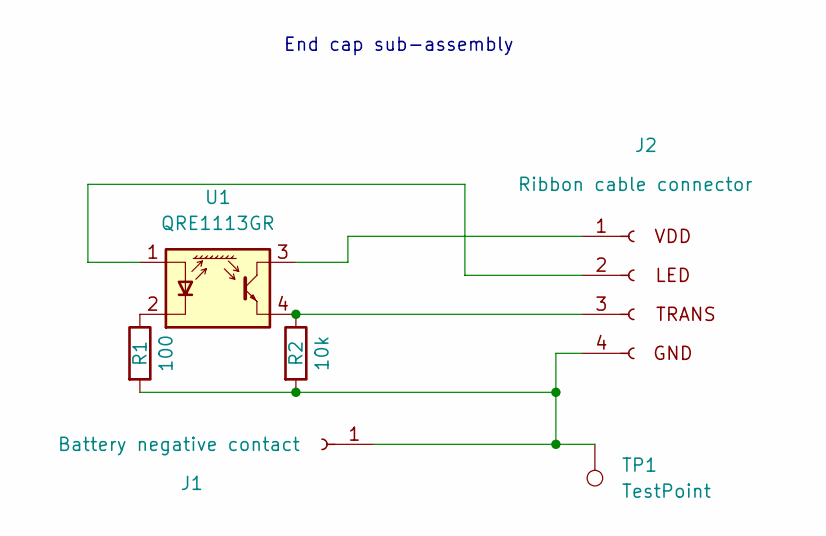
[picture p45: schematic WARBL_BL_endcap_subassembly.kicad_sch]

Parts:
J1: Battery negative contact; Batt contact
J2: Ribbon cable connector; Ribbon_connector
R1: 100; R_0603_1608Metric; Mfg Part # ERJ-3GEYJ101V
R2: 10k; R_0603_1608Metric; Mfg Part # ERJ-3GEYJ103V
TP1: TestPoint; Batt_spring_pad
U1: QRE1113GR; SMD4_2P90X3P60_ONS

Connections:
unnamed: J1.1, J2.4 (GND), R1.2, R2.2, TP1.1
unnamed: J2.1 (VDD), U1.3
unnamed: J2.2 (SWDIO), U1.1 (A)
unnamed: J2.3 (SWDCLK), R2.1, U1.4
unnamed: R1.1, U1.2 (K)

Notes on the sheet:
End cap sub-assembly

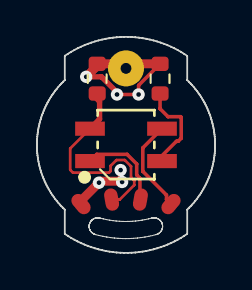
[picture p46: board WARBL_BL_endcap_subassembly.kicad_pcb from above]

Board: 2 copper layers, 9.9 x 12.0 mm, 6 parts (1 on the bottom side), 5 nets.

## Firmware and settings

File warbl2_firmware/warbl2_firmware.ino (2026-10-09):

/*
    Copyright (C) 2018-2024 Andrew Mowry warbl.xyz

    Many thanks to Michael Eskin, Jesse Chappell, Gerard Kilbride, Louis Barman, Randy George, Gianluca Barbaro, and many other WARBL users for their additions and suggestions.

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

Approximate WARBL2 power budget (at 3.0 V): ~ 2.5 mA for NRF52840, 1.5 mA for ATmega32u4, 3.5 mA for tone hole sensors, 1.5 mA for other peripherals. 8.7 mA total, for ~ 12 hour battery life with 350 mAH battery and 86% efficient boost converter
Power update 8/26: With the newer Bosch pressure sensors and the bell sensor turned off, total consumption is around 7.2 mA, for ~16.5 hour theoretical battery life.

***Notes about the FFC expansion port:
Connector is Molex 0512810598 (see datasheet for cable design): https://tools.molex.com/pdm_docs/sd/512810598_sd.pdf
An example of an off-the-shelf cable is GCT 05-05-A-0050-A-4-06-4-T.
Pinout from left to right, holding WARBL with mouthpiece pointing up, looking at the port: GND, D31, D5, 3V0, A0/D14. A0 can be used for reading an analog sensor, and any of the GPIO can be used at high speed for I2S, software I2C, etc. If reading a sensor, it's recommended to conserve battery life by using a digital pin to turn the sensor on only when needed. 


*/

#include "Defines.h"

// Installed with board package
#include <nrfx_power.h>  // For detecting VBUS
#include <nrf_wdt.h>     // Watchdog timer
#include <bluefruit.h>
#include <Arduino.h>
#include <Wire.h>  // I2C communication with EEPROM
#include <SPI.h>   // Communication with ATmega32U4 and IMU
#include <math.h>
#include "Adafruit_LittleFS.h"
#include "InternalFileSystem.h"

// Libraries below may need to be installed.
#include <MIDI.h>
#include <Adafruit_LSM6DSOX.h>     //IMU
#include <SensorFusion.h>          // IMU fusion
#include <ResponsiveAnalogRead.h>  // Fast smoothing of 12-bit pressure sensor readings
#include <Adafruit_BMP5xx.h>       // Modify this library (Adafruit_BMP5xx.cpp line 94) to read at 8 Mhz SPI speed. For newer Bosch BMP585/580/581 pressure sensors.

// Create instances of library classes.
BLEDis bledis;
BLEMidi blemidi;
Adafruit_USBD_MIDI usb_midi;
Adafruit_LSM6DSOX sox;
SF sfusion;
#if defined(PROTOTYPE46)
ResponsiveAnalogRead analogPressure(A0, true);
#else
ResponsiveAnalogRead analogPressure(A1, true);
#endif
Adafruit_BMP5xx bmp;
Adafruit_BMP5xx bmpAmbient;

// Filtering
ResponsiveAnalogRead filterToneholes[9];


// Custom settings for MIDI library
struct MySettings : public MIDI_NAMESPACE::DefaultSettings {
    static const bool Use1ByteParsing = false;  //parse more than 1 byte per MIDI.read()
    static const long BaudRate = 31250;         //For MIDI Library 5.0.2
};

// Create instances of the Arduino MIDI Library classes.
MIDI_CREATE_CUSTOM_INSTANCE(BLEMidi, blemidi, BLEMIDI, MySettings);
MIDI_CREATE_CUSTOM_INSTANCE(Adafruit_USBD_MIDI, usb_midi, MIDI, MySettings);


// GPIO constants
const uint8_t LEDpins[] = { 8, 10, 3 };  // RGB. Blue is also LED_BUILTIN.
const uint8_t powerEnable = 19;          // Driving this high enables the boost converter, keeping the device powered from the battery after button 3 has been released.
const uint8_t chargeEnable = 7;          // Enables charging.
#if defined(PROTOTYPE46)
const uint8_t STAT = 15;  // Battery charger STAT pin for early prototype
#else
const uint8_t STAT = 27;  // Battery charger STAT pin
#endif
const uint8_t battReadEnable = 6;         // Driving this high connects the battery to NRF ADC for reading voltage.
const uint8_t battRead = 16;              // Analog pin for reading battery voltage
const uint8_t buttons[] = { 4, 17, 18 };  // Buttons 1, 2, 3

const uint8_t BMP5XX_CS_PIN = 15;          // BMP585 breath sensor pin (newer hardware)
const uint8_t BMP5XX_AMBIENT_CS_PIN = 11;  // BMP580/581 ambient pressure sensor pin (newer hardware)


// Battery variables
unsigned long runTimer;             // The time when WARBL started running on battery power
bool battPower = false;             // Keeps track of when we're on battery power, for above timer
unsigned long fullRunTime = 720;    // The available run time on a full charge, in minutes. This is initialized with an estimate of 12 hours and then adjusted each time the battery is discharged.
unsigned long prevRunTime = 120;    // The total run time since the last full charge (minutes). Initialized at around 80% full (typical of new PKCell battery). It is zeroed after each full charge.
unsigned long powerDownTimer;       // For powering down after a period of no activity
byte USBstatus = 0;                 // Battery power (0), dumb charger (1), or connected USB host (2).
unsigned long chargeStartTime = 0;  // When we started charging.
byte battLevel;                     // Estimated battery percentage remaining
float smoothed_voltage;             // Battery voltage


// BLE
float connIntvl = 0;  // The negotiated connection interval
uint16_t pendingConnHandle = BLE_CONN_HANDLE_INVALID;
uint32_t bleConnectTime = 0;
bool bleIntervalCheckPending = false;
bool bleIntervalReported = false;


// IMU data
float q0 = 1.0f;  // Quaternion
float q1 = 0.0f;
float q2 = 0.0f;
float q3 = 0.0f;
float rawGyroX = 0.0f;
float rawGyroY = 0.0f;
float rawGyroZ = 0.0f;
float gyroX = 0.0f;
float gyroY = 0.0f;
float gyroZ = 0.0f;
float accelX = 0.0f;
float accelY = 0.0f;
float accelZ = 0.0f;
float currYaw = 0.0f;
float currAxisHeading = 0.0f;
float yawOffset = 0.0f;
float axisHeadingOffset;
float IMUtemp = 0.0f;
float gyroXCalibration = 0.0f;
float gyroYCalibration = 0.0f;
float gyroZCalibration = 0.0f;
float roll;
float pitch;
float yaw;
float axisHeading;                 // Compass direction of the long axis of the WARBL
int shakeVibrato;                  // Shake vibrato depth, from -8192 to 8192
int shakePressureCCMod;            // Shake pressure for CC mod: -127 to 127
float shakePressureChanPressMod;   // Shake pressure for chan pressure mod: -127 to 127
int shakePressureKeyPressMod;      // Shake pressure for keypressure mod: -127 to 127
unsigned long autoCenterYawTimer;  // For determining when to auto-recenter the yaw after silence
bool pitchRegisterShifted;         // Whether the register has been shifted by IMU pitch
int pitchRegisterBounds[6];        // Pitch boundaries (in degrees) between registers, i.e. lower bound of register 1, upper bound of register 1, etc. for up to five registers.
bool shakeDetected = 0;
byte yawOutput;                         // This is global because it used by both yaw mapping and sticks preset.
byte prevKey = 0;                       // Used to remember the current key because we'll need to reset it if we're just using it as the hidden way of entering or exiting sticks preset.
unsigned long sticksModeTimer = 20000;  // For timing out the hidden way of entering sticks preset.
bool registerHold = false;              // Locked into the current register, preventing overblowinng.
byte heldRegister;                      // The current register (1 or 2), which is remembered when registerHold is triggered.


// Preset
byte preset = 0;         // The current preset (preset), from 0-2.
byte defaultPreset = 0;  // The default preset, from 0-2.


// WARBL2 variables that are independent of preset
byte WARBL2settings[] = { 2, 1, 5, 0 };  // See defines above
uint8_t WARBL2CustomChart[256];          // The currently selected custom fingering chart. This is only populated if a custom chart is currently selected or if we're transferring a chart from the Config Tool to EEPROM.
int WARBL2CustomChartReceiveByte = 0;    // The byte in the custom chart currently being received from the Config Tool


// Variables that can change according to preset.
int8_t octaveShift = 0;                            // Octave transposition
int8_t noteShift = 0;                              // Note transposition, for changing keys. All fingering patterns are initially based on the key of D, and transposed with this variable to the desired key.
byte pitchBendMode = kPitchBendSlideVibrato;       // 0 means slide and vibrato are on. 1 means only vibrato is on. 2 is all pitchbend off, 3 is legato slide/vibrato.
byte senseDistance = 10;                           // The sensor value above which the finger is sensed for bending notes. Needs to be higher than the baseline sensor readings, otherwise vibrato will be turned on erroneously.
byte breathMode = kPressureBreath;                 // The desired presure sensor behavior: single register, overblow, thumb register control, bell register control.
unsigned int vibratoDepth = 1024;                  // Vibrato depth from 0 (no vibrato) to 8191 (one semitone)
bool useLearnedPressure = 0;                       // Whether we use learned pressure for note on threshold, or we use calibration pressure from startup
byte midiBendRange = 2;                            // +/- semitones that the midi bend range represents
byte mainMidiChannel = MIDI_DEFAULT_MAIN_CHANNEL;  // Current MIDI channel to send notes on
byte overblowSemitones = 5;                        // Number of semitones for overblowing


// These are containers for the above variables, storing the value used by the three different presets.  First variable in array is for preset 0, etc.
byte modeSelector[] = { kModeWhistle, kModeUilleann, kModeGHB };  // The fingering patterns chosen in the configuration tool, for the three presets.
int8_t octaveShiftSelector[] = { 0, 0, 0 };
int8_t noteShiftSelector[] = { 0, 0, 0 };
byte pitchBendModeSelector[] = { 1, 1, 1 };
byte senseDistanceSelector[] = { 10, 10, 10 };
byte breathModeSelector[] = { 1, 1, 0 };
byte useLearnedPressureSelector[] = { 0, 1, 1 };  // Default to using learned pressure for isntruments 2 and 3
int learnedPressureSelector[] = { 0, 280, 475 };  // Some reasonable default bag pressure setting for uilleann and GHB
byte LSBlearnedPressure;                          // Used to reconstruct learned pressure from two MIDI bytes.
unsigned int vibratoHolesSelector[] = { 0b011111111, 0b011111111, 0b011111111 };
unsigned int vibratoDepthSelector[] = { 1024, 1024, 1024 };
byte midiBendRangeSelector[] = { 2, 2, 2 };
byte midiChannelSelector[] = { 1, 1, 1 };

bool momentary[3][3] = { { 0, 0, 0 }, { 0, 0, 0 }, { 0, 0, 0 } };  // Whether momentary click behavior is desired for MIDI on/off message sent with a button. Dimension 0 is preset (preset), dimension 1 is button 0,1,2.

byte switches[3][kSWITCHESnVariables] =              // Settings for the switches in various Config Tool panels (see defines)
  { { 1, 0, 0, 0, 0, 0, 0, 1, 0, 1, 0, 0, 0, 0 },    // Preset 0
    { 0, 0, 0, 0, 0, 0, 0, 1, 0, 1, 0, 0, 0, 0 },    // Preset 1
    { 0, 0, 0, 0, 1, 0, 0, 1, 0, 1, 0, 0, 0, 0 } };  // Preset 2

byte IMUsettings[3][kIMUnVariables] =                                                                                                                                                                                                                                       // Settings for mapping and sending IMU readings (see defines)
  { { 0, 0, 0, 1, 1, 0, 36, 0, 127, 0, 36, 0, 127, 0, 36, 0, 127, 1, 1, 1, 2, 11, 10, 0, 0, 1, 0, 50, 0, 90, 2, 0, 0, 0, 0, 0, 50, 50, 50, 0, 0, 0, 11, 25, 16, 20, 14, 114, 1, 64, 64, 4, 19, 9, 14, 14, 114, 1, 64, 64, 14, 22, 17, 19, 14, 114, 1, 64, 64, 0, 0, 0 },    // Preset 0
    { 0, 0, 0, 1, 1, 0, 36, 0, 127, 0, 36, 0, 127, 0, 36, 0, 127, 1, 1, 1, 2, 11, 10, 0, 0, 1, 0, 50, 0, 90, 2, 0, 0, 0, 0, 0, 50, 50, 50, 0, 0, 0, 11, 25, 16, 20, 14, 114, 1, 64, 64, 4, 19, 9, 14, 14, 114, 1, 64, 64, 14, 22, 17, 19, 14, 114, 1, 64, 64, 0, 0, 0 },    // Preset 1
    { 0, 0, 0, 1, 1, 0, 36, 0, 127, 0, 36, 0, 127, 0, 36, 0, 127, 1, 1, 1, 2, 11, 10, 0, 0, 1, 0, 50, 0, 90, 2, 0, 0, 0, 0, 0, 50, 50, 50, 0, 0, 0, 11, 25, 16, 20, 14, 114, 1, 64, 64, 4, 19, 9, 14, 14, 114, 1, 64, 64, 14, 22, 17, 19, 14, 114, 1, 64, 64, 0, 0, 0 } };  // Preset 2

byte ED[3][kEXPRESSIONnVariables] =                                                                                                                                                                                                                                            // Many settings in the Configuration Tool (see defines).
  { { 0, 3, 0, 0, 1, 2, 0, 100, 0, 127, 0, 1, 51, 36, 0, 1, 51, 0, 0, 0, 0, 0, 100, 0, 127, 0, 100, 0, 127, 0, 100, 0, 127, 0, 0, 0, 0, 20, 2, 7, 11, (64 - 35), (64 + 50), 8, 1, 64, 40, 0, 255, 12, 0, 50, 50, 100, 15, 15, 0, 0, 1, 0, 50, 50, 100, 64, 64, 64, 64, 1 },    // Preset 0
    { 0, 3, 0, 0, 1, 2, 0, 100, 0, 127, 0, 1, 51, 36, 0, 1, 51, 0, 0, 0, 0, 0, 100, 0, 127, 0, 100, 0, 127, 0, 100, 0, 127, 0, 0, 0, 0, 20, 2, 7, 11, (64 - 35), (64 + 50), 8, 1, 64, 40, 0, 255, 12, 0, 50, 50, 100, 15, 15, 0, 0, 1, 0, 50, 50, 100, 64, 64, 64, 64, 1 },    // Preset 1
    { 0, 3, 0, 0, 1, 2, 0, 100, 0, 127, 0, 1, 51, 36, 0, 1, 51, 0, 0, 0, 0, 0, 100, 0, 127, 0, 100, 0, 127, 0, 100, 0, 127, 0, 0, 0, 0, 20, 2, 7, 11, (64 - 35), (64 + 50), 8, 1, 64, 40, 0, 255, 12, 0, 50, 50, 100, 15, 15, 0, 0, 1, 0, 50, 50, 100, 64, 64, 64, 64, 1 } };  // Preset 2

byte pressureSelector[3][12] =                         // Register control variables that can be changed in the Configuration Tool, Dimension 2 is variable: Bag: threshold, multiplier, hysteresis, (unused), jump time, drop time. Breath/mouthpiece: threshold, multiplier, hysteresis, transientFilter, jump time, drop time.
  { { 50, 20, 20, 15, 50, 75, 3, 7, 20, 0, 3, 10 },    // Preset 0
    { 50, 20, 20, 15, 50, 75, 3, 7, 20, 0, 3, 10 },    // Preset 1
    { 50, 20, 20, 15, 50, 75, 3, 7, 20, 0, 3, 10 } };  // Preset 2

uint8_t buttonPrefs[3][kGESTURESnVariables][5] =                                                                                                                                                          // The button configuration settings. Dimension 1 is the three presets. Dimension 2 is the button combination (see button/gesture defines). Dimension 3 is the desired result: Action, MIDI command type (noteon/off, CC, PC), MIDI channel, MIDI byte 2, MIDI byte 3.
  { { { 0, 0, 0, 0, 0 }, { 0, 0, 0, 0, 0 }, { 0, 0, 0, 0, 0 }, { 0, 0, 0, 0, 0 }, { 0, 0, 0, 0, 0 }, { 0, 0, 0, 0, 0 }, { 0, 0, 0, 0, 0 }, { 13, 0, 0, 0, 0 }, { 0, 0, 0, 0, 0 }, { 0, 0, 0, 0, 0 } },    // Preset 0
    { { 0, 0, 0, 0, 0 }, { 0, 0, 0, 0, 0 }, { 0, 0, 0, 0, 0 }, { 0, 0, 0, 0, 0 }, { 0, 0, 0, 0, 0 }, { 0, 0, 0, 0, 0 }, { 0, 0, 0, 0, 0 }, { 13, 0, 0, 0, 0 }, { 0, 0, 0, 0, 0 }, { 0, 0, 0, 0, 0 } },    // Preset 1
    { { 0, 0, 0, 0, 0 }, { 0, 0, 0, 0, 0 }, { 0, 0, 0, 0, 0 }, { 0, 0, 0, 0, 0 }, { 0, 0, 0, 0, 0 }, { 0, 0, 0, 0, 0 }, { 0, 0, 0, 0, 0 }, { 13, 0, 0, 0, 0 }, { 0, 0, 0, 0, 0 }, { 0, 0, 0, 0, 0 } } };  // Preset 2


// Other misc. variables
unsigned long wakeTime = 0;        // When we woke from sleep
byte blinkNumber[] = { 0, 0, 0 };  // The number of time to blink LEDs R, G, B.
bool LEDon[] = { 0, 0, 0 };        // Whether each LED is currently on
bool play = 0;                     // Turns sound off and on (with the use of a button action) when in bagless preset.
byte program = 0;                  // Current MIDI program change value. This always starts at 0 but can be increased/decreased with assigned buttons.
bool dronesState = 0;              // Keeps track of whether we're above or below the pressure threshold for turning drones on.
bool pulseLED[] = { 0, 0, 0 };     // Whether currently pulsing LEDs

// Misc. timers used in loop()
unsigned long pitchBendTimer = 0;
unsigned long timerC = 0;
unsigned long timerD = 0;
unsigned long timerE = 0;
unsigned long timerF = 0;
unsigned long pressureTimer = 0;
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
void loop() {


    /////////// Things here happen ~ every 3 ms if connected to BLE and 2 ms otherwise.

    byte delayTime = calculateDelayTime();  // Figure out how long to sleep based on how much time has been consumed previously.
    delay(delayTime);                       // Put the NRF52840 in tickless sleep, saving power.
    wakeTime = millis();                    // When we woke from sleep.
    getSensors();                           // 240 us
    getFingers();                           // Find which holes are covered. 4 us.
    getState();                             // Get the breath state. 3 us.
    debounceFingerHoles();                  // Get the new MIDI note if the fingering has changed.
    getShift();                             // Shift the next note up or down based on register and key.
    sendNote();                             // Send the note as soon as we know the note, state, and shift.
    readMIDI();                             // Read incoming MIDI messages.



    /////////// Things here happen ~ every 2 to 17 ms.

    byte pressureInterval = calculatePressureInterval();  // Determine how frequently to send MIDI messages based on pressure.
    if ((wakeTime - pressureTimer) >= pressureInterval) {
        pressureTimer = wakeTime;
        calculateAndSendPressure();
    }



    /////////// Things here happen ~ every 5 ms. These are things that should happen at a regular rate regardless of connection but don't need to happen as fast as possible.

    if ((wakeTime - timerE) >= 5) {
        timerE = wakeTime;
        readIMU();          // Takes about 145 us using SensorFusion's Mahony.
        getRegisterHold();  // See if we need to lock in the current register to pause overblowing.
        blink();            // Blink any LED if necessary.
        pulse();            // Pulse any LED if necessary.
        calibrate();        // Calibrate/continue calibrating if the command has been received.
        checkButtons();
        detectSip();
        detectShake();               // Gesture detection
        sendToConfig(false, false);  // Check the queue and send to the Configuration Tool if it is time.
        updateBLEIntervalStatus();   // See if the BLE connection interval has changed.
    }



    /////////// Things here happen ~ every 9 ms (or 4 when legatoslidevibrato preset is used) if not connected to BLE or connected at a fast interval, and longer if connected at a slow interval.
    /////////// This ensures that we aren't sending pitchbend too much faster than the connection interval.
    const int pbsendinterval = (connIntvl > 8 && WARBL2settings[MIDI_DESTINATION] != 0) ? (12) : ((pitchBendModeSelector[preset] == kPitchBendLegatoSlideVibrato) ? 4 : 9);

    if ((wakeTime - pitchBendTimer) >= pbsendinterval) {
        pitchBendTimer = wakeTime;    // This timer is also reset when we send a note, so none if these things will happen until the next connection interval if using BLE.
        calculateAndSendPitchbend();  // 5 us with no pitchbend turned on, 50 us with vibrato, 65 us with slide/vibrato, 45 us with shake vibrato only, 30 us with half hole only, ~ 65 us with all of the above.
        printStuff();                 // Debug
        sendIMU();                    // ~ 130 us
    }



    /////////// Things here happen ~ every 50 ms.

    if ((wakeTime - timerC) > 50) {
        timerC = wakeTime;
        if (useBMP) {
            readAmbientPressure();  // Compensate for ambient pressure occasionally if using the Bosch pressure sensors.
        }
        sendDiagnosticData(false);  // Stream standalone diagnostic data when diagnostic mode is active.
    }



    /////////// Things here happen ~ every 0.75 s.

    if ((wakeTime - timerF) > 750) {  // This period was chosen for detection of a 1 Hz fault signal from the battery charger STAT pin.
        timerF = wakeTime;
        manageBattery(false);  // Check the battery and manage charging. Takes about 300 us because of reading the battery voltage.
        watchdogReset();       // Feed the watchdog.
    }

    // timerD = micros(); // For benchmarking--can paste these lines around any of the function calls above.
    // Serial.println(micros() - timerD);
}

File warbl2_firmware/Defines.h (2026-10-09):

//#define RELEASE  // Uncomment for release version (turns off CDC to make the device USB class compliant). Comment out to be able to print to the serial monitor.

#define VERSION 48  // Firmware version (without decimal point)
#define PATCH 0     // Firmware patch number
//#define PROTOTYPE46                 // Hardware -- version 46 uses older pinout without the expansion port or the ability to reprogram the ATmega. Comment this out for all later versions.
#define HARDWARE_REVISION 52        // Not currently used. Can be written to EEPROM 1992 to store revision number.
#define ATMEGA_FIRMWARE_VERSION 11  // Increment this when the ATmega firmware has changed to make sure the ATmega gets reprogrammed at startup.
#define WATCHDOG_TIMEOUT_SECS 10    // The timeout needs to be set longer than any task that might interrupt the loop().

#define DEBUG_CONFIG_TOOL 0
#define DEBUG_TRANSITION_FILTER 0

#define EEPROM_I2C_ADDRESS 0x50

#define DEBOUNCE_TIME 0.02                          // Button debounce time, in seconds
#define SAMPLE_FREQUENCY 200                        // Button sample frequency, in Hz
#define MAXIMUM (DEBOUNCE_TIME * SAMPLE_FREQUENCY)  // The integrator value required to register a button press

#define BATTERY_POWER 0  // No USB connected (running on battery power)
#define DUMB_CHARGER 1   // Powered by a USB charging brick
#define USB_HOST 2       // Connected to a USB host

// MIDI commands
#define NOTE_OFF 0x80          // 127
#define NOTE_ON 0x90           // 144
#define KEY_PRESSURE 0xA0      // 160
#define CONTROL_CHANGE 0xB0    // 176
#define PROGRAM_CHANGE 0xC0    // 192
#define CHANNEL_PRESSURE 0xD0  // 208
#define PITCH_BEND 0xE0        // 224

// Fingering Patterns
#define kModeWhistle 0
#define kModeUilleann 1
#define kModeGHB 2
#define kModeNorthumbrian 3
#define kModeChromatic 4
#define kModeGaita 5
#define kModeNAF 6
#define kModeKaval 7
#define kModeRecorder 8
#define kModeBansuri 9
#define kModeUilleannStandard 10
#define kModeXiao 11
#define kModeSax 12
#define kModeGaitaExtended 13
#define kModeSaxBasic 14
#define kModeEVI 15
#define kModeShakuhachi 16
#define kModeSackpipaMajor 17
#define kModeSackpipaMinor 18
#define kModeCustom 19  // From original WARBL -- Currently unused
#define kModeBombarde 20
#define kModeBaroqueFlute 21
#define kModeMedievalPipes 22
#define kModeEVI2 23
#define kModeEVI3 24
#define kModeRecorder2 25
#define kModeDuduk 26
#define kWARBL2Custom1 67
#define kWARBL2Custom2 68
#define kWARBL2Custom3 69
#define kWARBL2Custom4 70
#define kModeNModes 31

// Pitch bend modes
#define kPitchBendSlideVibrato 0
#define kPitchBendVibrato 1
#define kPitchBendNone 2
#define kPitchBendLegatoSlideVibrato 3
#define kPitchBendNModes 4

// Register control modes
#define kPressureSingle 0
#define kPressureBreath 1
#define kPressureThumb 2
#define kPressureBell 3
#define kPressureNModes 4

// Drones control mode
#define kNoDroneControl 0
#define kSecretDroneControl 1
#define kBaglessDroneControl 2
#define kPressureDroneControl 3
#define kDroneNModes 4

// Used in register state machine
#define SILENCE 1
#define BOTTOM_REGISTER 2
#define TOP_REGISTER 3
#define JUMP 0
#define DROP 1

// Variables in the switches array (settings for the swiches in the slide/vibrato and register control panels)
#define VENTED 0
#define BAGLESS 1
#define SECRET 2
#define INVERT 3
#define CUSTOM 4
#define SEND_VELOCITY 5
#define SEND_AFTERTOUCH 6  // Second bit of this one is used for poly.
#define FORCE_MAX_VELOCITY 7
#define IMMEDIATE_PB 8
#define LEGATO 9
#define OVERRIDE 10
#define THUMB_AND_OVERBLOW 11
#define R4_FLATTEN 12
#define BUTTON_DOUBLE_CLICK 13
#define kSWITCHESnVariables 14
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

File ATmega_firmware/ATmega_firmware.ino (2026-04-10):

/*
    The ATmega32U4 is dedicated to reading the WARBL tone hole sensors. It reads the sensors
     then goes to sleep. When wakened by a pin interrupt it
    sends all tone hole data by SPI and then repeats.

    To compile this firmware, use the Adafruit ItsyBitsy 32u4 board package.

    To allow the NRF52840 to automatically update the firmware on the ATmega, compile this code as hex and paste it into the ATmega_programming.ino tab in the WARBL2 firmware.

    Copyright (C) 2023 Andrew Mowry warbl.xyz

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
    You should have received a copy of the GNU General Public License
    along with this program.  If not, see http://www.gnu.org/licenses/
*/

#include <DIO2.h>             // Fast digitalWrite library used for toggling IR LEDs
#define GPIO2_PREFER_SPEED 1  // Digitalread speed, see: https://github.com/Locoduino/DIO2/blob/master/examples/standard_outputs/standard_outputs.ino
#include <avr/sleep.h>
#include <avr/power.h>
#include <SPI.h>

// GPIO constants
const volatile uint8_t holeTrans[] = { 0, 9, 8, 7, 11, 6, 4, 2, 1 };                      // The analog pins used for the tone hole phototransistors, in the following order: Bell,R4,R3,R2,R1,L3,L2,L1,Lthumb
const volatile GPIO_pin_t pins[] = { DP7, DP13, DP5, DP11, DP0, DP1, DP23, DP21, DP10 };  // The digital pins used for the tone hole leds, in the following order: Bell,R4,R3,R2,R1,L3,L2,L1,Lthumb. Uses a special declaration format for the GPIO library.

// Variables for reading tonehole sensors
int toneholeRead[] = { 0, 0, 0, 0, 0, 0, 0, 0, 0 };                       // Storage for tonehole sensor readings
int tempToneholeReadA[] = { 0, 0, 0, 0, 0, 0, 0, 0, 0 };                  // Temporary storage for ambient light tonehole sensor readings, written during the timer ISR.
volatile byte toneholePacked[] = { 0, 0, 0, 0, 0, 0, 0, 0, 0, 0, 0, 0 };  // We pack the 9 10-bit tonehole readings into 12 bytes to send via SPI to the NRF52840.
volatile bool useBellSensor = true;                                       // Whether we should read the bell sensor (not doing so helps conserve power).


void setup() {

    USBCON |= (1 << FRZCLK);  // Freeze the USB Clock.
    PLLCSR &= ~(1 << PLLE);   // Disable the USB Clock (PPL).
    USBCON &= ~(1 << USBE);   // Disable USB.

    // Disable other things we don't need, to save power. The ATmega32U4 iteslf consumes ~1.5 mA when awakened for a reading every 3 mS or ~1.8 when awakened very 2 ms.
    power_usb_disable();
    power_usart0_disable();
    power_timer0_disable();  // This disables millis()!! We don't want any timer ticks because they mess with SPI.
    power_timer1_disable();
    power_timer2_disable();
    power_timer3_disable();
    power_usart1_disable();

    DIDR0 = 0xff;  // Disable digital input circuits for analog pins.
    DIDR2 = 0xf3;

    for (byte i = 0; i < 9; i++) {  // Initialize the tonehole sensor IR LEDs.
        pinMode2f(pins[i], OUTPUT);
    }

    ADC_init();  // Initialize the ADC. The first set of readings will be all zeros because we won't start reading sensors until the first SPI request is received.

    // Turn on SPI in peripheral mode.
    SPCR |= bit(SPE);
    pinMode(MISO, OUTPUT);
    SPI.attachInterrupt();
    pinMode(3, INPUT_PULLUP);
    attachInterrupt(0, pinFall, FALLING);  // This pin is tied to CS and wakes us up from Standby mode (digital pin 3).
}




void pinFall() {
    sleep_disable();  // Disable sleep after waking.
    SPDR = 0xff;      // Preload the SPI buffer with a verification byte.
}




void loop() {

    // Sleep after getting and preparing the readings.
    set_sleep_mode(SLEEP_MODE_STANDBY);
    cli();                // Turn off interrupts.
    power_adc_disable();  // Turn off the ADC to save a little more power.
    sleep_enable();
    sei();  // Turn on interrupts immediately before sleeping.
    sleep_cpu();

    // sleeping__________________________________
    // Wake and enter SPI interrupt.

    while (digitalRead(SS) == LOW) {}  // Make sure the SPI transfer is done before proceeding.

    power_adc_enable();

    readSensors();
}




// SPI interrupt routine
ISR(SPI_STC_vect) {
    byte c = SPDR;  // Read request from NRF52840.
    if (c < 12) {
        SPDR = toneholePacked[c];  // Send requested byte to the NRF52840.
    } else if (c == 20) {
        useBellSensor = false;  // Don't use bell sensor.
    } else if (c == 21) {
        useBellSensor = true;  // Use bell sensor.
    }
}




EMPTY_INTERRUPT(ADC_vect);  // We're not using the ADC complete interrupt.




// With bell sensor on, it takes 830 us to read all sensors and prepare the data. The total time that IR LEDs are on is 800 us, so power consumed by sensors is: 800 uS/3000 us * 13mA/LED == 3.5 mA when polled every 3 ms.
void readSensors(void) {

    if (useBellSensor) {
        digitalWrite2f(pins[0], HIGH);  // Turn on LED 0. If we can skip this step we save ~0.7 mA.
        ADC_read(holeTrans[0]);         // Throwaway to give sensor 0 extra time to rise after turning on LED (it's a slower sensor).
    }
    tempToneholeReadA[1] = ADC_read(holeTrans[1]);                    // Get ambient reading for sensor 1.
    toneholeRead[0] = ADC_read(holeTrans[0]) - tempToneholeReadA[0];  // Get illuminated reading for 0 and subtract previously measured ambient reading.
    if (!useBellSensor) {
        toneholeRead[0] = 0;  // Make sure it's 0 if we're not using the bell sensor.
    }
    digitalWrite2f(pins[0], LOW);   // Turn off LED 0.
    digitalWrite2f(pins[1], HIGH);  // Turn on LED 1.

    tempToneholeReadA[2] = ADC_read(holeTrans[2]);  // etc.
    toneholeRead[1] = ADC_read(holeTrans[1]) - tempToneholeReadA[1];
    digitalWrite2f(pins[1], LOW);
    digitalWrite2f(pins[2], HIGH);

    tempToneholeReadA[3] = ADC_read(holeTrans[3]);
    toneholeRead[2] = ADC_read(holeTrans[2]) - tempToneholeReadA[2];
    digitalWrite2f(pins[2], LOW);
    digitalWrite2f(pins[3], HIGH);

    tempToneholeReadA[4] = ADC_read(holeTrans[4]);
    toneholeRead[3] = ADC_read(holeTrans[3]) - tempToneholeReadA[3];
    digitalWrite2f(pins[3], LOW);
    digitalWrite2f(pins[4], HIGH);

    tempToneholeReadA[5] = ADC_read(holeTrans[5]);
    toneholeRead[4] = ADC_read(holeTrans[4]) - tempToneholeReadA[4];
    digitalWrite2f(pins[4], LOW);
    digitalWrite2f(pins[5], HIGH);

    tempToneholeReadA[6] = ADC_read(holeTrans[6]);
    toneholeRead[5] = ADC_read(holeTrans[5]) - tempToneholeReadA[5];
    digitalWrite2f(pins[5], LOW);
    digitalWrite2f(pins[6], HIGH);

    tempToneholeReadA[7] = ADC_read(holeTrans[7]);
    toneholeRead[6] = ADC_read(holeTrans[6]) - tempToneholeReadA[6];
    digitalWrite2f(pins[6], LOW);
    digitalWrite2f(pins[7], HIGH);

    tempToneholeReadA[8] = ADC_read(holeTrans[8]);
    toneholeRead[7] = ADC_read(holeTrans[7]) - tempToneholeReadA[7];
    digitalWrite2f(pins[7], LOW);
    digitalWrite2f(pins[8], HIGH);
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

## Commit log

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2023-07-25 Experimenting with IMU a bit
    Increased data rate and added simple complementary filter.
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2023-07-25 Fixed bug in custom fingering chart
    [Functions.ino]
2023-07-26 Fixed pressure interval
    Now uses the old settings unless that makes it lower than the connection interval.
    [Functions.ino, warbl2_firmware.ino]
2023-07-28 added new dependency imuFilter for fusion... uncomment serial debug for testing with arduino serial plotter
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2023-08-02 prevent redundant IMU CC event sending
    [Functions.ino, warbl2_firmware.ino]
2023-08-02 Misc. IMU changes
    Added ability to invert output
    Added a roll transformation
    [Functions.ino, warbl2_firmware.ino]
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2023-08-03 Update Battery_management.ino
    Fixed a few errors
    [Battery_management.ino]
2023-08-03 Update Battery_management.ino
    A few more fixes
    [Battery_management.ino]
2023-08-03 Ugh, more battery fixes
    [Battery_management.ino]
2023-09-15 fixed up shake vibrato to respect pitch bend range, and also to automatically activate so that the values close to 0 can still be smooth while shaking is active.
    [Functions.ino]
2023-09-15 Added vibrato depth slider and fixed bug.
    [Functions.ino, warbl2_firmware.ino]
2023-09-15 added shake vibrato triggering on zero crossing for cleaner starts... but the feel is ever so slightly less responsive. experiment with commenting out noted line to compare. most obvious when doing s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
    [Functions.ino]
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2023-09-21 Added auto-centering for yaw
    Yaw recenters automatically at the start of a note if there has been a pause of sufficient length.
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2023-09-25 Fixed overblowing with custom charts
    [Functions.ino]
2023-09-27 Changed pressure calculations to use 12-bit pressure.
    I can't decide if this makes a difference-- mapping a low pressure range to CC has always produced "grainy" -sounding results for me, so I though higher res might help.
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2023-09-27 More pressure fixes
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2023-09-29 More pressure stuff
    Made it so that the zero pressure for mapping corresponds to the note trigger pressure.
2023-10-01 Turned off IMU if we're not using it.
    Turning off the gyro saves ~ 0.5 mA.
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2023-10-05 Fixed some things with restoring factory settings.
    Note: After this update you'll need to calibrate the gyro again.
    [Battery_management.ino, Functions.ino, warbl2_firmware.ino]
2023-10-05 Another factory settings fix
    [Functions.ino, warbl2_firmware.ino]
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2023-10-08 Added adaptive smoothing for the analog pressure using ResponsiveAnalogRead arduino library. Now even the smoothed value changes quickly when needed, but smooths when it isn't changing quickly. This 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
2023-10-11 More battery changes
    Also turned IMU back on full time for now to make it easier to experiment with it.
2023-10-13 Cleanup and fixed saving factory settings
    [Functions.ino, warbl2_firmware.ino]
2023-10-16 added boards.local.txt which can be copied into the ~/LibaryArduino15/packages/adafruit/hardware/nrf52/1.5.0/ on Mac (or similar on windows)
2023-10-18 Added watchdog timer (but disabled it for now)
    Added watchdog to recover from hangs, but haven't enabled because it would be nice to know when the happen. The reset button can always be used to recover (it will shut down the device if on battery 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
2023-10-18 Added experimental "register nudge"
    Can nudge the register up or down using the X gyro. Works, but I think mapping pitch to register will be better.
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2023-10-21 Commented out lowpass in shake vibrato
    [Functions.ino]
2023-10-22 Reducd the time constant for the high pass in the shake vibrato
    [Functions.ino]
2023-10-23 went the other way with the shake vibrato filter, so that a slower vibrato is possible. put second low-pass back to smooth finger hole impacts
    [Functions.ino]
2023-10-24 added shake vibrato mode option to firmware and webconfig
    [Functions.ino, warbl2_firmware.ino]
2023-10-25 Fixed bug where switching to instrument 3 might cause hang
    Also added function to slowly pulse LEDS
    [Battery_management.ino, Functions.ino, warbl2_firmware.ino]
2023-10-25 LED pulse fix
2023-10-26 Other fixes to ATmega programming
    [ATmega_programming.ino, warbl2_firmware.ino]
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2023-10-27 Removed Sparkfun EEPROM library
    The library kept getting broken so I wrote functions to replace it.
    [ATmega_programming.ino, Battery_management.ino, Functions.ino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]
2023-10-27 Fixed bug
    Momentary switch settings weren't always being sent to WARBL
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2023-10-31 Big changes to EEPROM locations...
    ...to make sure there's plenty of room for expansion later. This update will restore factory settings but should retain calibrations and battery data.
2023-10-31 Updated Config Tool
    Added "sip" and "shake" behavior to buttons pane, also indication for when buttons/gestures happen.
2023-10-31 Fixed mistake moving battery data to new location.
    [Functions.ino, warbl2_firmware.ino]
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2023-11-01 Fixed mistake where shake pitchbend was always on
    [Functions.ino, warbl2_firmware.ino]
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2023-11-03 Fixed ATmega fuse verification
    [ATmega_programming.ino, warbl2_firmware.ino]
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2023-12-03 improved Slide functionality so that any partial hole fingering changes (not just the one 'slideHole') that would cause a pitch change can be slid. A new Slide Limit parameter added to limit the max 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
2023-12-04 fixed scaling precision issues by changing to floats for toneholeScale and vibratoScale. fixed finger customVibrato and normalVibrato issues.
    [Functions.ino, warbl2_firmware.ino]
2023-12-06 Fixed mistake calculating scalePosition
    [Functions.ino]
2023-12-09 Added PCB design
    [WARBL2_4.8.csv, WARBL2_4.8.kicad_pcb, WARBL2_4.8.kicad_sch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]
2024-02-12 Added functionality for new prototype 4.8
    Also added notes for expansion port and ability to assign a button action to displaying battery life.
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2024-02-19 Reworked fingering charts and added note readout to Config
    [Fingering_Charts.ino, Functions.ino, warbl2_firmware.ino]
2024-04-25 Fixed IMU calibration to give gyro time to turn on
    [Functions.ino]
2024-04-25 Updated PCB
    [Pressure_Sensor_subassembly2.kicad_pcb, Pressure_Sensor_subassembly2.kicad_sch, WARBL2_4.8.csv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]
2024-05-20 Update warbl2_firmware.ino
    Starting watchdog at beginning of setup in case anything goes wrong initializing peripherals.
    [warbl2_firmware.ino]
2024-05-27 Reset the ATmega at startup in case only the NRF52840 has been reset.
    [Defines.h, Functions.ino, warbl2_firmware.ino]
2024-06-04 Increased WDT to 10 seconds in case we need to program the ATmega
2024-06-13 Changed all digitalWrites for LEDs to analogWrites
    ...turns out you can't ever use digitalWrite after analogWrite with this board package.
2024-06-17 Misc. fixes
    0xFF is now used as an "error" code if getNote() fails to find a note in the lookup tables.
    [Battery_management.ino, Functions.ino, warbl2_firmware.ino]
2024-06-26 Update Functions.ino
    Fixed for loop in loadCalibration
    [Functions.ino]
2024-06-26 Update Functions.ino
    Fixed loadCalibration
    [Functions.ino]
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2024-06-29 20240629 - Double Click Button Action - fixes
    [Defines.h, Functions.ino]
2024-06-30 20240630 - USB/BLE Coexistence in Config Tool
    We keep track of which transport is used to enter communication mode and be consistent with it, avoiding doubled messages.
    Also, proper double messages are now sent without any possibile interruption (sendMidiCouplet())
    [Battery_management.ino, Defines.h, Functions.ino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]
2024-07-01 Minox fix in comment
    [Functions.ino]
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2024-07-01 Fixed MIDI channel mask
    [Functions.ino]
2024-07-06 Without parenthesis, sendSettings doesn't work properly
    [Defines.h]
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2024-07-07 Fix MIDI Library 5.0.2 Compatibility
    [warbl2_firmware.ino]
2024-07-08 Added version manager from @MrMep and various minor fixes
    [Battery_management.ino, Defines.h, Functions.ino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]
2024-07-30 Fixed Gaita note and closed pipe behavior
    [Fingering_Charts.ino, Functions.ino]
2024-07-30 Some fixes to pitch expression
    The pitch range wasn't centered on the halfway pressure.
    Also am sending battery data to the Config Tool more frequently. I'm now using this to tell the Config Tool that the WARBL2 is still connected, because statechange over BLE isn't a reliable way to disconnect.
    [Battery_management.ino, Defines.h, Functions.ino]
2024-07-30 More fixes to pitch expression
    [Functions.ino]
2024-08-14 Fixed bug where note wasn't recalculated after a fingering chart change until the fingering pattern had changed.
    [Functions.ino]
2024-08-23 Enabled momentary button behavior for CC
    If momentary switch is turned on, the button will send a CC with a value of 0 when released, for controlling CC switches, e.g. CC64-69.
2024-09-16 Reworked of connection logic, adding support for manual device select, which lets you switch easily between multiple connected WARBLs and ensure only the selected one is used
2024-09-16 fixes for app config version... doesnt support the manual device choosing for now
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2024-09-23 refinements to pitch expression override defaults. added reset to default command
    [Defines.h, Functions.ino, warbl2_firmware.ino]
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2024-09-23 added support for new non-override pitch expression. added notion of center pressure to it. updated webconfig too.
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2024-09-23 hide center pressure slider on older firmware. changed OK to BACK in some cases
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2024-09-25 moved new pitch expression param init to firmware check area. added support for IMU shake output pressure feature. added support for MPE+ 14 bit channel pressure output option
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2024-09-26 added shake pressure mod mode, and fixed up update interval issue for it
    [Defines.h, Functions.ino, warbl2_firmware.ino]
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2024-09-26 fixed visibility of shake pressure mod for old firmwares
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2024-10-26 fix up baseline and covered hole calibration issues to be adapt to more variety in fingerhole situations. updated firmware version to 44.
    [Defines.h, Functions.ino]
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2024-10-26 added caloffset used during calibration only for tonehole bits... so that the webconfig lights match future reality
2024-10-28 A few fixes to new calibration
    [Defines.h, Functions.ino, warbl2_firmware.ino]
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2024-11-06 Changed IMU pitchbend defaults, clamping, misc fixes
    [ATmega_programming.ino, Functions.ino, warbl2_firmware.ino]
2024-11-22 prevented IMU shake pressure mod from being used if input pressure is zero. This prevents shaking sented unwanted messages when no blowing is even occurring
    [Functions.ino]
2024-11-22 Fixed uilleann "custom" vibrato
    [Defines.h, Fingering_Charts.ino]
2024-12-31 More fixes to preset import/export
    [Functions.ino]
2025-03-03 Fixed bug where IMU pitchbend wasn't being turned off with switch
    Pitchbend of zero wasn't being sent after turning off IMU pitchbend.
    [Functions.ino, warbl2_firmware.ino]
2025-03-21 Experimental halfhole pitchbend snap added
    Note, this feature is currently *turned on* by default. There are constants in the getHalfholePitchbend(byte i) function that can be tweaked but no controls have been added to the Config Tool. The halfhole pitchbend works with or without all other pitchbend features (slide, etc.).
    [Defines.h, Functions.ino, warbl2_firmware.ino]
2025-03-26 Fixed bug in halfhole pitchbend
    [Functions.ino]
2025-03-27 Added transverse mouthpiece
    [WARBL_transverse_mouthpiece_1.0.stl, WARBL_transverse_mouthpiece_2.0.stl]
2025-03-30 Fixed comments related to Bansuri
    [Defines.h, Fingering_Charts.ino, Functions.ino]
2025-08-08 Create WARBL_mouthpiece_9.0_mm.stl
    This version is the same but with larger internal passages to aid in clearing MJF powder.
    [WARBL_mouthpiece_9.0_mm.stl]
2025-08-09 fixed lack of hysteresis in half holing because of missing initialization state of inTargetRegion
    [Functions.ino]
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2025-08-11 refinements to hysteresis edge cases on half-holing. added responsive filtering to tonehole raw sensor readings, which cleans up slide, esp with half-holing, doesnt seem to affect responsiveness or a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
2025-08-11 Fixed thumb register order
    [Defines.h, Functions.ino]
2025-08-12 Fixed bug in half hole
    - Finger rate was being ignored if slide was turned on and "use MIDI Note" was also turned on or the thumb was being used for register.
    - Set mininum values of half hole sliders to 1 to avoid confusion because setting any of them to 0 disabled slide all together.
    [Functions.ino]
2025-09-08 Halfhole fix
    The finger rate wasn't being calculated correctly when the finger was first removed from a covered hole.
    [Defines.h, Functions.ino, warbl2_firmware.ino]
2025-09-18 Fixed a bug where neither "Sip Mouthpiece" nor "Shake" were correctly able to send MIDI messages
    [Defines.h, Functions.ino]
2025-11-13 Added end cap
    [WARBL2_end_cap.stl, WARBL2_end_cap.stp]
2025-11-13 Removed older mouthpiece design
    [WARBL_mouthpiece_8.0_mm.stl]
2026-01-14 Added enclosure DXF
    And a few fixes to comments
    [WARBL2 enclosure.dxf]
2026-03-07 Yaw is now the compass direction in which the long-axis of the WARBL is pointing
    ...this isolates yaw from roll so it is much more useful. Also other minor fixes.
    [Defines.h, Functions.ino, warbl2_firmware.ino]
2026-03-09 More IMU fixes
    Added a scale factor for roll and yaw because gyro scaling seems to be off (possibly wrong scale factor in the LSM6D library?)
    [Defines.h, Functions.ino]
2026-03-09 Updated transverse mouthpiece
    [WARBL_transverse_mouthpiece_2.0.stl, WARBL_transverse_mouthpiece_3.0.stl]
2026-03-09 Fixed longstanding bug with buttons and momentary mode
    [Functions.ino]
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2026-03-11 Improved ability for 3rd MIDI device to change presets
    ...by PC messages or CC messages
2026-03-11 Added thumbrest
    [WARBL_thumbrest_1.0.stl]
2026-03-12 Fixed BLE connection interval
    Connection interval was being calculated wrong, and also was not being checked again after renegotiation. Also added another request after a delay to try to force renegotiation from iOS. The Config Tool may show a higher connection interval now in some cases but this is because it was previously calculated incorrectly.
    [Defines.h, Functions.ino, warbl2_firmware.ino]
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2026-04-08 Various fixes
    Thumb half-holing,
    SPI behavior
    [ATmega_firmware.ino, ATmega_programming.ino, Defines.h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]
2026-04-10 Switched to SPIM2
    It seems more reliable but requires a modification to SPI.cpp.
2026-04-21 Synth pitch bend fix
2026-04-22 Another half hole fix
    Sending MIDI note instead of pitch bend while half-holing wasn't working with legato slide mode.
    [Functions.ino]
2026-04-22 Synced bend range in the new synth with bend range in the current preset
2026-04-23 Fix to bell sensor control
    [Functions.ino]
2026-04-24 Finally fixed iOS app crashing on pinch zoom
    This has happened forever and it turned out to be the modal overlays, which were set to opacity: 0 instead of being hidden.
    Also improved autoconnect behavior so it keeps trying for several seconds in case the ports are slow to open.
    Also removed the pressure graph because it required a lot of code and I'm not sure it was being used.
2026-04-27 Fixes to modal behavior
    [Functions.ino]
2026-04-27 Fixed legato slide bug
    [Functions.ino]
2026-04-30 Fixed another legato slide bug
    A new note wasn't being triggered until sliding too far past the legato slide limit.
    [Functions.ino]
2026-05-08 Made it easier to tap the volume controls in Config
    Also started adding magnetometer support.
2026-05-15 Added magnetometer support and then rolled it back...
    It turned out there was a large bug in the IMU fusion: The library uses micros() to calculate deltaT for gyro integration, but micros() undercounts by about 25% when it spans tickless sleep (every loop). That has been causing serious drift. After fixing that, I decided that a magnetometer isn't necessary because drift is minimal now.
    [Defines.h, Functions.ino, warbl2_firmware.ino]
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2026-05-18 Another IMU timing fix
    Using RTC2 for deltat for better accuracy.
    [Functions.ino, warbl2_firmware.ino]
2026-05-29 fixed subtle issue with how legato slide was designed to operate. Also fixed getSensors for the prototype46 models.
    It only retriggers a new note if the bend range was going to be exceeded, otherwise the slide limit just prevents continous bends on intervals >= the set limit (quantizing them to the actual note)
    [Functions.ino]
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2026-06-03 Sensor calibration fixes
2026-06-04 Fix to tiny console in Config Tool
    [Functions.ino]
2026-06-05 use roll in local frame, finally found the right math! Turn off gyro if necessary in config. added IMU calibration reset (unused yet)
    [Functions.ino]
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2026-06-16 minor reorder duduk webconfig fix
    [Defines.h]
2026-06-16 missed a few things with fingering added
    [Defines.h]
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2026-08-06 Added support for Bosch pressure sensors.
    BMP585 for breath and BM580/581 for ambient pressure.
    This results in around 1/3 noise, lower power consumption, much higher range (positive and negative) and lower cost.
    [Defines.h, Functions.ino, warbl2_firmware.ino]
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

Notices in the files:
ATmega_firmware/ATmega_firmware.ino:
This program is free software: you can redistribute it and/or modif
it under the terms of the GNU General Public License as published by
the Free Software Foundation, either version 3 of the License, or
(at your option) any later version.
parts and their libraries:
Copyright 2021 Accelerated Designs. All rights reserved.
